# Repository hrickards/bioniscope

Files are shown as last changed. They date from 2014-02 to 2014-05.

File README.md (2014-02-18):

# Bioniscope

Open-source Bluetooth oscilloscope with an Android UI.
More information coming soon.

The project was undertaken for my A-Level Electronics coursework, so things like the writeup had to meet a certain specification and are hence pretty funky.

 * **app** --- the Android app
 * **circuit** --- Diptrace (with images & gebers) files for the circuit & PCB
 * **datasheets** --- PDF datasheets of the ICs used
 * **enclosure** --- OpenSCAD laser-cut enclosure
 * **experiments** --- brief experiments done to e.g., determine existing scope accuracies
 * **research** --- various bits of saved research into things like scope triggering
 * **simulations** --- LTSpice simulations of various parts of the circuit
 * **writeup** --- the project report needed for the A-Level

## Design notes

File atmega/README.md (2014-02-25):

# Fuses
To get a 16MHz clock using an external crystal, use CKSEL=1111, SUT=111.

To enable communication with the ADC: JTAG must be disabled! So set JTAGEN=0.

See [here](http://www.engbedded.com/fusecalc) for a great fuse calculator. The values I ended up with were L:FF, H:D9, E:FF.

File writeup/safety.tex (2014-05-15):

\documentclass[12pt,a4paper]{report}

% Custom styles
\usepackage{electronics}

% Bibliography
\usepackage[citestyle=authortitle,url=true]{biblatex}
\addbibresource{electronics.bib}

\begin{document}

When constructing the system, it is vital that all practical work is carried out
sfaely. To that end, precautions were taken against the following risks:

\begin{description}
  \item[Electrocution] No high voltage/current power supplies will be used (the
  highest voltage that may possibly be used will be \SI{15}{\volt}) so the
  danger is relatively low. Even so, appropriate precautions will be taken: the
  circuit will not be touched or modified when switched on and will not be
  placed near liquids.

  \item[Electrostatic damage] Many of the components used utilise CMOS
  technology so are very sensitive to electrostatic discharge. To minimise the
  risk of this happening, I will ground myself on a suitable surface (computer
  power supply case, grounded radiator, etc) before approaching the circuit.

  \item[Fire and/or burns] A number of components (e.g., the power supply diodes
  and chips) could potentially get extremely hot if misused. While I will
  obviously aim not to misuse them, accidents happen, and to this extent I will
  be careful and slow in touching any component in case it is hot enough to
  burn. Also, I will ensure no paper or other easily flammable materials are
  placed near the circuit.

  \item[Back injury] A number of components will need to be ordered from the
  internet, meaning they will come in large boxes. I will need to use proper
  lifting techniques when bending down and lifting these boxes to avoid back
  injury.

  \item[Cutting injuries] Throughout the course of the project I will be using
  various sharp tools, such as wire cutters. I will need to make sure I am
  trained in using these tools, that I concentrate when using them and that I
  leave them in a safe place so others do not accidentally injure themselves.
  These actions will help to reduce the risk of injuries.
\end{description}

\end{document}

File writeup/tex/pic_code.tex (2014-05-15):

\chapter{PIC Code}
\label{sec:picProgramCode}

\inputminted{c}{code/main.c} \newpage
\inputminted{c}{code/Global.c} \newpage
\inputminted{c}{code/Command.c} \newpage
\inputminted{c}{code/Debugger.c} \newpage
\inputminted{c}{code/BTUSART.c} \newpage
\inputminted{c}{code/USBUSART.c} \newpage
\inputminted{c}{code/Sampler.c} \newpage
\inputminted{c}{code/ADC.c} \newpage
\inputminted{c}{code/Pots.c} \newpage
\inputminted{c}{code/SPI.c} \newpage

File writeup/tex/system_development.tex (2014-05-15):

\chapter{System Development}
\section{Subsystems}
\label{sec:subsystems}

The system will be split up into a number of subsystems, shown
in~\cref{fig:subsystems}. Each of these subsystems is described in more detail
in the sections below, and a brief description is given immediately below.

\begin{itemize}

  \item Two analogue input channels come into the system, and are amplified and
  offset by amplification circuitry (with the gain controlled by a central
  microcontroller).

  \item These channels are both sampled using an Analogue to Digital Converter,
  which feeds into the microcontroller.

  \item A number of digital inputs are also fed straight into the
  microcontroller

  \item Through a Bluetooth transceiver, an Android device interacts with the
  microcontroller, receiving samples of both the analogue and digital inputs and
  controlling things such as the sampling rate and amplifier gain.

\end{itemize}

\begin{landscape}
  \begin{figure}
    \scalebox{0.8}{
      \begin{tikzpicture}
        \node [io] (input1) {Input 1};
        \node [io, below of=input1, node distance=3cm] (input2) {Input 2};

        \node [process, right of=input1] (amp1) {Amplifier};
        \node [process, right of=input2] (amp2) {Amplifier};
        \path [arrow] (input1) -- (amp1);
        \path [arrow] (input2) -- (amp2);
        \coordinate [below of=amp1, node distance=1.5cm] (centreamp);

        \node [process, right of=centreamp] (adc) {ADC};
        \path [arrow] (amp1) -| (adc);
        \path [arrow] (amp2) -| (adc);

        \node [process, right of=adc] (microcontroller) {Microcontroller};
        \path [barrow] (adc) -- (microcontroller);

        \node [process, below=2.5cm of microcontroller.320] (inputdigital) {Digital Inputs};
        \path [arrow] (inputdigital) -- (microcontroller.320);

        \node [process, right of=microcontroller] (wifi) {Bluetooth Transceiver};
        \node [io, right of=wifi, node distance=5.5cm, text width=4.5em] (frontend) {User Interface};
        \path [barrow] (microcontroller) -- (wifi);
        \path [bdarrow] (wifi) -- (frontend);

        \coordinate[above of=amp1, node distance=2cm] (aboveamp1);
        \coordinate[below of=amp2, node distance=1.5cm] (belowamp2);
        \path [arrow] (microcontroller) |- (aboveamp1) -- (amp1);
        \path [arrow] (microcontroller.220) |- (belowamp2) -- (amp2);
      \end{tikzpicture}
    }
    \caption[Oscilloscope Subsystems]{Subsystems within the oscilloscope}
    \label{fig:subsystems}
  \end{figure}
\end{landscape}

\subsection{Analogue Inputs}

For the purposes of this project wires are sufficient, however in a real-life
scenario high-impedance, low-inductance test probes (usually coaxial cable)
should be used.

\subsection{Power Supply}

\subsubsection*{Requirements}

While it is not explicitly shown in~\cref{fig:subsystems}, the amplifiers, ADC,
microcontroller and Bluetooth transceiver will all need to be powered.

A \SI{5}{\V} rail will be needed that can source the following
current\footnote{The figures are overestimations meaning there will
definitely be enough current available.}:
\begin{itemize}
  \item \SI{5}{\mA} for the two amplifiers combined
  \item \SI{5}{\mA} for the two digital potentiometers combined
  \item \SI{15}{\mA} for the ADC
  \item \SI{25}{\mA} for the microcontroller
  \item \SI{30}{\mA} for the LED
  \item \SI{30}{\mA} for the Bluetooth module
\end{itemize}
which gives a total of \SI{110}{\mA}.

Similarly, a \SI{-5}{\V} rail will be needed for the first-stage amplifier that
can sink at least \SI{5}{\mA}, and a ground rail will be needed that can sink
at least \SI{110}{\mA}\footnote{There will always be a positive load, so we do
  not need to worry about the ground rail being able to source the \SI{5}{\mA}
that will flow to the \SI{-5}{\V} rail}.

\subsubsection*{Circuit}

While researching this part of the circuit, your author came upon a chip known
as an \textit{inverting charge pump}, a device that takes $V_s$ and \SI{0}{\V}
as inputs and outputs $-V_s$ and \SI{0}{\V} as outputs\footnote{The way it does
this is complicated, but revolves around charging up a capacitor in one
direction and then discharging it in the opposite direction.} --- essentially
providing a low-current\footnote{The highest commonly-available current rating
seems to be about \SI{1}{\A}} dual power supply. This was implemented into the
oscilloscope's power supply as it means only a positive voltage and ground need
to be input, meaning it could potentially be powered by battery.

Many of the chips (primarily the ADC and microcontroller) require very precise
and stable power rails, and to that effect a voltage regulator will be used.
Commonly known as a 7805 (although that specific device will not be used in this
case), a voltage regulator takes a relatively high voltage (e.g., \SI{9}{\V}) as
input and outputs a very precise lower voltage (e.g., \SI{5}{\V}) that does not
fluctuate even when the output current changes rapidly. In addition to this,
decoupling capacitors will be added to the amplifier, ADC and microcontroller to
further reduce voltage fluctuations (the capacitor values will be taken directly
from the relevant datasheets).

\begin{landscape}
  \begin{figure}[h]
    
    \caption{Power supply circuit diagram}
    \label{fig:powerSupplyDiagram}
  \end{figure}
\end{landscape}

These two ideas, then, give rise to the circuit diagram shown
in~\cref{fig:powerSupplyDiagram}. A single-rail power supply (perhaps from a
\SI{9}{\V} battery) is used to power the system, and a switch (to let the user
switch the oscilloscope off and on) and a forward-biased diode (to limit damage
if the power supply is connected backwards) are connected immediately to the
power rail.

A MAX883 chip is then used as a fixed \SI{5}{\V} voltage regulator. Most
semiconductor companies produce PDIP package \SI{5}{\V} voltage regulators, but
Maxim Integrated's chip was chosen due the availability of free samples. As
specified in the datasheet, a \SI{100}{\nF} capacitor is placed on the input and
a \SI{2.2}{\uF} capacitor on the output.

A MAX660 is then used as an inverting charge pump (this specific chip was chosen
for similar reasons to the MAX883). Again, as specified on the datasheet a
\SI{22}{\uF} capacitor is placed on the output and another between $CAP-$ and
$CAP+$.

\subsection{Amplifiers}

Each amplifier will have two purposes:
\begin{itemize}
  \item To amplify the signal based on the Voltage Control of the oscilloscope.
    This is needed so the user can input a range of different voltage signals.

  \item To shift the signal so the minimum voltage is \SI{0}{\volt}, rather
    than some negative voltage. This is required because the ADC will only
    accept an input greater than \SI{0}{\volt}.
\end{itemize}

The chosen ADCs require an input voltage between \SI{0}{\volt} and
\SI{5}{\volt}\footnote{The maximum voltage is actually $V_{REF+}$, which will be
connected to $V_{CC}$ for simplicity, which in this case is \SI{5}{\volt}}. A
non-inverting summing amplifier would not be suitable beause the offset added to
the signal needs to remain constant while the gain changes, so instead the
amplifier will be split into two stages.

The first stage will amplify the signal and offset it to be between
\SI{0}{\volt} and \SI{-5}{\volt}, below which the op-amp will saturate.

The second stage will invert this signal with a voltage gain of $-1$, meaning
the output voltage will be between \SI{0}{\volt} and \SI{5}{\volt} as required.

\subsubsection{First Stage}

\paragraph{Circuit}
This stage will be implemented using a summing amplifier, with the inputs
consisting of the input signal and a fixed voltage (for the sake of simplicity,
the 5V supply wil be used).

See~\cref{fig:first_stage_amplifier_circuit} for a circuit diagram.

\paragraph{Component Calculations}

Suppose that the input signal varies from $-V_1$ to $+V_1$, and the amplifier
has a gain of $A$ and an offset of $B$. Then the output voltage $V_o$ will be
given by

\begin{equation*}
  -V_o = \frac{R_f}{R_1} V_i + \frac{R_f}{R_2} \cdot \SI{5}{\volt}
\end{equation*}

The first term will range from $-A\cdot V_1$ to $+A\cdot V_1$, and the second
term will be $B$. So $-V_o$ will range from $B-A\cdot V_1$ to $B+A\cdot V_1$.
Choosing a value of $B=\SI{2.5}{\volt}$ means that $-V_o$ will vary equally
above and below \SI{2.5}{\volt}, as we want\footnote{The op amp will saturate
before outputting a voltage above \SI{5}{\volt}, so we don't need to worry about
this. If the gain or input voltage is sufficiently large, $-V_o$ could fall
below \SI{0}{\volt}. This means the next stage must saturate at $\SI{0}{\volt}$
and not output negative voltages, whatever the input.  }(because the voltage
must be between \SI{0}{\volt} and \SI{5}{\volt}, and \SI{2.5}{\volt} is the
midpoint of those two).

$R_f$ and $R_2$ will be fixed to give $\frac{R_f}{R_2}=0.5$ to get the required
offset. $R_1$ will be a digital potentiometer acting as a rheostate (variable
resistor), allowing the microcontroller to control the gain of the amplifier.

The input voltage range is from \SI{\pm 50}{\mV} to \SI{\pm 5}{\V}, so the gain
$A=\frac{R_f}{R_1}$ must vary from 0.5 to at least 50.  Digital potentiometers
are readily available in a number of values, so the standard \SI{10}{\kilo\ohm}
option will be chosen. This means the potentiometer can vary from the minimum
resistance (usually \SI{75}{\ohm}) to \SI{10}{\kilo\ohm}.

Using the values for $A$ and $R_1$, this gives a value of
$R_f=\SI{5}{\kilo\ohm}$, meaning $A$ will range from
$\frac{\SI{5}{\kilo\ohm}}{\SI{10}{\kilo\ohm}}=0.5$ to
$\frac{\SI{5}{\kilo\ohm}}{\SI{75}{\ohm}} \approx 66.7$, as required.  In turn,
this gives a value of $R_2 = \SI{10}{\kilo\ohm}$.

\begin{figure}[ht]
  \begin{circuitikz}[european]
    % Inputs and input resistors
    \node (vin1) {};
    \node (vin2) [below=1 of vin1] {};
    \node (rpoint1) [right=2.5 of vin1] {};
    \node (rpoint2) [right=2.5 of vin2] {};
    \coordinate (middlevin1vin2) at ($(vin1)!0.5!(vin2)$);
    \node (rpoint) at (rpoint1|- middlevin1vin2) {};

    \draw (vin1) to[R, l=$R_2\equal\SI{10}{\kilo\ohm}$] (rpoint1);
    \draw (rpoint2) to[pR, l_=$R_1 \in \lb\SI{75}{\ohm}\comma
    \SI{10}{\kilo\ohm}\rb$, label/align=rotate, -o] (vin2) node [anchor=east]{$V_{in}$};
    \draw (rpoint1) to[short] (rpoint);
    \draw (rpoint2) to[short] (rpoint);
    \node [circ] (crpoint) at (rpoint) {};

    % Op amp and feedback resistor
    \node (rfpoint) [right=1 of rpoint] {};
    \node[op amp](oa) [right=0.5 of rfpoint] {};
    \node (aboverfpoint) [above=1.5 of rfpoint] {};
    \node (2xaboverfpoint) [above=1.5 of aboverfpoint] {};
    \node (aboveoaout) at (oa.out|- aboverfpoint) {};
    \node[ground](gnd) [below=0.5 of rfpoint,anchor=center] {};
    \node (vo) [right=1 of oa.out] {};

    \draw (rpoint) to[short] (rfpoint);
    \draw (rfpoint) to[short] (aboverfpoint);
    \draw (aboverfpoint) to[R=$R_f\equal\SI{5}{\kilo\ohm}$] (aboveoaout);
    \draw (aboveoaout) to[short] (oa.out);
    \node [circ] (crfpoint) at (rfpoint|- oa.-) {};

    \draw (rfpoint) |- (oa.-);
    \draw (gnd) |- (oa.+);
    \draw (oa.out) to[short] (vo) node [anchor=west] {$V_{out}$};

    % 5V rail
    \node (leftofvin1) [left=0.5 of vin1] {};
    \node (5vraill) at (leftofvin1|- 2xaboverfpoint) {};
    \node (5vrailr) [right=3 of 5vraill] {};
    \node (5vrailm) at (vin1|- 5vraill) {};

    \draw (5vraill) to[short] (5vrailr) node [anchor=west] {$\SI{5}{\volt}$};
    \draw (5vrailm) to[short] (vin1);
  \end{circuitikz}
  \caption[1\ts{st} Amplifier Stage]{First stage amplifier circuit diagram}
  \label{fig:first_stage_amplifier_circuit}
\end{figure}

\paragraph{Component Selection}

The Microchip MCP4131-103E/P will be used for the digital potentiometer. It
offers enough precision (typically 0.25\%), offers a simple interface for
changing the resistance (SPI) and is cheap and readily available in a PDIP
package. Additionally, free samples are available from Microchip. To make the
component calculations made earlier work, the \SI{10}{\kilo\ohm} MCP4131-103
variety will be used.

The op-amps should be of rail-to-rail type (i.e. they can saturate at almost 0V
and $V_s$) and be able to cope with $V_s=\SI{5}{\volt}$, $V_i=\SI{5}{\volt}$ and
input frequencies of up to $\SI{1}{\MHz}$. The Analog Devices AD8031 meets all
of these requirements (at $\SI{1}{\MHz}$ it gives an open-loop gain of almost
$\SI{25}{\decibel}$) and is also cheap and readily available in PDIP packaging.
Due to the availability of free samples, 2 AD8032ANZs (consisting of two AD8031
op amps in each chip) will be used.

\subsubsection{Second Stage}
This stage simply has to invert the previous stage, saturating at \SI{0}{\volt}
and \SI{5}{\volt}. For this we can use a simple inverting amplifier.

\begin{equation*}
V_{out}=\frac{R_f}{R_1}V_{in}
\end{equation*}

Choosing a standard value of $R_f=\SI{10}{\kilo\ohm}$, we obtain
$R_1=\SI{10}{\kilo\ohm}$.

As detailed in the previous section, AD8031 op amps will be used.

See~\cref{fig:second_stage_amplifier_circuit} for a circuit diagram.

\begin{figure}[ht]
  \begin{circuitikz}[european]
    \node (vin) {};
    \node (rpoint) [right=2.5 of vin] {};
    \node [op amp] (oa) [right=0.5 of rpoint] {};
    \node (aboverpoint) [above=1.5 of rpoint] {};
    \node (aboveoaout) at (oa.out |- aboverpoint) {};
    \node [ground] (gnd) [below=0.5 of rpoint, anchor=center] {};
    \node (vo) [right=1 of oa.out] {};

    \draw (rpoint) to[R, l_=$R_1\equal\SI{10}{\kilo\ohm}$] (vin) node
      [anchor=east] {$V_{in}$};
    \node [circ] (crpoint) at (rpoint|- oa.-) {};
    \draw (rpoint) to[short] (aboverpoint);
    \draw (aboverpoint) to [R=$R_f\equal\SI{10}{\kilo\ohm}$] (aboveoaout);
    \draw (aboveoaout) to[short] (oa.out);
    \draw (rpoint) |- (oa.-);
    \draw (gnd) |- (oa.+);
    \draw (oa.out) to[short] (vo) node [anchor=west] {$V_{out}$};
  \end{circuitikz}
  \caption[2\ts{nd} Amplifier Stage]{Second stage amplifier circuit diagram}
  \label{fig:second_stage_amplifier_circuit}
\end{figure}

\subsubsection{Simulation}
To check the frequency response of the amplification circuit, it was simulated
using LTSpice (see~\cref{fig:amp_sim:circuit}).

To test the simulation, a low frequency sine wave was applied, and as expected
the output was a sine wave of amplitude \SI{2.5}{\volt} between \SI{0}{\volt}
and \SI{2.5}{\volt}. The resultant waveform can be seen
in~\cref{fig:amp_sim:waveform}. A FFT was then applied to this waveform to
obtain the frequency spectrums seen in~\cref{fig:amp_sim:fft}. As required, the
spectrum of the output was identical to the spectrum of the input, with the
slightly lower amplitudes being due to a lower wave amplitude (\SI{2.5}{\volt}
c.f. \SI{5}{\volt}).

A frequency sweep was then applied to produce a Bode plot. The details of such a
plot are beyond the scope of this project, but let us just note that the gain is
very consistent across all frequencies we'll be using (as predicted: the op amp
has a stated bandwidth of \SI{80}{\MHz}, much higher than \SI{1}{\MHz}), and
while it becomes almost \SI{9}{\degree} out of phase at very high frequencies,
this is not an issue for this project\footnote{The phase is only important to
the oscilloscope when comparing the phase of two signals. To see two signals on
screen at the same time base, their frequencies must be close enough together
that they're both out of phase by approximately the same amount. Hence their
phase difference is unchanged}.

\begin{figure}[ht]
  
  \caption[Amplification Circuit Simulation]{Amplification circuit in LTSpice}
  \label{fig:amp_sim:circuit}
\end{figure}

\begin{landscape}
  \begin{figure}[ht]
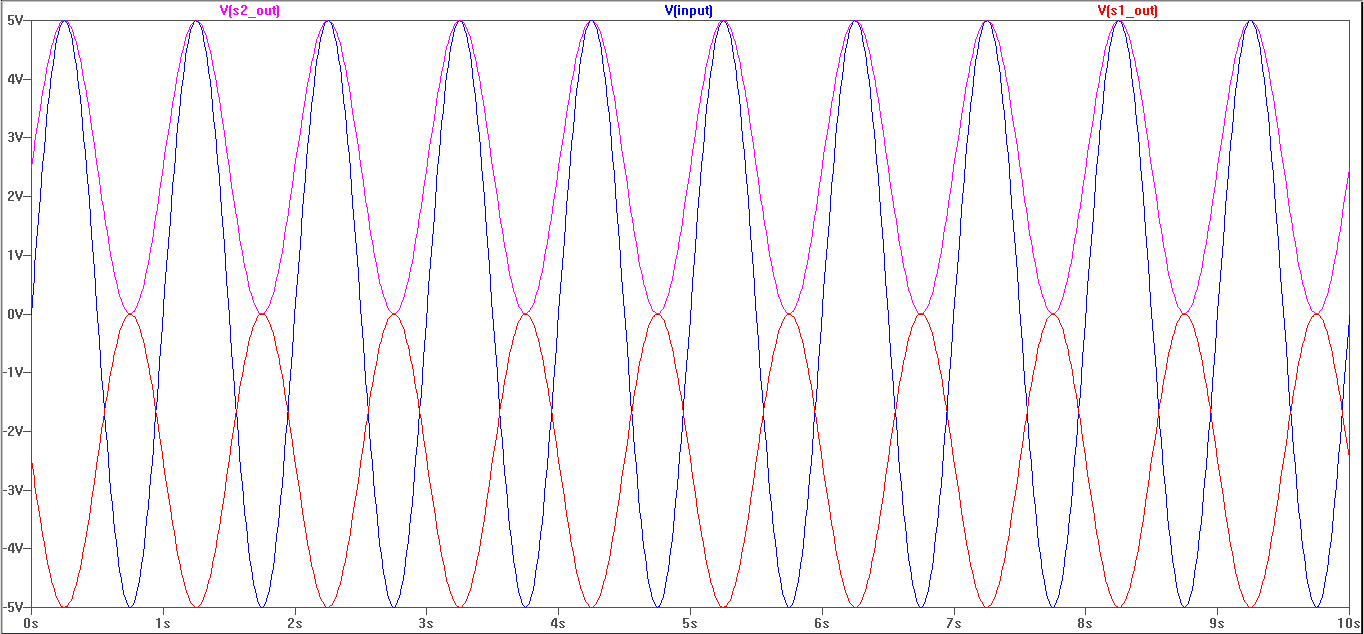
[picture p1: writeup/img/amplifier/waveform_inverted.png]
    
    \caption[Amplification Circuit Waveform]{Waveform produced by amplification circuit at 1Hz (blue = original,
      red = first stage output, magenta = second stage output)}
    \label{fig:amp_sim:waveform}
  \end{figure}
\end{landscape}

\begin{landscape}
  \begin{figure}[ht]
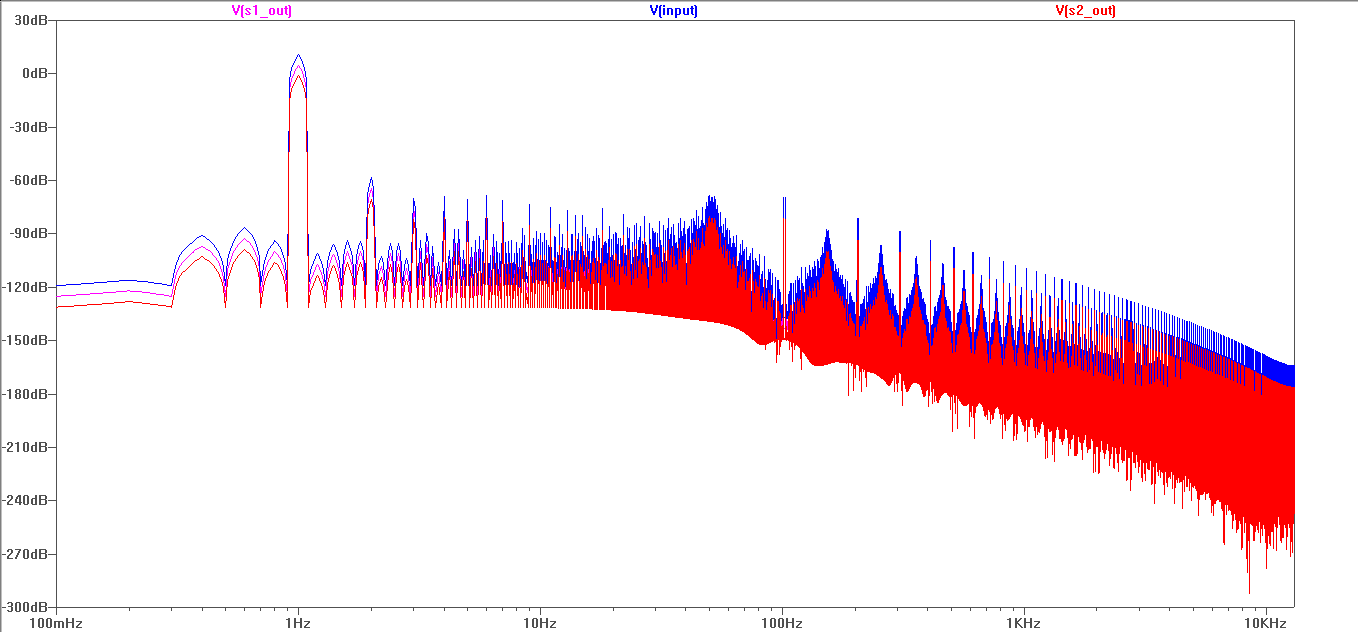
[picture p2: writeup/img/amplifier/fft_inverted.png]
    
    \caption[Amplification Circuit Frequency Spectrum]{FFT of waveform produced by amplification circuit at 1Hz (red =
      original, blue = first stage output, magenta = second stage output)}
    \label{fig:amp_sim:fft}
  \end{figure}
\end{landscape}

\begin{landscape}
  \begin{figure}[ht]
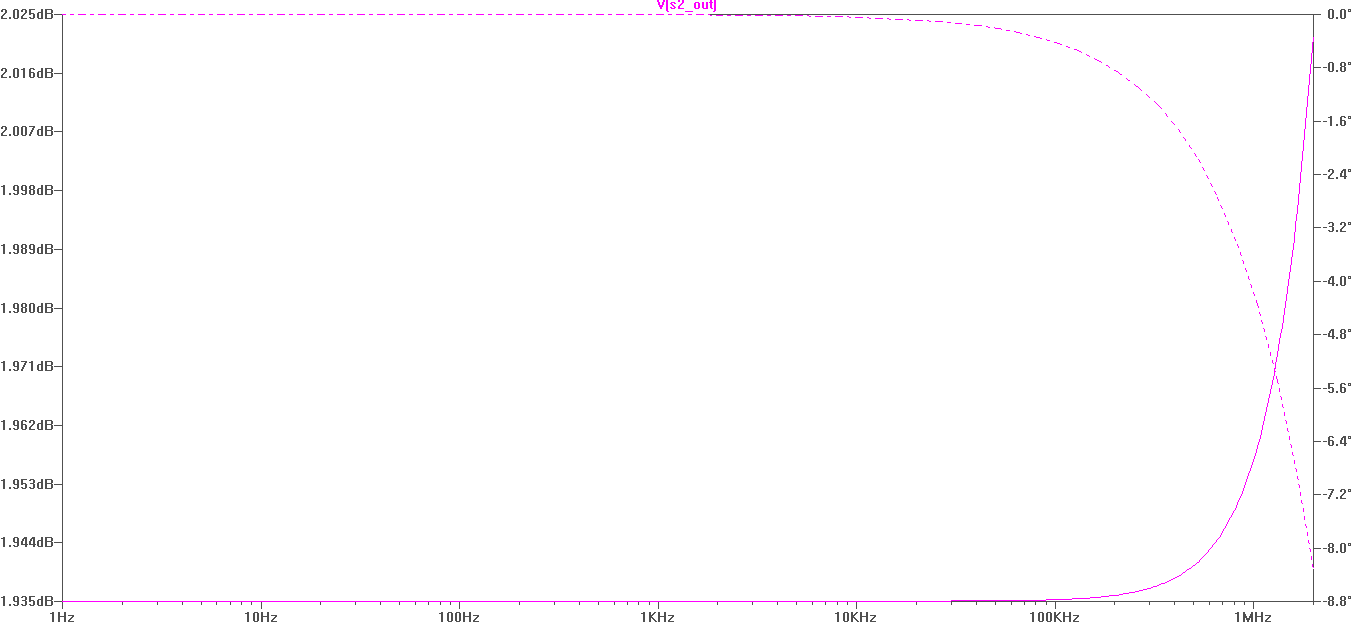
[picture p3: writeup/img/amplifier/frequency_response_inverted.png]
    
    \caption[Amplification Circuit Bode Plot]{Frequency response of amplification circuit}
    \label{fig:amp_sim:freq_response}
  \end{figure}
\end{landscape}

\subsubsection{Overall Circuit}

See~\cref{fig:ampCircuitDiagram} for an overall circuit diagram.

\begin{figure}[h]
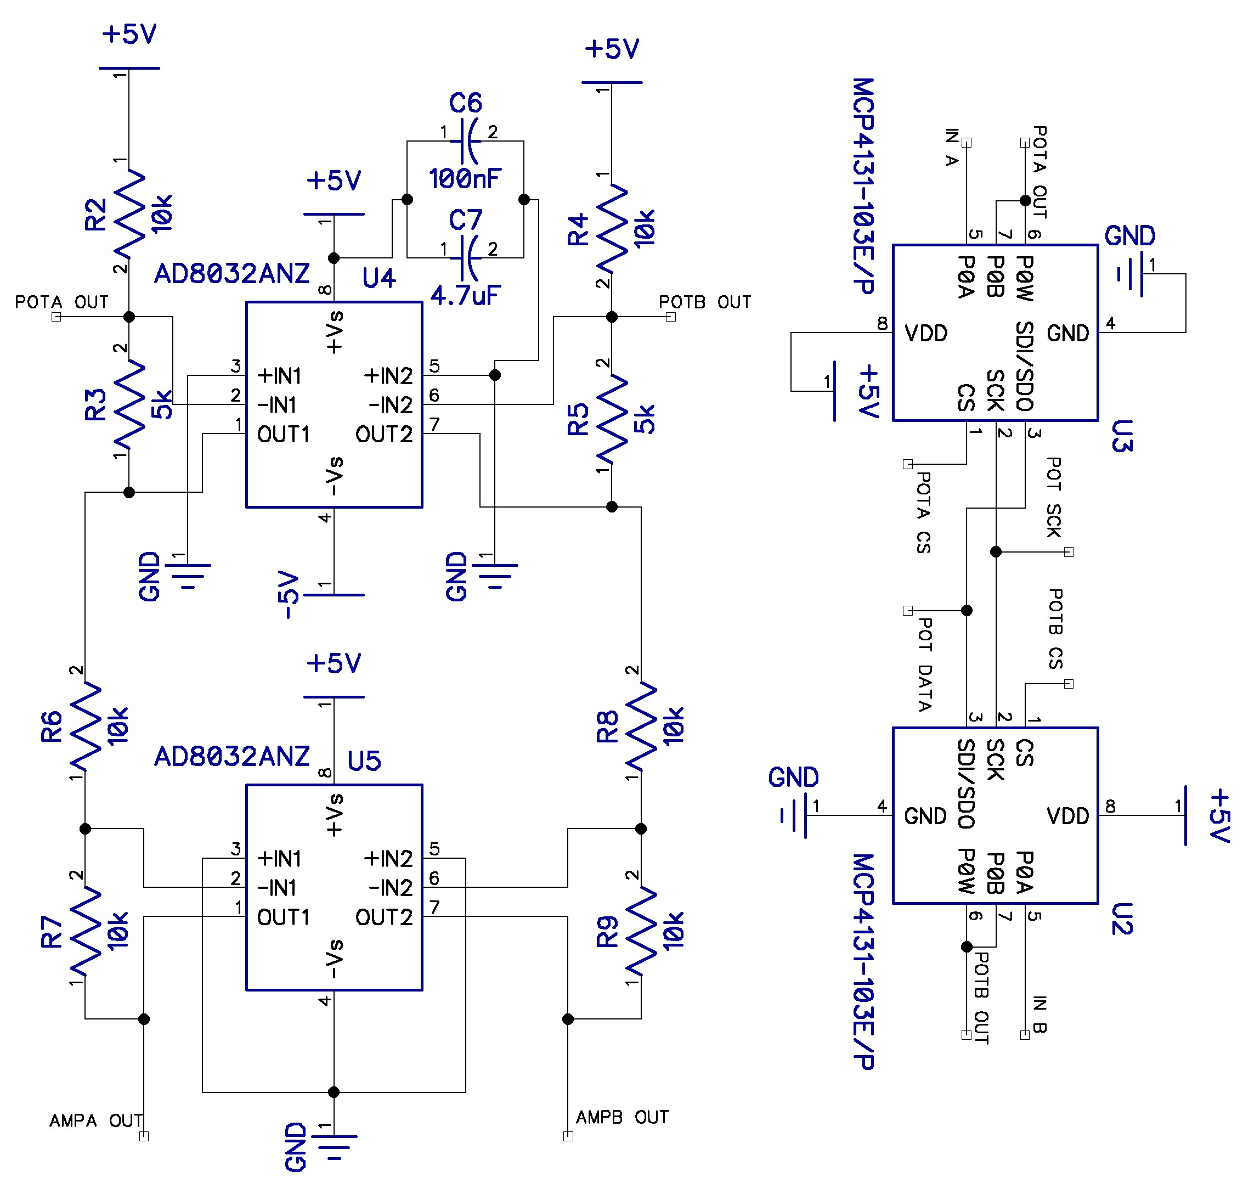
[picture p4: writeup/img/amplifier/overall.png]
  
  \caption[Amplifier circuit diagram]{Circuit diagram of complete amplifier}
  \label{fig:ampCircuitDiagram}
\end{figure}

\subsection{ADCs}
\label{sec:adcs}

As discussed before, these should be able to sample at up to $\SI{1}{\MHz}$. The
only readily available ADCs that can do this in PDIP packaging and have free
samples are the 8-bit half-flash\footnote{Similar to flash ADCs, but requiring
$\approx2^{\frac{n}{2}}$ as opposed to $\approx 2^n$ parts} Maxim Integrated
MAX114 ADCs.

There are a number of modes the ADCs can be operated in, however the pipelined
mode offers a very good compromise between complexity and speed. The full
details are in \textcite{MAX114}, but as the ADCs are operated from a
microcontroller in which there's a delay of \SI{62.5}{\ns} (assuming a
\SI{16}{\MHz} clock) between each instruction, the operating procedure can be
simplified to the following:

\begin{enumerate}
  \item Use $A_0$ and $A_1$ to choose the input signal (there are only two
    inputs in this project, so $A_0$ and $A_1$ are connected together meaning a
    logic $0$ selects input 0 and a logic $1$ selects input 3)
  \item Pull $\overline{CS}$, $\overline{RD}$ and $\overline{WR}$
  \item Wait approximately \SI{250}{\ns}
  \item Pull $\overline{CS}$, $\overline{RD}$ and $\overline{WR}$ back high
  \item Read in a sample from $D_0$ through $D_7$
\end{enumerate}

Taken directly from the datasheet, \cref{fig:MAX114Power} shows the connections
that must be made to power the MAX114 and provide it with a reference voltage.

Additionally, $\overline{PWRDN}$ must be kept high to keep the ADC powered on,
and $MODE$ must be kept high to keep the ADC in Read-Write mode (of which
pipeline mode is a subset). Both of these should be pulled high through a
resistor (\SI{3.3}{\kilo\ohm} being a common value) to limit current. Based on
this,~\cref{fig:adcCircuitDiagram} shows the circuit schematic for the ADC.

\begin{figure}[h]
  
  \label{fig:adcCircuitDiagram}
  \caption[ADC Circuit Diagram]{Diagram showing how ADC will be connected}
\end{figure}

\begin{figure}
  \centering
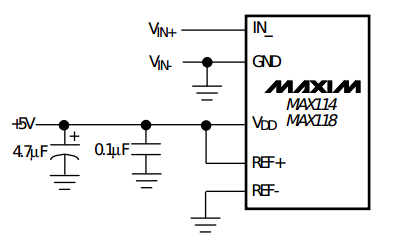
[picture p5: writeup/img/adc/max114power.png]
  
  \label{fig:MAX114Power}
  \caption[ADC Power Connections]{Power connections for the MAX114~\autocite{MAX114}}
\end{figure}

\subsection{Microcontroller}

Due to this author's significant previous experience with AVR microcontrollers,
one will be used as there are no significant disadvantages over a PIC. In
addition, it is easier to obtain free samples from Atmel (the company that
produce AVR microcontrollers) than it is from Microchip (the company that make
PICs). The main requirements the microcontroller needs to satisfy are:

\begin{itemize}
  \item Ability to use a \SI{16}{\MHz} clock
  \item Inbuilt UART communication (to communicate with the Bluetooth module)
  \item At least 32 IO pins:
    \begin{itemize}
      \item 8 for data connections to the ADC
      \item 5 for control connections to the ADC
      \item 8 for digital data inputs
      \item 4 ($DATA$, $SCK$ and two $CS$) for digital potentiometer
        communication
      \item 2 ($RX$ and $TX$) for Bluetooth module communication
      \item 2 ($RX$ and $TX$) for USB module communication (for debugging
        purposes\footnote{While in theory the Bluetooth module should just be
          plug and play, a spare CP2102 USB to USART module will be used to
          allow the microcontroller to talk to a laptop over USB to help fix any
          problems that occur in the prototyping process}).
      \item 3 for ISP header (the connections used to program the AVR)
    \end{itemize}
  \item At least \SI{1}{\kilo byte} of SRAM (to store the 8192 bits of samples)
  \item Availability in a PDIP package
\end{itemize}

The ATMega1284P was chosen because it's the only 8-bit AVR that meets the above
criteria (any AVRs with more than 32 IO pins are not available in PDIP
packages)!

\subsubsection{Circuit}

\begin{figure}[h]
  
  \caption[Microcontroller Circuit Diagram]{Circuit diagram showing connections to the microcontroller}
  \label{fig:microcontrollerCircuitDiagram}
\end{figure}

For the chip to operate, a \SI{16}{\MHz} crystal oscillator must be connected
between $XTAL1$ and $XTAL$, with a \SI{22}{\pF} capacitor from each pin to
ground.

The following power connections must also be made:
\begin{itemize}
  \item Both $GND$s to ground
  \item $V_{CC}$ and $AV_{CC}$ to \SI{5}{\volt}, with a \SI{100}{\nF} and \SI{1}{\uF}
    capacitor in parallel down to ground (acting as decoupling capacitors)
\end{itemize}

$PD0$ and $PD1$ (in their role as $RXD0$ and $TXD0$ for the chip's inbuilt UART
communication) must be connected to $RX$ and $TX$ respectively on the USB to
UART module\footnote{The module labels $RX$ such that it should be connected to
$RX$ on the microcontroller}.

Similarly, $PD2$ and $PD3$ (in their role as $RXD1$ and $TXD1$ for the inbuilt
UART) must be connected to $TX$ and $RX$ respectively on the Bluetooth
module\footnote{Opposite to the USB module, the Bluetooth module labels $RX$
such that it should be connected to $TX$ on the microcontroller}.

$PB5$, $PB6$ and $PB7$ (in their roles as $MOSI$, $MISO$ and $SCK$ in the chip's
programming connections) should be connected to $MOSI$, $MISO$ and $SCK$
respectively on the ISP (programming) header. The $V_{CC}$ and $GND$ on the
programming header should also be connected to $V_{CC}$ and $GND$ on the chip.

$RESET$ (an active-low input that restarts the microcontroller) should be
connected to $V_{CC}$ through a \SI{4.7}{\kilo\ohm} resistor, with a
\SI{10}{\nF} decoupling capacitor down to ground. It should also be connected to
$RESET$ on the ISP header (when programming the microcontroller, the computer
will need to reset it) and through a switch down to ground (to allow the user to
restart the microcontroller if necessary).

Bus A (i.e., $PA0$ through $PA7$) will be connected directly to the digital
inputs, and bus C (i.e., $PC0$ through $PC7$) will be connected to the data
outputs ($D0$ through $D7$ of the ADC). The ADC control lines will be connected
to the unused pins on bus B: $WR$ to $PB0$, $CS$ to $PB1$, $INT$ to $PB2$,
$ADDR$ to $PB3$ and $RD$ to $PB4$.

Finally, the digital potentiometers will be connected to the unused pins on bus
D: $DATA$ to $PD4$, $SCK$ to $PD5$ and the two $CS$s to $PD6$ and $PD7$.

All of these connections are shown visually
in~\cref{fig:microcontrollerCircuitDiagram}.

\subsubsection{Programming}

To program the chip, an AVR programmer must be used (and connected to the ISP
header as detailed above). As this author already had a USBASP programmer
(approximately \pounds 5 from eBay), this was used. Alternatively, an Arduino (a
very popular microcontroller prototyping board) can be connected to program AVR
chips.

\subsubsection{Serial Interface}

The Android device and the microcontroller will communicate via Bluetooth, which
will emulate a serial link. In essence, a form of communication will be
established where sequences of bytes can be sent by both devices simeltanousely.

The following protocol\footnote{The commands are given sequential bytes, however
some bytes are skipped because a number of command bytes were used solely in the
prototyping phase} was designed for serial communication between the Android
device and the microcontroller. After taking a full 1024 samples, the
microcontroller checks the serial buffer for one of the following commands and
acts on it, responding via serial if necessary.

Traditionally, serial is a textual interface, however for efficiency's sake in
this case it was used as a binary interface. Each transmitted character is
stored as an 8-bit character, so the protocol is based on the integer values of
those characters. For example, 65 below corresponds to a capital `A'.

\begin{description}

  \item[\texttt{0x00}] Return all samples for the first analogue channel (1024
  bytes, followed by a newline.\footnote{The character used to indicate a new
  line should start in text on a computer. Here, it's just equivalent to
  \texttt{0x0A}})

  \item[\texttt{0x01}] Return all samples for the second analogue channel (1024
  bytes, followed by a newline)

  \item[\texttt{0x02}] Return all digital samples (1024 bytes, with each byte
    representing all 8 samples at one timepoint, followed by a newline)

  \item[\texttt{0x06}] Wait for the next two transmitted bytes, $X$ and $Y$ and
  use $XY$\footnote{For example, if $X = \texttt{0x50}$ and $Y=\texttt{0x1A}$
  then use \texttt{0x501A} as the delay} as the number of microseconds to pause
  in between digital samples (returns a newline)

  \item[\texttt{0x08}] Wait for the next transmitted byte, $X$, and use the 7
  least significant bits of $X$ as the digital pot value in an amplifier (if the
  most significant bit of $X$ is high, the second amplifier circuit, otherwise
  the first amplifier circuit) (returns a newline)

  \item[\texttt{0x09}] Toggle the status of analogue channels 1 and 2, based on
    the first and second LSBs in the next transmitted byte $X$ (returns a
    newline)

  \item[\texttt{0x0A}] Noop (this is the newline character) (returns a newline)

  \item[\texttt{0x0C}] Return the current digital time delay (returns two bytes
    then a newline)

  \item[\texttt{0x11}] Set the time delay between analogue samples based on the
    next two transmitted bytes $X$ and $Y$ (returns a newline)

  \item[\texttt{0x12}] Return the current analogue time delay (returns two bytes
    then a newline)

\end{description}

So, for example, to receive samples for the second analogue channel the Android
device would have to send \texttt{0x01}, then store the next 1024 received bytes.

\subsubsection{ADC Communication}
The way in which the microcontroller will communicate with the ADC is described
in~\cref{sec:adcs}. Note that while $INT$ is not required for communication, it
is connected as an input to the microcontroller in case the communication
protocol is changed (i.e., a different mode is used over pipelined) during the
prototyping process.

\subsubsection{Digital Potentiometer Commmunication}

The resistance of the digital potentiometers is set using an SPI interface.
While the details can get more complicated, SPI (Serial Peripheral Interface) is
essentially a very simple interface, consisting of four pins: $SCLK$, $MOSI$,
$MISO$ and $\overline{SS}$.

There are two devices: a master and a slave. $SCLK$ is simply a clock output
from master. On either the rising or falling edge of $SCLK$, a bit of data is
transmitted from master to slave on $MOSI$ and slave to master on $MISO$.
$\overline{SS}$ is simply an active low slave select (i.e. the slave only
communicates when $\overline{SS}$ is low).

There are four different SPI modes, of which the digital potentiometers support
two ($CPOL=0=CPHA$ and $CPOL=1=CPHA$). In both modes, data is captured on the
rising edge and propogated on the falling edge. The difference is simply the
first value of the clock: in the first mode, it's low, and in the second it's
high.

The maximum clock supported by the digital potentiomers is \SI{10}{\MHz}, which
is faster than we can reliably communicate at with a \SI{16}{\MHz}
microcontroller anyway.

To send a 16-bit byte to the digital potentiometer the following must be done:
\begin{enumerate}
  \item Pull $\overline{SS}$ low
  \item Wait one $SCLK$ period
  \item Starting from a high (an artbitrary choice), pulse $SCLK$
  \item On each falling edge, send a bit of data until 16 bits have been sent
  \item Pull $SCLK$ back high
  \item Wait one clock period
  \item Pull $\overline{SS}$ back high
\end{enumerate}

The potentiometer has 128 resistance levels that can be chosen from (with 0
being \SI{75}{\ohm} and 127 being \SI{10}{\kilo\ohm}). Suppose we want to set
the resistance to a level $x \in \mathopen[0,127\mathclose]$. Then let $P$ be
the 7-bit binary number representing $x$. To set the resistance to $x$, we write
9 zeroes followed by $P$.

As detailed in the serial protocol above, the Android device sends a byte $B$,
where the MSB determines which potentiometer to change the the 7 LSB determine
the value to send. To determine the address from this we can run

\mint{c}/Byte address = (control & 0x80) ? 0x01: 0x00;/

to set $address$ to the MSB of control. Similarly, we can set the value by
getting the 7 LSB using

\mint{c}/Byte level = control & 0x7F;/

\subsubsection{Program}
To perform all of the above tasks, then, the microcontroller will need to run
the following program:

\begin{itemize}
  \item Setup serial communication (Bluetooth)
  \item Setup potentiometer SPI communicator
  \item Setup ADC communication and initialise data variables
  \item Loop forever:
    \begin{itemize}
      \item Loop 1024 times:
        \begin{itemize}
          \item Take sample from first analogue channel, if enabled
          \item Take sample from second analogue channel, if enabled
          \item Take 1-bit sample from each digital channel
        \end{itemize}
      \item Look at the most recent serial command, receive up to 2 more bytes
        depending on the command, and perform any actions and send any data it
        specifies
      \item Clear most recent serial command
    \end{itemize}
\end{itemize}

ISRs will not be used for serial communication as an oscilloscope is heavily
reliant on accurate timing --- something that ISRs will interrupt.

There are two main programming languages that can be used for AVR
microcontrollers: Assembly and C. While Assembly was taught in the course, your
author has more extensive previous personal experience using C to program
microcontrollers. Additionally, the higher level of C means less code will be
needed to obtain the same result, and that code wil be more logically
structured. Furthermore, modern C compilers can optimise C code to a smaller
amount of Assembly than any human programmer, meaning the only reason to use
Assembly is for educational purposes.

The completed PIC program can be seen in~\cref{sec:picProgramCode}.

\subsection{Bluetooth Transceiver}
\label{sec:wireless_transceiver}

As discussed in~\cref{sec:CommOptions}, Bluetooth was chosen to communicate with
the Android device acting as the user interface. In particular, the JY-MCU HC-06
was chosen.

This communicates with the microcontroller via the inbuilt UART interface, as
illustrated in the code in~\cref{lst:uartExample}.

\begin{listing}[H]
  \inputminted{c}{code/USART.c}
  \caption{Example code used to communicate over Bluetooth via the USART
  interface}
  \label{lst:uartExample}
\end{listing}

\subsection{User Interface}
\label{sec:user_interface}

A high-quality enough screen that interfaced directly with the microcontroller
would be quite expensive, so instead an Android device was chosen as the user
interface.

Android was chosen over the alternatives (iOS, etc) primarily because it's the
most popular mobile operating system, allowing the greatest number of people to
use the oscilliscope. Additionally, it allows easy and open development, whereas
competitors such as iOS require costly developer licenses, proprietary software
and specific hardware.

As it's by far the most common and most supported language used for Android,
Java was used to create an Android application that interfaced with the
oscilloscope. Discussing the development of this application is far beyond the
scope (pun not intended) of this project, but the code is fully documented and
available on GitHub at \url{http://github.com/hrickards/bioniscope}. A number of
screenshots of the working app are shown
in~\cref{fig:analogueScreenshot,fig:digitalScreenshot,fig:spectrumScreenshot}.

\begin{landscape}
  \begin{figure}[h]
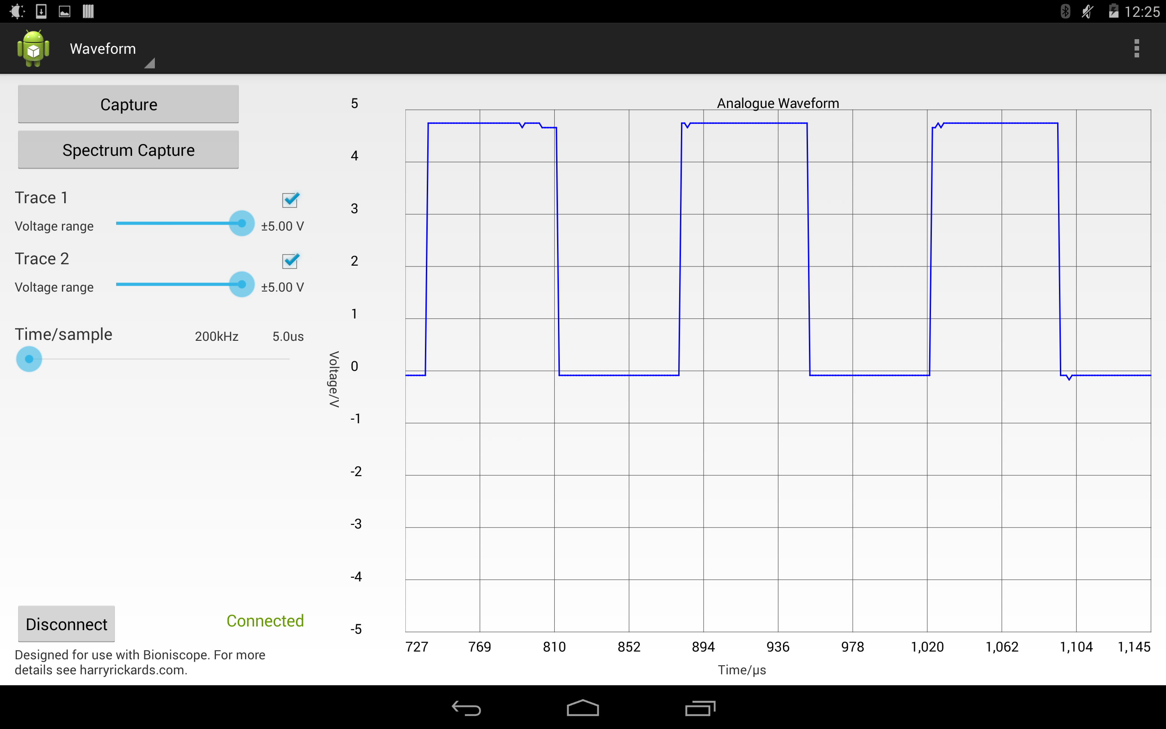
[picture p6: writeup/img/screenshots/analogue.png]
    
    \caption{Analogue waveform shown in Android Bioniscope app}
    \label{fig:analogueScreenshot}
  \end{figure}
\end{landscape}

\begin{landscape}
  \begin{figure}[h]
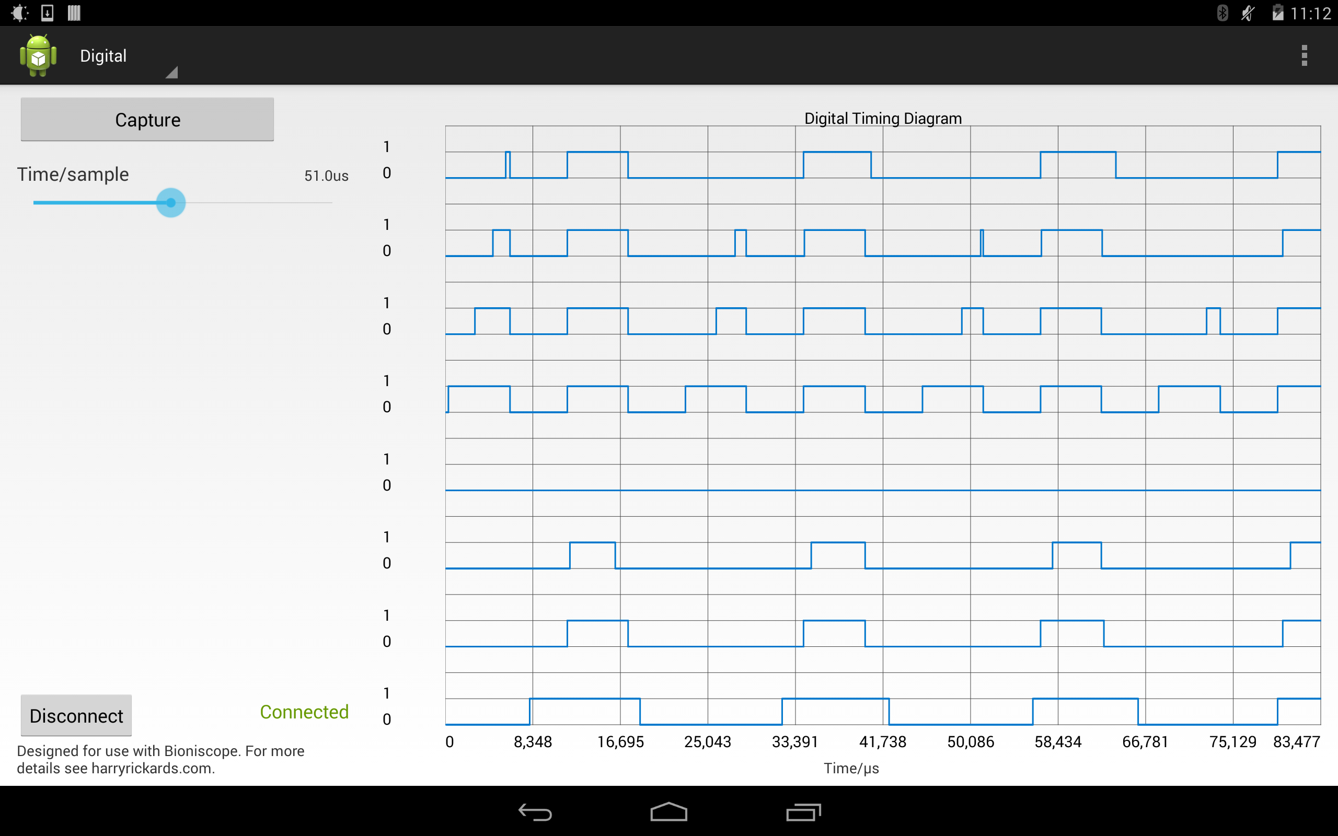
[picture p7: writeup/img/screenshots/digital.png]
    
    \caption{Digital timing diagram shown in Android Bioniscope app}
    \label{fig:digitalScreenshot}
  \end{figure}
\end{landscape}

\begin{landscape}
  \begin{figure}[h]
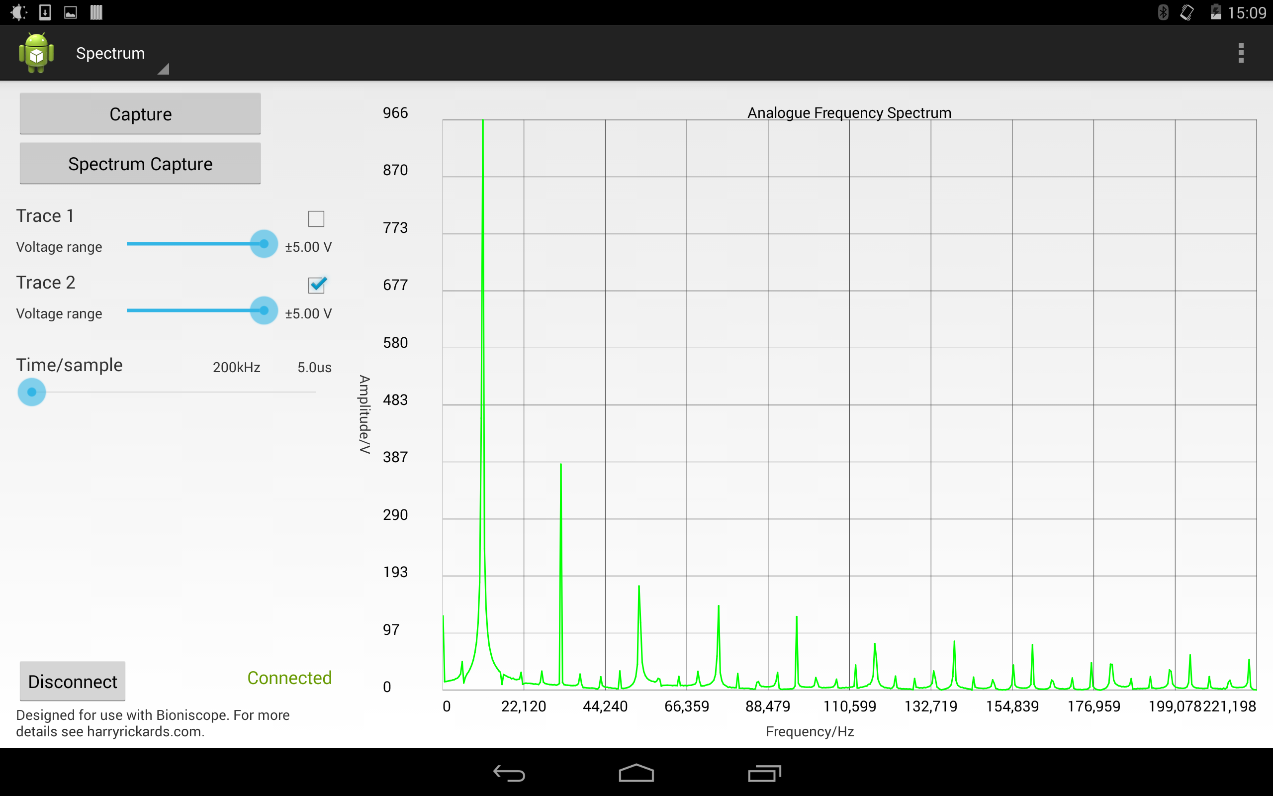
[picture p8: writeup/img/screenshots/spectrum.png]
    
    \caption{Analogue frequency spectrum shown in Android Bioniscope app}
    \label{fig:spectrumScreenshot}
  \end{figure}
\end{landscape}

\section{Circuit}
Combining all of the subsystems in~\cref{sec:subsystems}, the overall circuit
diagrams shown below ar reached.

\includepdf[landscape=true]{img/pcb/digital.pdf}
\includepdf[landscape=true]{img/pcb/analogue.pdf}

\section{Construction}
Initially, a number of the subsystems were built individually on breadboards.
This allowed the basic circuit details to be checked without requiring an
infeasibly large circuit to be built on a breadboard. 

\subsection{PCB Layout}
Once this prototype verification step was performed, the circuit was laid out on a
PCB. This process consists of three main steps: inputting the schematic
into the computer, laying out the schematic components onto the board and
routing traces (the PCB equivalent of wires) between the components.

Initially this was attempted using a piece of software called Eagle. A
significant number of electronics projects use Eagle, from small hobbyist
projects right up to industrial products. However, as this author started to lay
components onto the PCB using Eagle, an error was thrown: the free version
of Eagle only allows a maximum PCB size of \SI{100}{\mm}x\SI{80}{\mm}. For
reasons discussed later, the PCB size needed to be \SI{100}{\mm}x\SI{100}{\mm}.
The cheapest paid-version of Eagle is \$169, meaning it was much too expensive
to purchase for the sake of this project. Instead, an alternative was sought.

This author researched and briefly evaluated two alternatives: KiCAD and
DipTrace. KiCAD is a piece of open source software, meaning it's free to use
\footnote{There are two disctinct definitions of free that should be considered
here: gratis free (without cost to the user; this is somewhat confusingly also
called free as in beer) and libre free (without compromise to the user's
liberties; this is also known as free as in speech and essentially means that
the user has the right to run the software however they want, as well as the
right to modify it, meaning the source code is freely available).  Software
that's Free (with a capital F) is also known as open-source software (there are
major differences between the two terms, however for the purposes of this
explanation the reader can consider them identical) meaning it's both free as in
gratis and free as in libre. Common examples include LibreOffice (hence the
name) and GNU/Linux (the operating system running everything from the majority
of super computers to televisions to traffic lights). For more on this subject,
see Richard Stallman's book `\textit{Free as in Freedom}', which is also Free
and hence freely available on the internet.}, and DipTrace, a commercial piece
of software with a free version available limited to 2 signal layers\footnote{It
would be impractical to have all of the traces in a PCB in the same horizontal
plane, as they would not be able to cross at any point. Instead, a number of
planes, or \textit{layers}, are used.  PCBs are made by pressing together a
number of 2-sided PCB `chapters`, meaning that common numbers of layers are 2, 4
or 6 (with higher numbers possible but more expensive). As it's the cheapest
available and offers enough trace routing, a 2 layer board will be used for this
project} and 300 pins\footnote{This project uses somewhere in the region of 250
pins, so this limit is not a problem}.

Both are very capable pieces of software, and KiCAD would certainly be
favourable for philosophical reasons. Howerver, the majority of the ICs used in
the circuit are relatively uncommon. This means that CAD footprints (files
containing the physical dimensions of the chip) are not readily available, so
they must be manually created for each IC instead. This is a much quicker
process in DipTrace than in KiCAD (and indeed than in Eagle), and for this
reason alone DipTrace was chosen.

There were no major issues in creating the circuit schematic in DipTrace,
although a number of revisions were required for small improvements. Laying out
the PCB and routing the traces was much harder. DipTrace contains tools to
automatically place and route, however the electrical engineering community
strongly recommends against using such auto routers. Placing and routing is a task
that's extremely hard for a computer to find an optimal solution
to\footnote{There is a classification of such problems, known as NP. Very
  briefly: a \textit{running time} can be assigned to a given algorithm. For
  example, any algorithm to sort a list of numbers is at most
  $\mathcal{O}\left(n\log{n}\right)$, meaning that as the list of numbers grows
  longer, the running time of the algorithm grows slower than $n\log{n}$, where
  $n$ is the length of the list. We say an algorithm is polynomial-time if the
  running time is polynomial (so e.g., it's $\mathcal{O}\left(n^3\right)$ but
  not $\mathcal{O}\left(2^n\right)$). We then say an NP problem is one where the
  solution to the problem can be checked with a polynomial-time algorithm, but
  there is no polynomial-time algorithm to find that solution. An NP-hard
problem is then a problem that is at least as hard as the hardest NP problems.
Routing just one trace, with no obstacles to avoid, is an NP-hard problem}.
While software can make use of heuristics\footnote{A technique designed to find
a good-enough solution to a problem, when finding the optimal one would take too
long}, it's a commonly held belief that even the best autorouting software pales
when compared to a human with a small amount of experience (it may help to think
of PCB routing as art: while a computer can be programmed to come up with pieces
of art, even a small child can create much better ones).

Because of this, your author set about learning how to place and route PCBs. The
American electronics retailer Sparkfun provide a number of online tutorials and
videos regarding PCB routing which were extremely helpful. Eventually, the PCB
was routed, and while an expert would have done much better it sufficed for the
purposes of this project (particularly as there were no high voltages or
high-speed signals ($\ge\SI{50}{\MHz}$) involved). To finish the board, mounting
holes and silkscreen\footnote{The process is just screen printing, which
originally used silk as the screen, hence the name \textit{silkscreen}} (the
explanatory text and markings on a PCB) were added.

The routed PCB diagram can be seen in a scale version below, and a larger
version in~\cref{fig:largePCBDiagram}. A 3D render the board can be seen
in~\cref{fig:pcb3DRender}. To check component footprints (sizes), an early
version of the PCB was printed onto paper and attached to foam, as seen
in~\cref{fig:pcbFoam}

\includepdf[landscape=true]{img/pcb/pcb.pdf}

\begin{figure}[H]
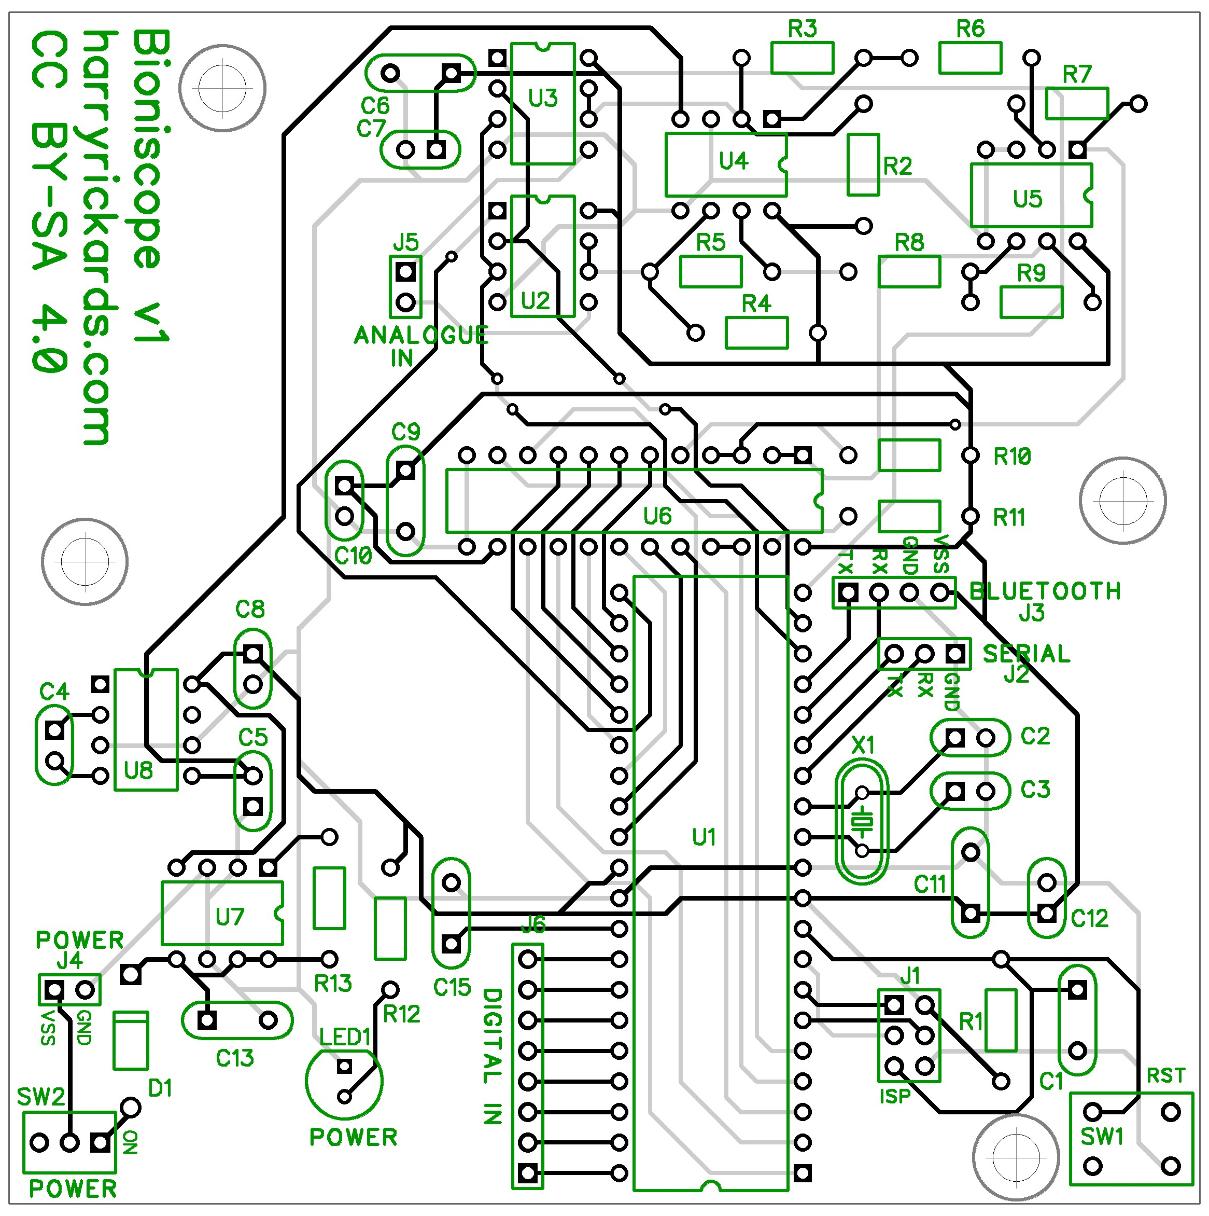
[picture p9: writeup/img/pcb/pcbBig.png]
  
  \caption[PCB (traces)]{Routed PCB}
  \label{fig:largePCBDiagram}
\end{figure}

\begin{figure}[H]
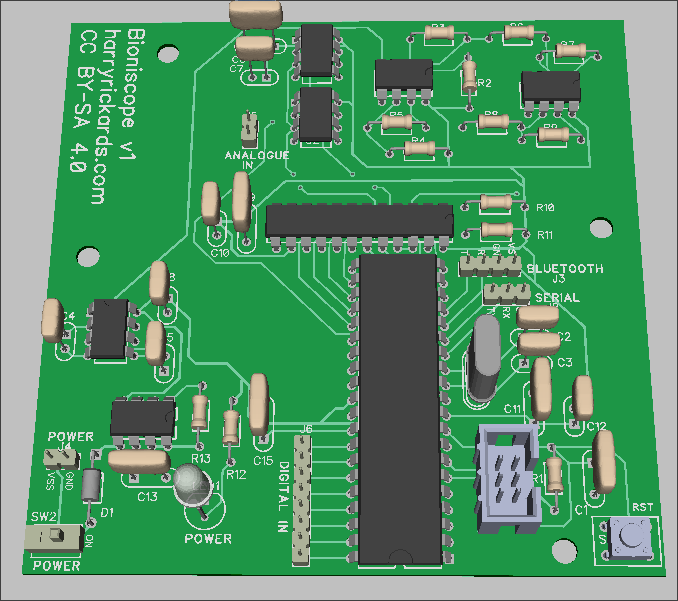
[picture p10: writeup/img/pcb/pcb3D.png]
  
  \caption[PCB (3D render)]{3D render of the PCB populated with components (produced by DipTrace)}
  \label{fig:pcb3DRender}
\end{figure}

\begin{figure}[H]
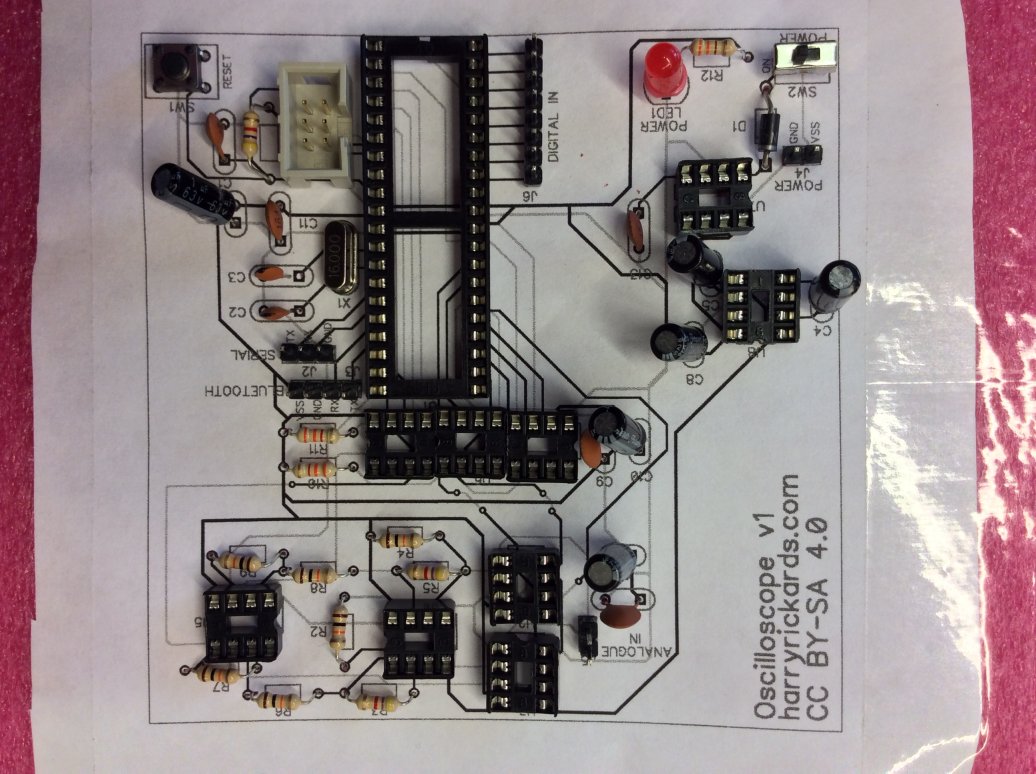
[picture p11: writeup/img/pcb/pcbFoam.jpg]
  
  \caption[PCB (Mockup)]{Photograph of a mockup of the PCB produced using paper and foam,
  allowing the sizes and placements of components to be checked}
  \label{fig:pcbFoam}
\end{figure}

\subsection{PCB Production}
The final step in the process was to get the board manufactured. In an American
or European fab house (the name for the company that prints the boards) this
would be extremely expensive. For example, popular EuroCircuits quoted a price
of over over \pounds 90 to produce just \textbf{one} board.

Instead, a Chinese proxy to a Chinese fab house was chosen (nearly all low cost
Chinese retailers use the Golden Phoenix fab house, but ordering directly from
them requires a minimum order of 100 square inches, far beyond the size of this
project\footnote{The proxies do something called panelisation: group a number of
small boards onto a larger board, have the large board made at a low cost and
then sell on the small boards for a small amount of profit}). DFRobot was chosen
because it offered more affordable delivery options than the other Chinese
options\footnote{EMS post is universally available for only a couple of dollars,
  but can take upwards of a month to arrive as it's simply air mail. Many
  Chinese retailers will also send goods worth hundreds of pounds through EMS
  post, simply writing `\textit{birthday card}` on the side meaning that while
  the retailer doesn't have to pay any export fees there is a high chance of the
  package spending weeks stuck in customs in the UK. Instead, a courier service
was chosen. Most Chinese PCB retailers only offer UPS and FedEx, which would
have cost around \$30 for this order. DFRobot offered DHL as well, which was
just over half the cost at \$16}. The boards cost \$23.99 for 10 boards, with a
\$16 delivery charge on top. At a cost of \$2.40 per board, ordering from a
Chinese retailer made the boards over 60 times cheaper than ordering from a
European fab house!

As required, the boards were \SI{100}{mm}x\SI{100}{mm} and 2 layers. There were
less choices available (the boards hade to be green, and coated in
HASL\footnote{If the boards were to be sold commercially, then HASL couldn't be
  used as it contains lead so breaks the EU Restriction of Hazardous Substances
  Directive, but for this hobby project using HASL is fine. This does suggest
  another reason why European fab houses are more expensive: hazardous
  substances such as lead can't be used in the board, whereas in China that's
not an issue}) than from a European fab house, but that didn't matter for this
project. Due to the recent Chinese New Year, the boards took slightly longer
than usual to be produced, although still took only 2 working days, something
that EuroCircuits charge over \pounds 150 extra for.

\subsection{Obtaining Parts}

All the ICs had to be specially obtained for the circuit, as they weren't
available in school. Rather than have to purchase them, your author made good
use of the samples programmes run by most semiconductor companies.

Take, for example, the MAX114 ADC. Such a specialist chip would have to be
ordered from a large electronics distributor such as Mouser, who sell it at
\pounds 4.71 per chip. Instead, a number (in this case, 2 were obtained along
with 2 other Maxim ADCs of a similar cost for personal projects) can be freely
obtained from Maxim Integrated, the semiconductor company who make the chip, by
filling out a samples request. Maxim then sent the chips within 3 days (one of
those days being Boxing Day), and they were delivered from the Philliphines in a
further 2 days. All in all, the chips were delivered in the same time it would
have taken had they been ordered from Mouser, but \pounds 25 had been
saved\footnote{Assuming the standard \pounds 10 for delivery from Mouser.}.

One might question why companies such as Maxim provide this free service, and
the answer is twofold. If an engineer used a free sample from Maxim when
prototyping the `\textit{next big thing}', a lot more chips would be required
when producing the real product and Maxim would make a lot more money than it
lost by giving out free samples to lots of engineers. Similar reasoning applies
to students: if the engineers at multi-billion dollar companies all received
free samples from Maxim when they were in college and hence developed brand
loyalty, Maxim will make lots of money.

It should be pointed out that Maxim are not the only company running this
scheme: as of writing, Maxim, Analog Devices, Texas Instruments (or National
Semiconductor), Atmel, Fairchild Semiconductor, Microchip and Linear Technology
are just some of the more well-known companies that offer this service (in fact,
the first 4 provided free samples for this project). Furthermore, if one becomes
a little more adventorous and searches a little further afield, free samples can
be found for everything from enclosures to superbright LEDs. If the reader is
interested in more information, you're advised to
consult~\textcite{LadyAdaSamples}.

\section{Enclosure}

To protect the circuit, an enclosure was needed. There were only a limited
number of places were mounting holes could go on the PCB, so a custom-made
enclosure had to be made rather than using a prebuilt one with standard mounting
hole locations.

The options available to this author were to produce the enclosure using either
a 3D printer or a laser cutter. For easy examiner inspection, the enclosure
needed to be transparent and only coloured plastic filament was available for
the 3D printer, meaning the laser cutter needed to be used.

A case was designed using the industry standard 2D cad package \textit{2D
Design}. It was laser cut out of transparent acrylic and solvent welded together
using \textit{dichloromethane}. The final enclosure can be seen
in~\cref{fig:enclosurePhoto}.

\begin{figure}
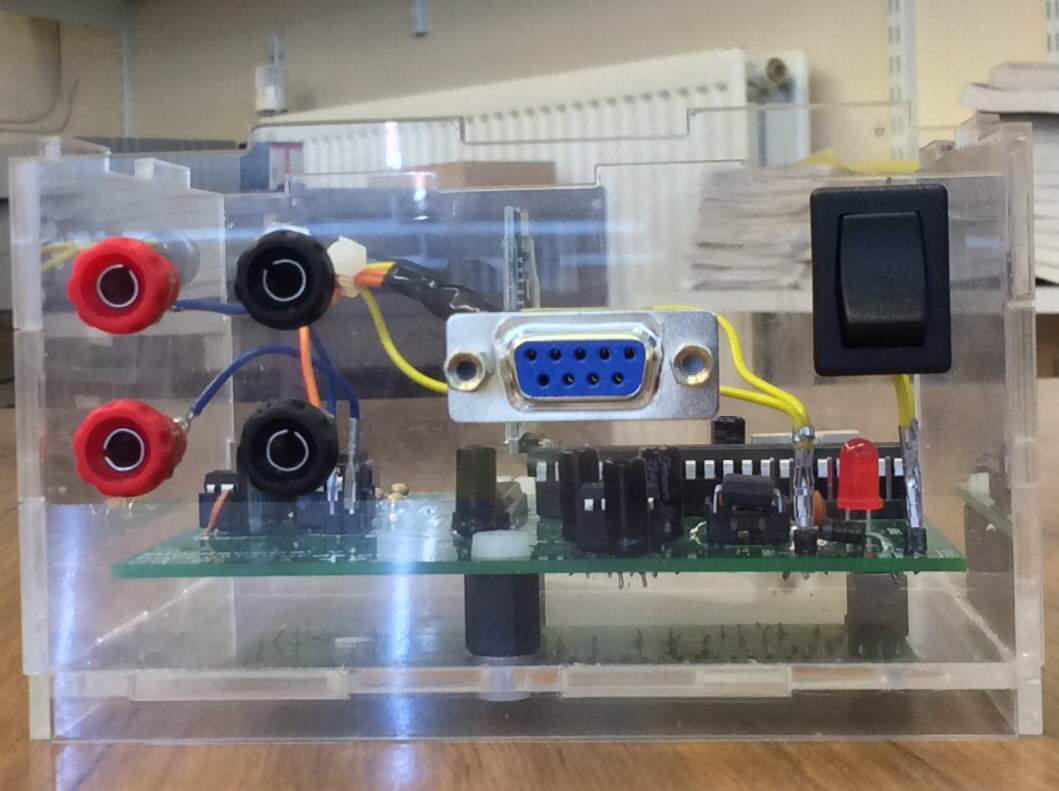
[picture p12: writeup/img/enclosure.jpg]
  
  \caption{The final enclosure, with the circuit inside}
  \label{fig:enclosurePhoto}
\end{figure}

\section{Final System}

See~\cref{fig:finalSystemPhoto,fig:finalSystemWorking} for the final system.

\begin{figure}[h]
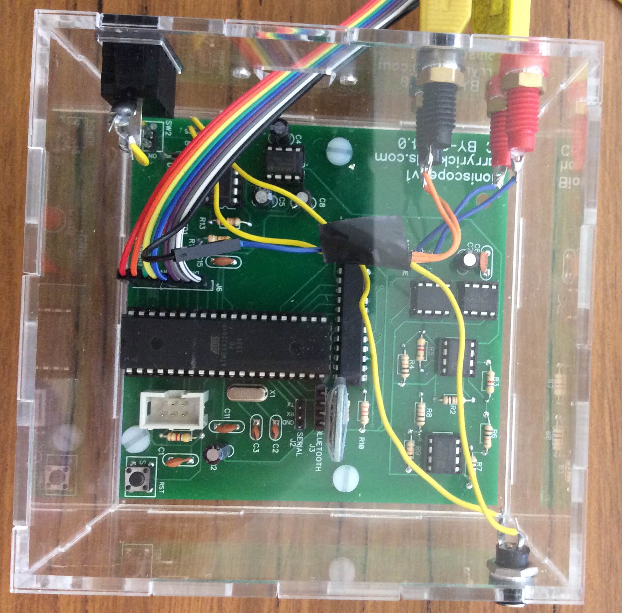
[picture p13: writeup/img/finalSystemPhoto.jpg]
  
  \caption{The final circuit}
  \label{fig:finalSystemPhoto}
\end{figure}

\begin{figure}[h]
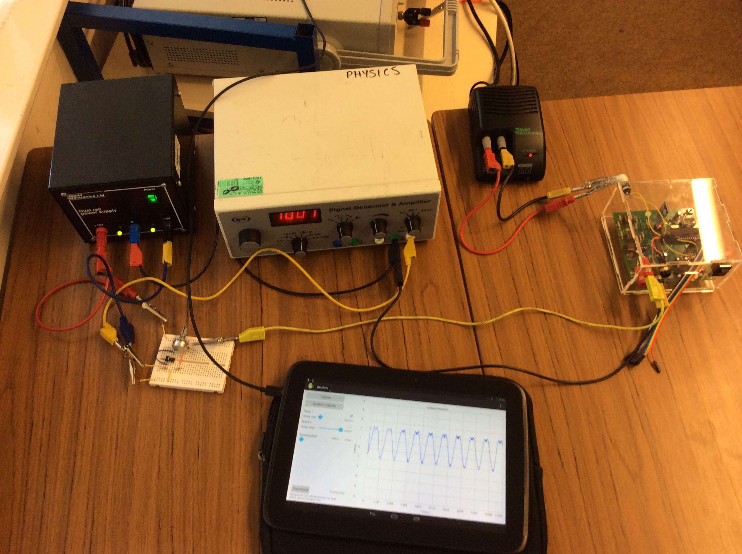
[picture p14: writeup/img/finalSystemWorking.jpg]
  
  \caption{The final circuit in action}
  \label{fig:finalSystemWorking}
\end{figure}

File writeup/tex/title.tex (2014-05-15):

% See wikibooks
\begin{titlepage}
  \begin{center}
    \null
    \vspace{0.5cm}

    \textsc{\Large Electronics A2 Project}\\[0.5cm]

    \HRule \\[0.4cm]
    { \huge \bfseries Android-based Bluetooth Oscilloscope \\[0.4cm] }

    \textsc{Bioniscope}

    \HRule \\[1.5cm]

    \begin{flushright} \large
    \emph{Author:} \\
      Harry \textsc{Rickards}
    \end{flushright}

    \vfill

    \Huge{\ccLogo\, \ccAttribution\, \ccShareAlike} \\[1.5cm]

    \large \the\year
  \end{center}
\end{titlepage}

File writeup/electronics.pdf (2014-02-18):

## Electronics A2 Project

# Bioniscope

### Author: Harry Rickards

# c b a

2014

# Contents

1 Problem Analysis and Solution Design | 3
2 System Development | 19
A Fourier Series of a Square Wave | 34

# List of Figures

1.1 Existing oscilloscopes¹
| | 3
1.2 Logic Analyser Example Output | | 4
1.3 Equivalent Time Sampling Diagram | | 6
1.4 Equipment setup to test the CRO | | 8
1.5 Not-so-square wave shown on the oscilloscope | | 10
1.6 Approximations to a square wave up to certain harmonics | | 11
1.7 The Arduino code used to echo back any characters received via Bluetooth 13 1.8 The python code used to measure the accuracy of the Bluetooth link at
various distances | | 14
2.1 Oscilloscope Subsystems | | 20
2.2 1st Amplifier Stage | | 22
2.3 2nd Amplifier Stage | | 23
2.4 Amplification Circuit Simulation | | 23
2.5 Amplification Circuit Waveform | | 24
2.6 Amplification Circuit Frequency Spectrum | | 25
2.7 Amplification Circuit Bode Plot | | 26
2.8 ADC Power Connections | | 27
2.9 Arduino as a Programmer | | 28
A.1 Square wave with amplitude 1 and frequency 1 Hz | | 34

1
jepoirrier, Oscilloscope with noise; mightyohm, New Oscilloscope.

# Problem Analysis and Solution Design

## 1.1 Problem Definition

### CROs and DSOs

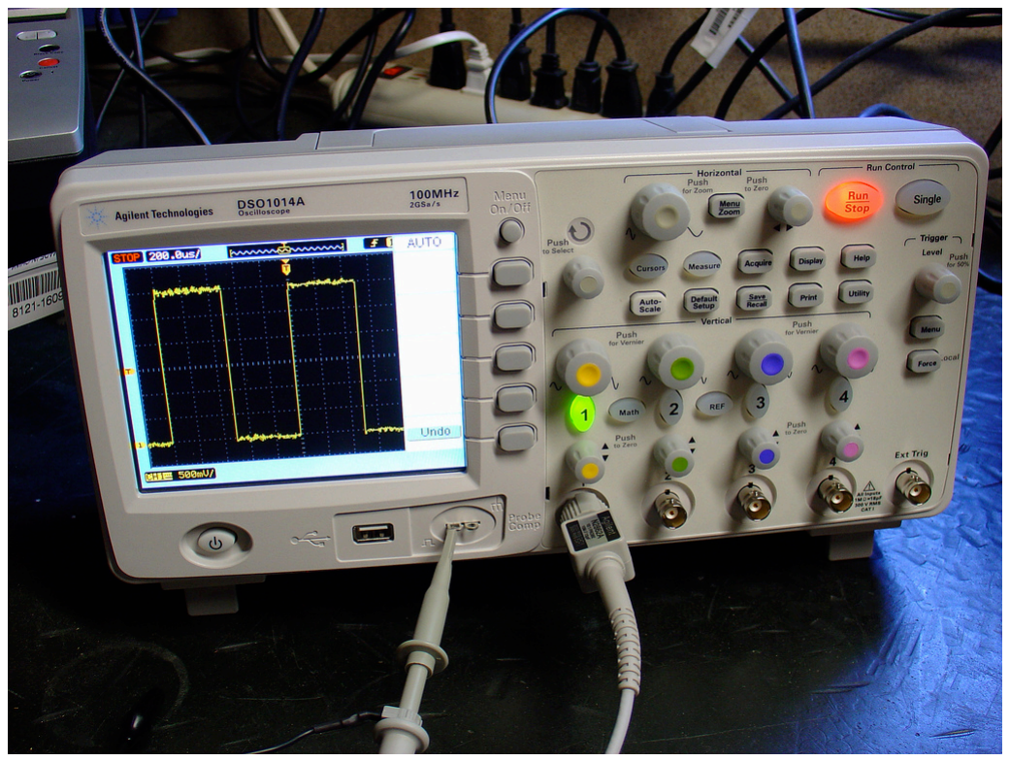
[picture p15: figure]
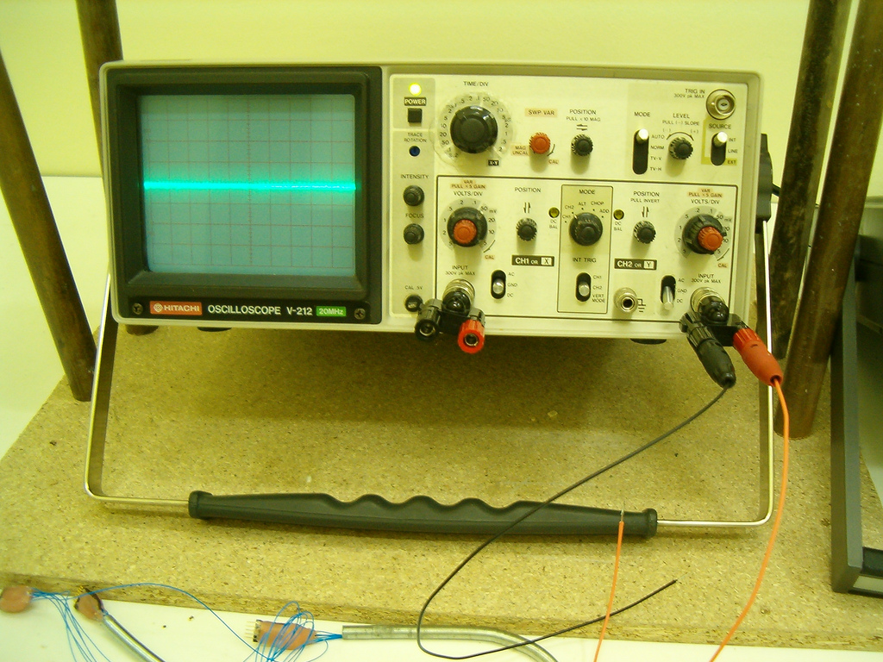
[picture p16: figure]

(a) Cathode Ray Oscilloscope | (b) Digital Storage Oscilloscope
Figure 1.1: Existing oscilloscopes¹

Oscilloscopes available in secondary schools or sixth forms are generally basic analogue oscilloscopes known as CROs, or Cathode Ray Oscilloscopes (named so because the display is a Cathode Ray Tube).²
The alternative is a DSO, or Digital Storage Oscilloscope. These work in a very different way to CROs. Like in a CRO, the input signal is first passed through some analogue circuitry to amplify it and so on. However, it’s then sampled into a digital signal using a DAC (Digital to Analogue Converter) and processed using a microcontroller (perhaps using the help of an FPGA³or a DSP⁴
), before being output onto some sort of digital screen.⁵

2Phillips, Using an Oscilloscope.
3Field Programmable Gate Array a device that can be programmed to ~become a very large logic circuit. This makes it much faster than a microcontroller at doing a specific job.
4Digital Signal Processor a custom microcontroller especially designed to perform various signal processing functions (e.g., performing a Discrete Fourier Transform to obtain the frequency spectrum of a signal, or using Principal Component Analysis to seperate two audio signals)
5TiePie Engineering, Digital Data Acquisition.

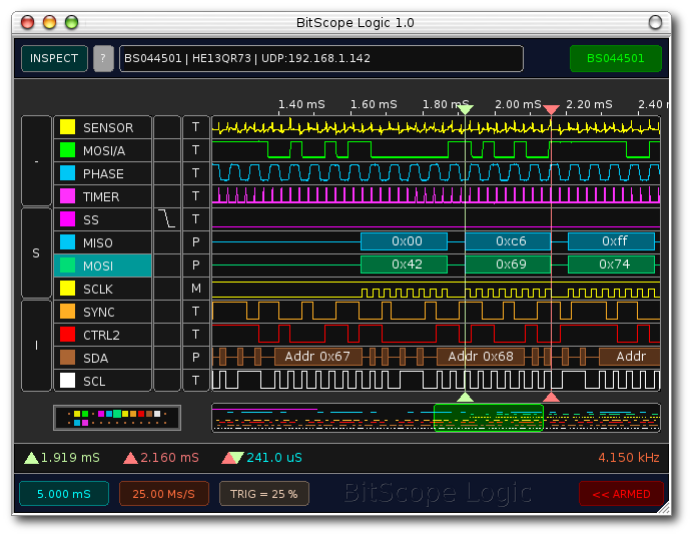
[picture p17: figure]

Figure 1.2: Example output from a Logic Analyser¹⁰

### Advantages of DSOs

DSOs offer a number of advantages over CROs. As well as relatively basic differences such as the traces being much more sharply defined, DSOs allow digital signal processing to be done on the input signal. This means that, for example, DFTs (Discrete Fourier Transforms)⁶
can be run to produce a frequency spectrum of the input signal, allowing the user to see both time-domain and frequency-domain representations of the signal.⁷ Additionally, a DSO can be used to create a basic Logic Analyser. This is essentially the digital equivalent of an oscilloscope — a relatively large number of digital wires and buses are connected to the Logic Analyser and a timing diagram is output⁸

9

6While DFTs are the most famous transformations, mainly due to the prevalence of the FFT (Fast Fourier Transform) algorithm, in practice DCTs (Discrete Cosine Transforms) are more commonly used as they can be calculated more quickly whilst achieving a similar result
7This also means that DSOs can be used as basic spectrum analysers: essentially devices that plot frequency spectrums, these have uses as far ranging as determining GSM interference when planning mobile phone networks
8
In more advanced, standalone Logic Analysers, more complicated outputs such as decoded Ethernet packets can be output
9Woodward, What’s the Difference Betwen a Mixed-Signal Oscilloscope And A Logic Analyzer?

### Project Definition

This project¹¹ aims to create a Digital Sampling Oscilloscope, with the following more advanced features included:
- Frequency spectrums of the input signals available
- Basic capability as a Logic Analyser
From now on, oscilloscope will be used to refer to a Digital Sampling Oscilloscope and CRO will be used to explicitly refer to a Cathode Ray Oscilloscope.

## 1.2 Research into Existing Oscilloscopes

Using two articles from Tong¹² and Gabotronics,¹³ digital oscilloscopes can be categorised by the following criteria:
- Bandwidth The bandwidth¹⁴ in Hz of the initial analogue stages of the oscilloscope. Common values range from 100 kHz to 100 MHz.
- Type of Sampling There are two common types of sampling, real-time and equivalent-time sampling. With real-time sampling the scope samples sequentially over the wave, whereas with equivalent-time sampling the scope captures a sample from a different part of the wave every time period. This is perhaps illustrated more clearly in fig. 1.3.
While equivalent-time sampling offers a much faster sampling rate, it is much more complicated to implement.
- Sample Rate The rate (in Hz or the equivalent samples per second) at which the oscilloscope can take individual digital samples from the signal. Common values range from 10 kHz to 1 GHz.
- Resolution The number of bits each sample has. Common values are 8, 12 and 16 bits. This determines the precision of the oscilloscope, and hence the minimum noise.
- Memory Depth The number of samples the oscilloscope can store at one time. Measured in either words, or bits (for example, if the resolution is 8 bits then a depth of 128 words is equivalent to 1024 bits). Intuitively, this can be thought of as the horizontal resolution. Common values range from 100 samples to 10 M samples.
- Triggers Available The different options to trigger the oscilloscope to start capturing samples, with the most common one being edge triggering¹⁵ (when the signal passes a threshold on a rising edge¹⁶). There are also more advanced triggers such

11As seen in various places in this document, the project was nicknamed Bioniscope — a portmanteau of bionic (from Android) and oscilloscope
12Tong, What to Look for When Choosing an Oscilloscope.
13Gabotronics, Digital oscilloscopes for hobbyists.
14Most commonly, bandwidth is taken to be the range of fraquencies where the signal has an amplitude gain of −3 dB ≈ 71%
15Picotech, Advanced Triggering with PicoScope.
16A falling edge could also be used, but the type of edge is part of the trigger specifications and stays constant

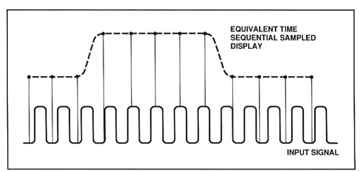
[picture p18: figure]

Figure 1.3: Diagram illustrating equivalent time sampling¹⁹

as pulse width triggering, which triggers the scope when a digital pulse of a certain width is detected. Some expensive oscilloscopes can provide extremely complicated triggers: e.g., decoding Ethernet, TCP/IP¹⁷ and HTTP¹⁸ packets from a digial input, and eventually triggering the analogue inputs when a certain webpage is requested.
- Input range The minimum and maximum range of input voltages that can be detected by the oscilloscope. A typical value would be from ±50 mV to ±50 V. In many cases, this will be a relatively small range, but an active scope probe (a test probe with an amplifier inside it) will be used to broaden this range.

## 1.3 Practical Investigations

### 1.3.1 Oscilloscope Reliability Investigation

An existing oscilloscope (in this case, a CRO) will be a vital part of testing the osilloscope, so it would be wise to test it’s accuracy first.
An FPGA²⁰was programmed to produce a square wave at a number of different frequencies, and the wave was looked at on an oscilloscope. Due to their completely different nature compared to microcontrollers, FPGAs are usually programmed in a language called Verilog. While the details are beyond the scope of this project²¹, let us just say that Verilog is a way of describing the propogation of signals based on dependencies on both time and other signals.²² See listing 1 for a very simple Verilog example.

always @(posedge) clk begin
q <= d;
end
Listing 1: A simple flip-flop implemented in Verilog

17The protocol used for internet networking
18The protocol used to transfer web pages over the internet
20Field Programmable Gate Array a device that can be programmed to ~become a very large logic circuit. This makes it much faster than a microcontroller at doing a specific job.
21Tala (ASIC World), found online at http://www.asic-world.com/verilog/index.html, is an excellent resource for learning Verilog
22Wikipedia, Verilog — Wikipedia, The Free Encyclopedia.

The FPGA was programmed to perform 50% duty-cycle clock divisions of the FPGA’s internal²³ 50 MHz clock, meaning the output frequency could be easily calculated using

f =

50 MHz
2

n

(1.1)

where n is the clock divisor. The accuracy of the crystal oscillator is so high (an average error value would be around 0.0005%²⁴) compared to the accuracy of reading values from a small oscilloscope screen that we can ignore it in this instance.
The Verilog code used can be seen in listing 2.

// Output a square wave signal of various frequencies to test a CRO module oscilloscope_test(clk, signal);
// Accurate 50MHz clock input signal
input clk;

// Output square wave
output wire signal;

// Module that divides a frequency to produce a 50% duty-cycle output // using flip-flops
clock_divider d1 (
.clk_in(clk),
.clk_out(signal)
);
// clk is divided by 2^divisor
// So increase by 1 to halve the output frequency
defparam d1.divisor = 21;
endmodule
// Divide a clock by 2^divisor with a 50% duty-cycle output (1:1 mark:space) module clock_divider(clk_in, clk_out);
// This is intended to be changed by the code calling this module parameter divisor = 2;

// Input to be divided
input clk_in;

// Create a counter out of flip flops, and toggle clk_bit whenever the // counter's most significant bit toggles. This produces a 50% duty-cycle // output that we use to toggle clk_out.
reg [divisor-1:0] counter = 0;
always @(posedge clk_in) counter <= counter + 1;
output reg clk_out = counter[divisor-1];
endmodule
Listing 2: Code used to produce the square wave to test the oscilloscope

23A high-quality crystal oscillator
24Semtech, Improving the Accuracy of a Crystal Oscillator.

Data

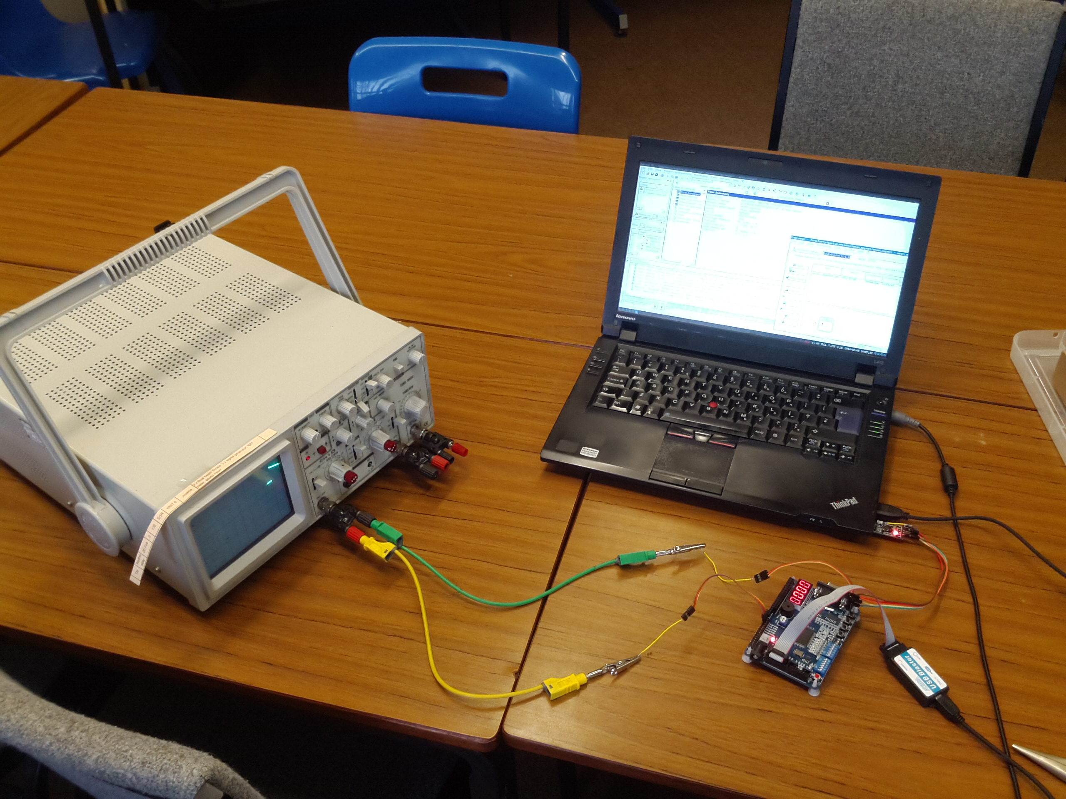
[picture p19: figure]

Figure 1.4: Equipment setup to test the CRO

Seen in fig. 1.4, the equipment was setup as described above. Frequency readings were taken over a number of values of n ranging from 4 to 19. For each reading, the horizontal and vertical division settinsg were recorded, as well as the number of divisions counted in one period of the wave. From these, the measured frequency and amplitude were calculated.
These measured values were compared to the actual frequency (as calculated by ??) and amplitude (the digital output from the FPGA ranged from 0 V to it’s logic-high level of 3.3 V, leading to an amplitude of 1.65 V) to find error values for the frequency and amplitude.
The numerical results of the experiment can be seen in table 1.1.
With n = 19, the frequency was low enough that it was very difficult to take a reading of the number of y divisions per period due to the nature of cathode ray tubes. This can be seen in the results: the frequency error jumps from less than 1% to over 90%. Because of this, n = 19 will be considered an anomolous result and disregarded for the rest of this analysis.
Note the high level of accuracy, particularly with regards to frequency. Due to previous bad experiences with this oscilloscope, your author was rather surprised at the results. Almost all of the error can actually be put down to errors in the human measurement process. Take n = 7 as an example: the number of X divisions was measured as 5.1 to 1 decimal place, giving a percentage error of 0.98%. It is purely coincidental then, that the actual error is less than half that at 0.39%!

Measured | Actual | Error (%)
n Time/div (µs) Voltage/div (V) X div Y div Frequency (kHz) Amplitude (V) Frequency (kHz) Amplitude (V) Frequency Amplitude
4 | 0.1 | 2 | 3.4 | 2.0 | 2940 | 2.0 | 3120 | 1.65 | 5.88 | 21.21
5 | 0.2 | 2 | 3.1 | 1.8 | 1610 | 1.8 | 1560 | 1.65 | 3.23 | 9.09
6 | 0.5 | 2 | 2.5 | 1.8 | 800 | 1.8 | 781 | 1.65 | 2.40 | 9.09
7 | 0.5 | 2 | 5.1 | 1.7 | 392 | 1.7 | 391 | 1.65 | 0.39 | 3.03
8 | 1 | 2 | 5.1 | 1.7 | 196 | 1.7 | 195 | 1.65 | 0.39 | 3.03
9 | 2 | 2 | 5.1 | 1.7 | 98.0 | 1.7 | 97.7 | 1.65 | 0.39 | 3.03
10 | 5 | 2 | 4.1 | 1.7 | 48.8 | 1.7 | 48.8 | 1.65 | 0.10 | 3.03
12 | 20 | 2 | 4.1 | 1.7 | 12.2 | 1.7 | 12.2 | 1.65 | 0.10 | 3.03
14 | 100 | 2 | 3.2 | 1.7 | 3.12 | 1.7 | 3.05 | 1.65 | 2.40 | 3.03
16 | 500 | 2 | 2.6 | 1.8 | 0.769 | 1.8 | 0.763 | 1.65 | 0.82 | 9.09
19 | 2000 | 2 | 2.7 | 1.7 | 0.185 | 1.7 | 0.0954 | 1.65 | 94.18 | 3.03

Table 1.1: Results from oscilloscope accuracy experiment

9

### Qualitative Results

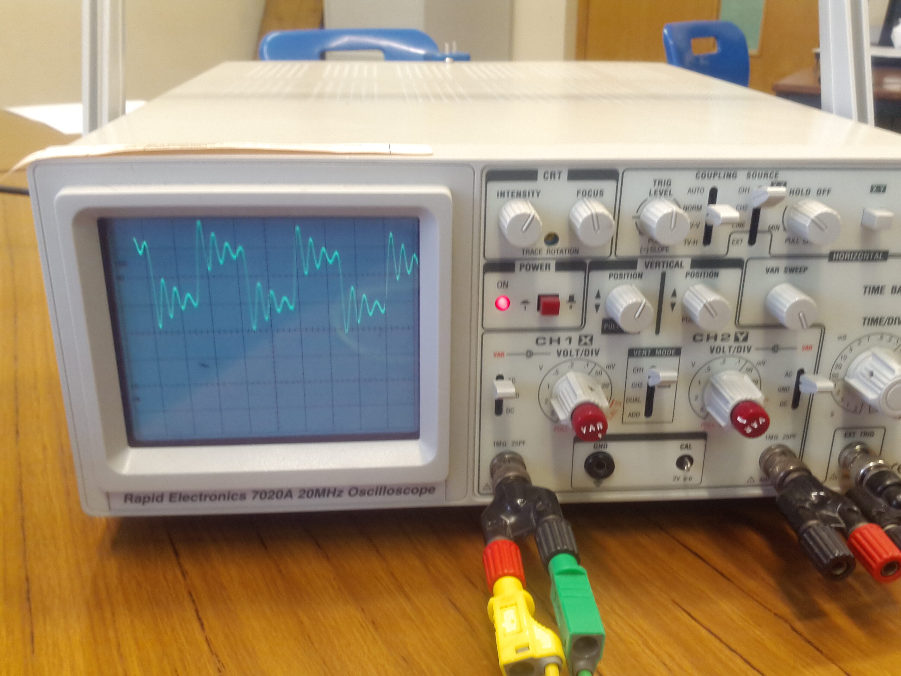
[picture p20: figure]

Figure 1.5: Not-so-square wave shown on the oscilloscope

In qualitative terms, however, the oscilloscope was not nearly as accurate. Looking at fig. 1.5, one can see that at high frequencies the analogue bandwidth of the oscilloscope comes into play, causing the digital input to look very much like a summation of sine waves. In fact, this was still visible to a lesser extent until n = 12 (corresponding to a frequency of 12.2 kHz). This means that while the oscilloscope can be used to accurately determine the frequency of high-frequency signals, it can’t be used to determine the shape of a signal with any accuracy.
Using the maths detailed in appendix A we can plot graphs of square wave approximations up to a certain number of harmonics, as seen in fig. 1.6. Comparing these to fig. 1.5, we find that the closest match²⁵ is the seventh harmonic graph. This means we can approximate the analogue bandwidth of the oscilloscope as 7 times the frequency of the signal, or 7 × 3.12 MHz = 21.8 MHz²⁶

25The match is not exact because harmonics above the seventh harmonic are present, they just have a reduced amplitude. However by looking at the number of peaks in one period of a wave we find the seventh harmonic is the highest one with a major component present.
26Checking the datasheet of the oscilloscope, we find the quoted bandwidth is 20 MHz meaning we are accurate to within a third of a harmonic, as close as we could hope using this basic method.

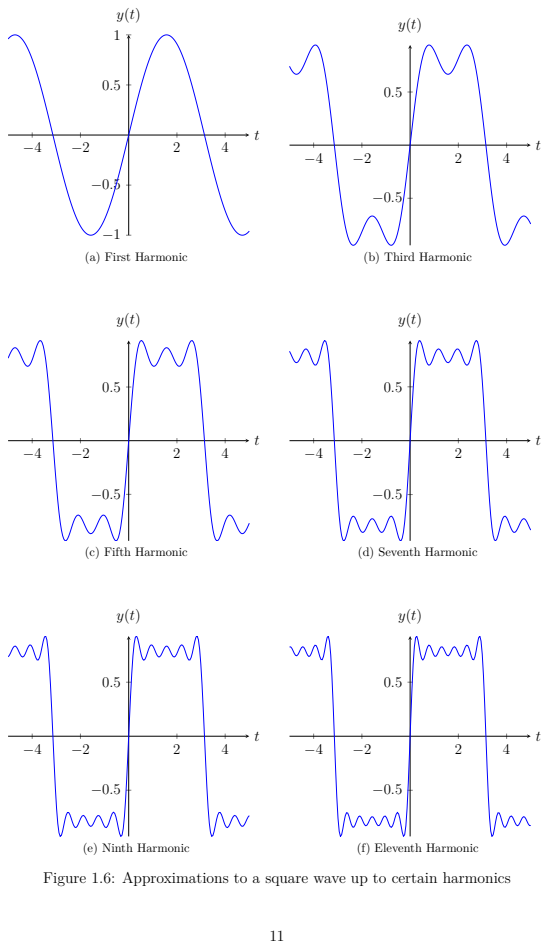
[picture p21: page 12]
(a) First Harmonic; (b) Third Harmonic; (c) Fifth Harmonic; (d) Seventh Harmonic; (f) Eleventh Harmonic

(e) Ninth Harmonic
Figure 1.6: Approximations to a square wave up to certain harmonics

Distance (m) Reliability (%)
0.0 | 100.00
1.0 | 100.00
2.0 | 100.00
3.0 | 100.00
4.0 | 100.00
5.0 | 100.00
5.5 | 6.51
6.0 | 0.00

Table 1.2: Results from bluetooth distance experiment

### 1.3.2 Bluetooth Distance Test

As discussed in section 1.5, Bluetooth will be used to communicate between the microcontroller and Android device. Because of this, a practical investigation was undertaken to test the reliability of the Bluetooth link at different distances.
The Bluetooth module to eventually be used in the final product, an HC06, was connected to an Arduino (an ATMega microcontroller development board allowing quick prototyping) and programmed to echo any data sent to it (so if the character A was received by the HC06, it would immediately transmit back the character A). This code can be seen in fig. 1.7.
A python²⁷ program was then written on a laptop computer (with an inbuilt Bluetooth module) to communicate with the HC06. 384²⁸ bytes were sent out, and the received data compared to the sent data to produce an accuracy figure. This code can be seen in fig. 1.8²⁹
This program was run at with the laptop a number of different distances from the HC06. The results are shown in table 1.2.
At distances up to and including 5 m, the link was 100% reliable. At 5.5 m that figure dropped dramatically (suggesting that the connection was lost partway through the test), and at further distances the link dropped out completely. This means that the oscilloscope should be able to be used at distances of up to 5 m away from the device.
Photo of Experiment

Missing
figure

27A very high-level computer programming language that’s suited for tasks such as this, with libraries for things such as serial communication. For more information see various online resources.
283 times 128, and a convenient compromise between speed and accuracy
29For details on how the Bluetooth receiver in the laptop was setup as a serial device, see the online page for this project at http://github.com/hrickards/bioniscope.

// IMPORTANT
// Delays need to be added into setup() and loop() if the Arduino is to be
// programmed over USB. If the code is left as it is, the Arduino will not
// be able to communicate with the IDE over USB, so a dedicated AVR programmer // (or another Arduino) will be needed to upload new sketches.

// Run when the Arduino starts up initially
void setup() {
// Begin serial communication with the HC06 at a baud rate of 9600 Serial.begin(9600);

// Use pin 13 (connected to an LED) to show visually when data is being // written
pinMode(13, OUTPUT);
}

// Loops continuously
void loop() {
// Turn LED off
digitalWrite(13, LOW);

// Wait til serial available while (!Serial.available());

// Turn LED on
digitalWrite(13, HIGH);

// Echo back the received serial byte
Serial.write(Serial.read());
}
Figure 1.7: The Arduino code used to echo back any characters received via Bluetooth import serial # pySerial used for serial communication with BT receiver

# Number of bytes of data to send each time

ITERATIONS = 384

# Open a serial socket to the BT device

# If this line fails, check /dev/rfcomm0 is the right port

ser = serial.Serial('/dev/rfcomm0', 9600, timeout=1)

# Remove any initial noise by writing a newline and waiting for it to return ser.write("\n")

ser.readline()

# Write results to data.txt

f = open("data.txt", "wb")

j = 0 # Number of times the test has been run

# Keep running the indented part until the program is stopped

while True:
# To be filled with booleans that are true iff the data is echoed correctly data = []

# The character to send and have echoed back. Will be changed by the code # below.

char = 0x00

# Do the indented part ITERATIONS number of times

for i in range(ITERATIONS):
# Increment char, wrapping back to 0x00 after 0xFF char = (char + 1) % 0xFF

# Write the character

ser.write(chr(char))
# Append to data whether or not the character was echoed correctly data.append(ser.read() == chr(char))

# The line of output to show to the user and write to data.txt

# test number: reliability average

output = "%d: %f" % (j, sum(data)*100.0/len(data)) print(output)
f.write(output + "\n")

j += 1
raw_input("...") # Wait for the user to press enter

ser.close()
f.close()
Figure 1.8: The python code used to measure the accuracy of the Bluetooth link at various distances

## 1.4 Numerical Parameters

### Frequency and Sampling Rate

The sampling rate should be as high as feasibly possible to allow the oscilloscope a wide variety of uses. By Shannon (“A Mathematical Theory of Communication”), the maximum frequency³⁰ that we can sample is half the sampling rate. In reality, because of the basic real-time sampling method being used it must be at the very least 25 times less than the sampling rate (allowing just over 12 samples for each half-period of the wave).
ADCs in a DIP³¹ package (suitable for breadboards) are not readily available beyond 2 MHz. Furthermore, the only 2 MHz DIP ADC, the AD7822, is renowned for being particularly difficult to interface with a microcontroller. Instead, an ADC with a maximum sampling rate of 1 MHz will be used (many DIP ICs can provide this sampling rate). However, at such a high speed getting the full sampling rate out of an ADC is not usually possible with a microcontroller (because, for example, a control bit might have to go high then low again for 20 ns, but a microcontroller with a 16 MHz clock can only do this in an absolute minimum of 62.5 ns). So the oscilloscope sampling rate will be specified as at least 500 kHz.
This means the maximum frequency that should be sampled is 500 kHz
25 = 20 kHz.

### Bandwidth

The maximum frequency into the analogue amplification stage will be 20 kHz, but we also need to take into consideration harmonics (remember, by Fourier any non-sinusoidal signal can be represented as a sum of sinusoidal signals of increasing frequency). The effect of this can be seen all too clearly in fig. 1.5 To be safe, we will specify a minimum bandwidth of 1 MHz.

### Resolution

Inaccuracies in the oscilloscope output are more likely to be caused by the analogue circuitry (in particular, the digital potentiometers are only accurate to 0.25%) than a low resolution, so an 8 bit resolution will suffice (this offers an accuracy of ≈ 0.4%, more accurate than the digital potentiometer accuracy). This also means ADCs will be more readily available, as 8 bit DIP ADCs are more common than higher resolution ones.

30Actually, that’s the maximum sinusoidal frequency that we can sample. By Fourier, all other waveforms can be represented as a sum of sinusoids, and in reality sampling at 25 times the frequency of the waveform means that we’ll be able to get a high enough amount of detail for most non-sinusoidal waveforms
31Electronics components come in a variety of different packages of many different shapes and sizes. Generally, those that fit in a breadboard are part of the DIP (dual in-line package) family: e.g., CDIP (Ceramic DIP) and PDIP (Plastic DIP). Other packages, such as TSOP, are usually much smaller and suitable only for soldering onto PCBs. While a PCB will be used for the final oscilloscope, soldering surface-mount chips (a generic term for all packages smaller than DIP, such as TSOP) requires unavailable specialist equipment.

### Memory Depth

The memory depth needs to be large enough to have a horizontally precise signal, but small enough that the samples can easily be stored in the microcontroller. For these reasons, 1024 words (equivalent to 8192 bits or 1 kB with an 8 bit resolution) will be chosen. Most microcontrollers have multiple kB of RAM, so multiple signals can easily be stored in the RAM.

### Input Range

For the minimum input range, we’ll choose the standard ±50 mV, however high-bandwidth rail-to-rail op amps are only cheaply available up to ±5 V so for the maximum input range we’ll choose ±5 V³²

### Triggers Available

For the purposes of this project, simple edge triggering will more than suffice. Both the channel on which and the threshold at which the trigger occurs will be adjustable by the user.

## 1.5 Communication with Android Device

As detailed in section 2.1.6, an Android device will be used as the frontend to the oscilloscope. This means that the microcontroller must somehow communicate with the device.
There are 4 feasible ways that this could be achieved: via WiFi, Bluetooth and USB.

### USB

This would perhaps be the easiest way to implement the communication. Small discrete devices, such as the CP2102,³³ convert between the relatively complicated USB protocol and the simple UART protocol. In fact, nearly all microcontrollers now come with a built-in USART interface, so the microcontroller side of things would be literally ‘plug and play’³⁴
On the Android side, the microcontroller would appear as a serial communication device. The ‘usb-serial-for-android’ library³⁵ would make it trivial to communicate with

32While the input to the op amp could be a higher voltage than the supply voltage, a digital potentiometer will be needed to automatically adjust the gain of the op amp. These only work up to to the supply voltage.
33Silicon Labs, Single-chip USB to UART Bridge.
34Various configuration words would have to be moved to registers to initialise USART communication at the start of the program, but beyond that there would simply be registers for writing data, reading data and checking if data is available to be read
35mik3y, usb-serial-for-android.

the microcontroller from an Android application via a serial port³⁶
Because the connection is wired, there would be minimal interference so the speed could potentially go as high as the maximum USB 2.0 bit rate³⁷ of 480 Mbit s−1
However, there would be a major disadvantage to this approach: that the oscilloscope would have to be physically connected to the tablet. This means the tablet would not be able to be freely moved around while using the oscilloscope. While a traditional oscilloscope operates this way, allowing wireless connection would make the oscilloscope much more vertasile: for example, the relatively cheap oscilloscope hardware could be left permanently connected in a hard-to-access electronics project, and accessed wirelessly when needed through the Android tablet.

### WiFi

It would be far beyond the scope of this project to communicate just using a 2.4 GHz antenna, so instead a discrete WiFi module would be needed. These have traditionally been relatively expensive³⁸, however Texas Instruments has recently released the CC3000, a module much cheaper than the competition.³⁹
If the initial project was being created on a custom PCB, then the CC3000 could simply be included as a component on the PCB. However, the prototype is being created on a breadboard, so a breakout board (a board that contains the CC3000 and an antenna and exposes a digital interface to the CC3000 via pins that can fit in a breadboard) is needed.
The cheapest, most widely available breakout board is Adafruit’s ‘Adafruit CC3000 WiFi Breakout with Onboard Ceramic Antenna‘. Adafruit are a US-based company, but the board can be easily obtained in the UK via eBay. However, it costs £25.
In terms of complexity, using the CC3000 would be more complicated than using USB, but not insurmountably so. Libraries exist for both AVR and PIC microcontrollers to interface with the CC3000, and on the Android side it would simply require interfacing with a TCP socket⁴⁰ (not significantly more complex than communicating via a USB serial connection).
One advantage WiFi has over USB is that it offers a wireless connection, negating the main disadvantage of USB. In addition, it would be able to offer very fast data transfer

36Serial ports are a throwback to the times when computers had physical RS232 serial connections, over which data could be sent and received using a very simple protocol. Nowadays, serial ports are virtual ports that send and receive data over much more complicated protocols such as USB and Bluetooth. 37Baud rate figures are not officially available, but it’s clear from the bit rate that it would be extremely high
38So much so that for a time in the mid-2000s it become very common for devices such as amateur robots to communicate with computers over the 2.4 GHz spectrum, but using a different protocol to WiFi. This author has not been able to find out why such devices were significantly cheaper than WiFi devices, but one suspects it is due to both the complexity of the WiFi protocol and licensing costs required to implement it.
39Benchoff, Finally, TI is producing simple, cheap WiFi modules.
40Again, TCP sockets are significantly outside the scope of this project, but they can essentially be thought of as virtual counterparts to physical sockets. A wire can be used to connect physical sockets together to allow communication between them, and a protocol such as TCP (the base protocol for the internet) does the same thing for virtual sockets.

rates like USB (also like USB, official baud rate figures are not available, but the latest standard⁴¹ offers a bit rate of up to 600 Mbit s−1
).
However, the main disadvantage is the price. Even with the CC3000, the cheapest available option, at £25 the WiFi module would make up a considerable amount of the total cost of the oscilloscope.

### Bluetooth

Like with WiFi, discrete Bluetooth modules are readily available. These operate in a similar way to the USB CP2102 — the microcontroller communicates with the module via USART, and the Android device via a serial port.
One example of such a module would be a JY-MCU HC-06. Via eBay, these are available relatively cheaply (about £5).
This means one key advantage of Bluetooth is simplicity. The inbuilt USART functionality of the microcontroller can be used on the microcontroller side, and a Bluetooth serial library used on the Android side. The heavy lifting of the Bluetooth communication is done by the HC-06 and software built into the Android device.
Bluetooth obviously offers a wirelesss connection, and should work up to about 10 m. The maximum baud rate supported is 1.3824 Mbit s−1
, which is slower than both USB and WiFi but fast enough for our purposes (remember the oscilloscope takes 8-bit samples at 500 kHz so the sampling rate is only 4 Mbit s−1
).

### Chosen Solution

The required wired connection between the oscilloscope and Android device ruled out USB, leaving WiFi and Bluetooth.
Data transfer speeds are not a big issue in this use case, and Bluetooth’s 1.3824 Mbit s−1 is certainly fast enough. This means the key differences between Bluetooth and WiFi are complexity and cost. Bluetooth wins both of these, so Bluetooth was chosen as the communication method between microcontroller and Android device.

41802.11n, which is supported by most wifi devices nowadays

# System Development

## 2.1 Subsystems

The system will be split up into a number of subsystems, shown in fig. 2.1. Each of these subsystems is described in more detail in the sections below, and a brief description is given immediately below.
- Two analogue input channels come into the system, and are amplified and offset by amplification circuitry (with the gain controlled by a central microcontroller).
- These channels are both sampled using an Analogue to Digital Converter, which feeds into the microcontroller.
- A number of digital inputs are also fed straight into the microcontroller
- Through a Bluetooth transceiver, an Android device interacts with the microcontroller, receiving samples of both the analogue and digital inputs and controlling things such as the sampling rate and amplifier gain.

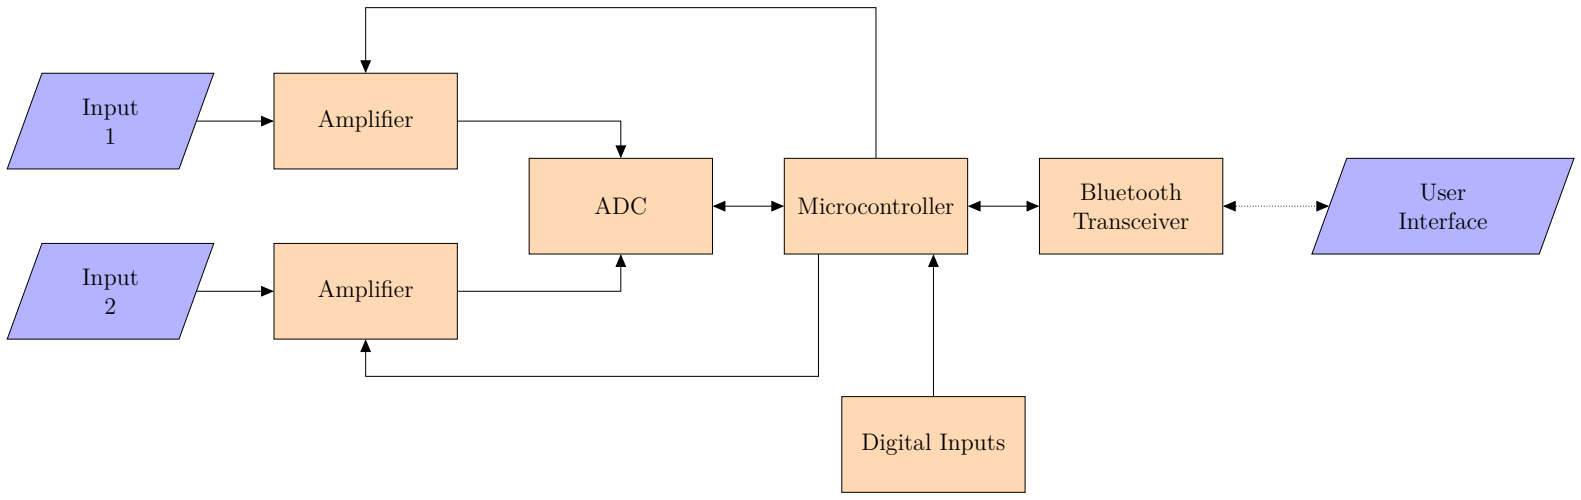
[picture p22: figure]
. Input 1; Input 2; Amplifier; ADC; Microcontroller; Digital Inputs; Bluetooth Transceiver; User Interface

Figure 2.1: Subsystems within the oscilloscope

20

### 2.1.1 Analogue Inputs

For the purposes of this project wires are sufficient, however in a real-life scenario highimpedance, low-inductance test probes (usually coaxial cable) should be used.

### 2.1.2 Amplifiers

Each amplifier will have two purposes:
- To amplify the signal based on the Voltage Control of the oscilloscope. This is needed so the user can input a range of different voltage signals.
- To shift the signal so the minimum voltage is 0 V, rather than some negative voltage. This is required because the ADC will only accept an input greater than 0 V. The chosen ADCs require an input voltage between 0 V and 5 V¹
. A non-inverting summing amplifier would not be suitable beause the offset added to the signal needs to remain constant while the gain changes, so instead the amplifier will be split into two stages.
The first stage will amplify the signal and offset it to be between 0 V and −5 V, below which the op-amp will saturate.
The second stage will invert this signal with a voltage gain of −1, meaning the output voltage will be between 0 V and 5 V as required.

First Stage

Circuit This stage will be implemented using a summing amplifier, with the inputs consisting of the input signal and a fixed voltage (for the sake of simplicity, the 5V supply wil be used).
See fig. 2.2 for a circuit diagram.

Component Calculations Suppose that the input signal varies from −V1 to +V1, and the amplifier has a gain of A and an offset of B. Then the output voltage Vo will be given by

−Vo =

Rf
R1

Vi +

Rf
R2
- 5 V

The first term will range from −A · V1 to +A · V1, and the second term will be B. So −Vo will range from B − A · V1 to B + A · V1. Choosing a value of B = 2.5 V means that −Vo will vary equally above and below 2.5 V, as we want²
(because the voltage must be between 0 V and 5 V, and 2.5 V is the midpoint of those two).

1The maximum voltage is actually VREF +, which will be connected to VCC for simplicity, which in this case is 5 V
2The op amp will saturate before outputting a voltage above 5 V, so we don’t need to worry about this. If the gain or input voltage is sufficiently large, −Vo could fall below 0 V. This means the next stage must saturate at 0 V and not output negative voltages, whatever the input.

Rf and R2 will be fixed to give Rf
R2

= 0.5 to get the required offset. R1 will be a digital potentiometer acting as a rheostate (variable resistor), allowing the microcontroller to control the gain of the amplifier.
The input voltage range is from ±50 mV to ±5 V, so the gain A =

Rf
R1

must vary from
0.5 to at least 50. Digital potentiometers are readily available in a number of values, so the standard 10 kΩ option will be chosen. This means the potentiometer can vary from the minimum resistance (usually 75 Ω) to 10 kΩ.
Using the values for A and R1, this gives a value of Rf = 5 kΩ, meaning A will range from
5 kΩ

10 kΩ = 0.5 to 5 kΩ
75 Ω ≈ 66.7, as required. In turn, this gives a value of R2 = 10 kΩ.

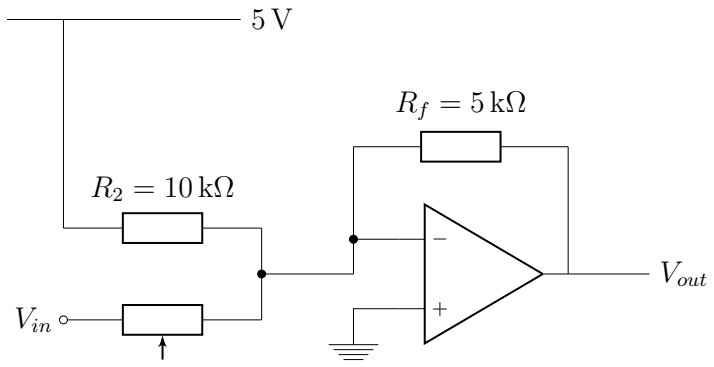
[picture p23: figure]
Vin; Vout

R1 ∈ [75 Ω, 10 kΩ]

Figure 2.2: First stage amplifier circuit diagram

Component Selection The Microchip MCP4131-103E/P will be used for the digital potentiometer. It offers enough precision (typically 0.25%), offers a simple interface for changing the resistance (SPI) and is cheap and readily available in a PDIP package. Additionally, free samples are available from Microchip. To make the component calculations made earlier work, the 10 kΩ MCP4131-103 variety will be used.
The op-amps should be of rail-to-rail type (i.e. they can saturate at almost 0V and Vs) and be able to cope with Vs = 5 V, Vi = 5 V and input frequencies of up to 1 MHz. The Analog Devices AD8031 meets all of these requirements (at 1 MHz it gives an open-loop gain of almost 25 dB) and is also cheap and readily available in PDIP packaging. Due to the availability of free samples, 2 AD8032ANZs (consisting of two AD8031 op amps in each chip) will be used.

Second Stage

This stage simply has to invert the previous stage, saturating at 0 V and 5 V. For this we can use a simple inverting amplifier.

Vout =

Rf
R1

Vin

Choosing a standard value of Rf = 10 kΩ, we obtain R1 = 10 kΩ. As detailed in the previous section, AD8031 op amps will be used.

See fig. 2.3 for a circuit diagram.

−

+

R1 = 10 kΩ

Vin

Rf = 10 kΩ

Vout

Figure 2.3: Second stage amplifier circuit diagram

Simulation

To check the frequency response of the amplification circuit, it was simulated using LT-Spice (see fig. 2.4).
To test the simulation, a low frequency sine wave was applied, and as expected the output was a sine wave of amplitude 2.5 V between 0 V and 2.5 V. The resultant waveform can be seen in fig. 2.5. A FFT was then applied to this waveform to obtain the frequency spectrums seen in fig. 2.6. As required, the spectrum of the output was identical to the spectrum of the input, with the slightly lower amplitudes being due to a lower wave amplitude (2.5 V c.f. 5 V).
A frequency sweep was then applied to produce a Bode plot. The details of such a plot are beyond the scope of this project, but let us just note that the gain is very consistent across all frequencies we’ll be using (as predicted: the op amp has a stated bandwidth of 80 MHz, much higher than 1 MHz), and while it becomes almost 9° out of phase at very high frequencies, this is not an issue for this project³

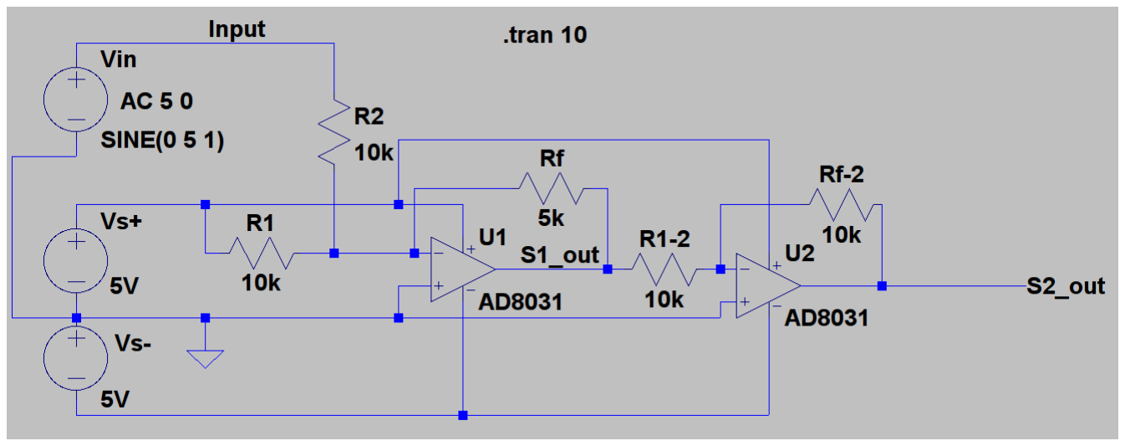
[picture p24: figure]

Figure 2.4: Amplification circuit in LTSpice

3The phase is only important to the oscilloscope when comparing the phase of two signals. To see two signals on screen at the same time base, their frequencies must be close enough together that they’re both out of phase by approximately the same amount. Hence their phase difference is unchanged


Figure 2.5: Waveform produced by amplification circuit at 1Hz (blue = original, red = first stage output, magenta = second stage output)

24


Figure 2.6: FFT of waveform produced by amplification circuit at 1Hz (red = original, blue = first stage output, magenta = second stage output)

25


Figure 2.7: Frequency response of amplification circuit

26


Figure 2.8: Power connections for the MAX114⁶

### 2.1.3 ADCs

As discussed before, these should be able to sample at up to 1 MHz. The only readily available ADCs that can do this in PDIP packaging and have free samples are the 8-bit half-flash⁴ Maxim Integrated MAX114 ADCs.
There are a number of modes the ADCs can be operated in, however the pipelined mode offers a very good compromise between complexity and speed. The full details are in Maxim Integrated (MAX114/MAX118 Datasheet), but as the ADCs are operated from a microcontroller in which there’s a delay of 62.5 ns (assuming a 16 MHz clock) between each instruction, the operating procedure can be simplified to the following:
1. Use A0 and A1 to choose the input signal (00 for input 0, 01 for input 1, the only two inputs used in this project)
2. Pull CS, RD and W R⁵
low
3. Wait approximately 250 ns
4. Pull CS, RD and W R back high
5. Read in a sample from D0 through D7
Taken directly from the datasheet, section 2.1.3 shows the connections that must be made to power the MAX114 and provide it with a reference voltage.
Additionally, PW RDN must be kept high to keep the ADC powered on, and MODE must be kept high to keep the ADC in Read-Write mode (of which pipeline mode is a subset).

### 2.1.4 Microcontroller

Due to this author’s significant previous experience with AVR microcontrollers, one will be used as there are no significant disadvantages over a PIC. The main requirements the microcontroller needs to satisfy are:
- Ability to use a 16 MHz clock
- Inbuilt UART communication (to communicate with the Bluetooth module)
- A significant number (at least 20) input/output pins

4Similar to flash ADCs, but requiring ≈ 2

n
2 as opposed to ≈ 2

n parts
5For simplicity, CS, RD and W R can all be physically tied together and connected to just one microcontroller input


Figure 2.9: Breadboard diagram produced by Arduino (ArduinoToBreadboard) showing the programming and power connections between an Arduino and an ATMega328

- At least 1 kbyte of SRAM (to store the 8192 bits of samples)
- Availability in a PDIP package
The ATMega328 (more commonly known as the chip powering most Arduinos) was chosen because it satisfies all of these requirements and this author had a number of spare chips not being used.

Circuit

For the chip to operate, a 16 MHz crystal oscillator must be connected between XT AL1 and XT AL, with a 22 pF capacitor from each pin to ground. Additionally, the following power connections must be made:
- RESET to 5 V through a 10 kΩ resistor
- Both GNDs to ground
- V CC and AV CC to 5 V
To program the chip, an AVR programmer must be used. These are available very cheaply (such as the USBASP for £5 from eBay), but an Arduino (essentially a microcontroller development board) can also be used, as shown in section 2.1.4. As this author had a spare Arduino, this option was used.

Serial Interface

The following protocol was designed for serial communication between the Android device and the microcontroller. After taking a full 1024 samples, the microcontroller checks the serial buffer for one of the following commands and acts on it, responding via serial if necessary.
Traditionally, serial is a textual interface, however for efficiency’s sake in this case it was used as a binary interface. Each transmitted character is stored as an 8-bit character, so the protocol is based on the integer values of those characters. For example, 65 below corresponds to a capital ‘A’.
0x00 Return all samples for the first analogue channel (1024 bytes, followed by a newline.⁷
)
0x01 Return all samples for the second analogue channel (1024 bytes, followed by a newline)
0x02 Wait for the next transmitted byte, X, and return all values for the Xth digital channel (1024 bits = 128 bytes, followed by a newline)
0x03 Use analogue channel 1 to trigger (returns a newline)
0x04 Use analogue channel 2 to trigger (returns a newline)
0x05 Wait for the next transmitted byte, X, and use the Xth digital channel to trigger (returns a newline)
0x06 Wait for the next two transmitted bytes, X and Y and use XY ⁸ as the number of microseconds to pause in between samples (returns a newline)
0x07 Wait for the next transmitted byte, X, and use X as the analogue trigger threshold (returnsa newline)
0x08 Wait for the next transmitted byte, X, and use the 7 least significant bits of X as the digital pot value in an amplifier (if the most significant bit of X is high, the second amplifier circuit, otherwise the first amplifier circuit) (returns a newline) 0x09 Enable analogue channels 1 and 2 (this means slower sampling) (returns a newline) 0x0A Noop (this is the newline character) (returns a newline)
0x0B Enable analogue channel 1 only (faster sampling) sampling) (returns a newline) So, for example, to receive samples for the second analogue channel the Android device would have to send 0x01, then store the next 1024 received bytes.

ADC Communication

The way in which the microcontroller will communicate with the ADC is described in section 2.1.3.

7The character used to indicate a new line should start in text on a computer. Here, it’s just equivalent to 0x0A
8For example, if X = 0x50 and Y = 0x1A then use 0x501A as the delay

Digital Potentiometer Commmunication

The resistance of the digital potentiometers is set using an SPI interface. While the details can get more complicated, SPI (Serial Peripheral Interface) is essentially a very simple interface, consisting of four pins: SCLK, MOSI, MISO and SS.
There are two devices: a master and a slave. SCLK is simply a clock output from master. On either the rising or falling edge of SCLK, a bit of data is transmitted from master to slave on MOSI and slave to master on MISO. SS is simply an active low slave select (i.e. the slave only communicates when SS is low).
There are four different SPI modes, of which the digital potentiometers support two (CP OL = 0 = CP HA and CP OL = 1 = CP HA). In both modes, data is captured on the rising edge and propogated on the falling edge. The difference is simply the first value of the clock: in the first mode, it’s low, and in the second it’s high.
The maximum clock supported by the digital potentiomers is 10 MHz, which is faster than we can reliably communicate at with a 16 MHz microcontroller anyway.
To send a 16-bit byte to the digital potentiometer the following must be done:
1. Pull SS low
2. Wait one SCLK period
3. Starting from a high (an artbitrary choice), pulse SCLK
4. On each falling edge, send a bit of data until 16 bits have been sent
5. Pull SCLK back high
6. Wait one clock period
7. Pull SS back high
More | on | digital | pot. | communication

Program

To perform all of the above tasks, then, the microcontroller will need to run the following program:
- Loop forever:
– Loop 1024 times:
* Take sample from first analog channel
* Take sample from second analog channel, if enabled
* Take 1-bit sample from each digital channel
– Look at most recent serial command, and perform any actions and send any data it specifies
– Clear most recent serial command
- Interrupt on serial byte received:
– Store as most recent serial command
– Receive up to 2 more bytes depending on the command

### 2.1.5 Bluetooth Transceiver

As discussed in section 1.5, Bluetooth was chosen to communicate with the Android device acting as the user interface. In particular, the JY-MCU HC-06 was chosen.

### 2.1.6 User Interface

A high-quality enough screen that interfaced directly with the microcontroller would be quite expensive, so instead an Android device was chosen as the user interface.
Android was chosen over the alternatives (iOS, etc) primarily because it’s the most popular mobile operating system, allowing the greatest number of people to use the oscilliscope. Additionally, it allows easy and open development, whereas competitors such as iOS require costly developer licenses, proprietary software and specific hardware.

## 2.2 Construction

Initially, a number of the subsystems were built individually on breadboards. This allowed the basic circuit details to be checked without requiring an infeasibly large circuit to be built on a breadboard.

### 2.2.1 PCB Layout

Once this prototype verification step was performed, the PCB was laid out on a breadboard. This process consists of three main steps: inputting the schematic into the computer, laying out the schematic components onto the board and routing traces (the PCB equivalent of wires) between the components.
Initially this was attempted using a piece of software called Eagle. A significant number of electronics projects use Eagle, from small hobbyist projects right up to industrial products. However, as this author started to lay components onto the PCB using Eagle, one encountered an error: the free version of Eagle only allows a maximum PCB size of 100 mmx80 mm. For reasons discussed later, the PCB size needed to be 100 mmx100 mm. The cheapest paid-version of Eagle is $169, meaning it was much too expensive to purchase for the sake of this project. Instead, an alternative was sought.
This author researched and briefly evaluated two alternatives: KiCAD and DipTrace. KiCAD is a piece of open source software, meaning it’s free to use 9
, and DipTrace, a

9There are two disctinct definitions of free that should be considered here: gratis free (without cost to the user, this is somewhat confusingly also called free as in beer) and libre free (without compromise to the user’s liberties, this is also known as free as in speech and essentially means that the user has the right to run the software however they want, as well as the right to modify it, meaning the source code is freely available. Software that’s Free (with a capital F) is also known as open-source software (there are major differences between the two terms, however for the purposes of this explanation the reader can consider them identical) is both free as in gratis and free as in libre, and common examples include LibreOffice (hence the name) and GNU/Linux (the operating system running everything from the majority of super computers to televisions to traffic lights). For more on this subject, see Richard Stallman’s book ‘Free as in Freedom’, which is also Free and hence freely available on the internet.

commercial piece of software with a free version available limited to 2 signal layers¹⁰ and 300 pins¹¹
Both are very capable pieces of software, and KiCAD would certainly be favourable for philosophical reasons. Howerver, the majority of the ICs used in the circuit are relatively uncommon. This means that CAD footprints (files containing the physical dimensions of the chip) are not readily available, so they must be manually created for each IC instead. This is a much quicker process in DipTrace than in KiCAD (and indeed than in Eagle), and for this reason alone DipTrace was chosen.
There were no major issues in creating the circuit schematic in DipTrace, although a number of revisions were required for small improvements. Laying out the PCB and routing the traces was much harder. DipTrace contains tools to automatically place and route, however the electrical engineering community strongly recommends against using auto routers. Placing and routing is a task that’s extremely hard for a computer to find an optimal solution to¹². While software can make use of heuristics¹³, it’s a commonly held belief that even the best autorouting software pales when compared to a human with a small amount of experience (it may help to think of PCB routing as art: while a computer can be programmed to come up with pieces of art, even a small child can create much better ones).
Because of this, your author set about learning how to place and route PCBs. The American electronics retailer Sparkfun provide a number of online tutorials and videos regarding PCB routing which were extremely helpful. Eventually, the PCB was routed, and while an expert would have done much better it sufficed for the purposes of this project (particularly as there were no high voltages or high-speed signals (≥ 50 MHz) involved). To finish the board, mounting holes and silkscreen¹⁴ (the explanatory text and markings on a PCB) were added.
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

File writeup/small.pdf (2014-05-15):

## Electronics A2 Project

# Android-based Bluetooth Oscilloscope

Bioniscope

### Author:

Harry Rickards

## c b a

2014

# Contents

1 Problem Analysis and Solution Design | 3
2 System Development | 20
3 Testing | 56
4 Evaluation | 61
A Fourier Series of a Square Wave | 62
B PIC Code | 64

1

# List of Figures

1.1 Existing oscilloscopes | | 3
1.2 Logic Analyser Example Output | | 4
1.3 Equivalent Time Sampling Diagram | | 6
1.4 CRO Test Setup | | 8

### 1.5 CRO test waveform | 10 1.6 Square Wave Harmonics | 11 1.7 Bluetooth Experiment Setup | 13 2.1 Oscilloscope Subsystems | 21 2.2 Power supply circuit diagram | 23

2.3 1st Amplifier Stage | 25
2.4 2nd Amplifier Stage | 26

2.5 Amplification Circuit Simulation | 27 2.6 Amplification Circuit Waveform | 28 2.7 Amplification Circuit Frequency Spectrum | 29 2.8 Amplification Circuit Bode Plot | 30 2.9 Amplifier circuit diagram | 31 2.10 ADC Circuit Diagram | 32 2.11 ADC Power Connections | 33 2.12 Microcontroller Circuit Diagram | 34 2.13 Analogue waveform shown in Android Bioniscope app | 40 2.14 Digital timing diagram shown in Android Bioniscope app | 41 2.15 Analogue frequency spectrum shown in Android Bioniscope app | 42 2.16 PCB (traces) | 49 2.17 PCB (3D render) | 50 2.18 PCB (Mockup) | 51 2.19 The final enclosure, with the circuit inside | 53 2.20 The final circuit | 54 2.21 The final circuit in action | 55 3.1 Frequency spectrum of square wave, as expected | 57 3.2 The bandwidth-constrained square wave after passing through the ana-
logue circuitry | 59

### 3.3 Circuit diagram for the op amp circuit added to fix the issue with negative

signals | 59

### 3.4 Breadboard photo of the op amp circuit added to fix the issue with negative

signals | 60
A.1 Square wave | 62

2

# Problem Analysis and Solution Design

## 1.1 Problem Definition
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

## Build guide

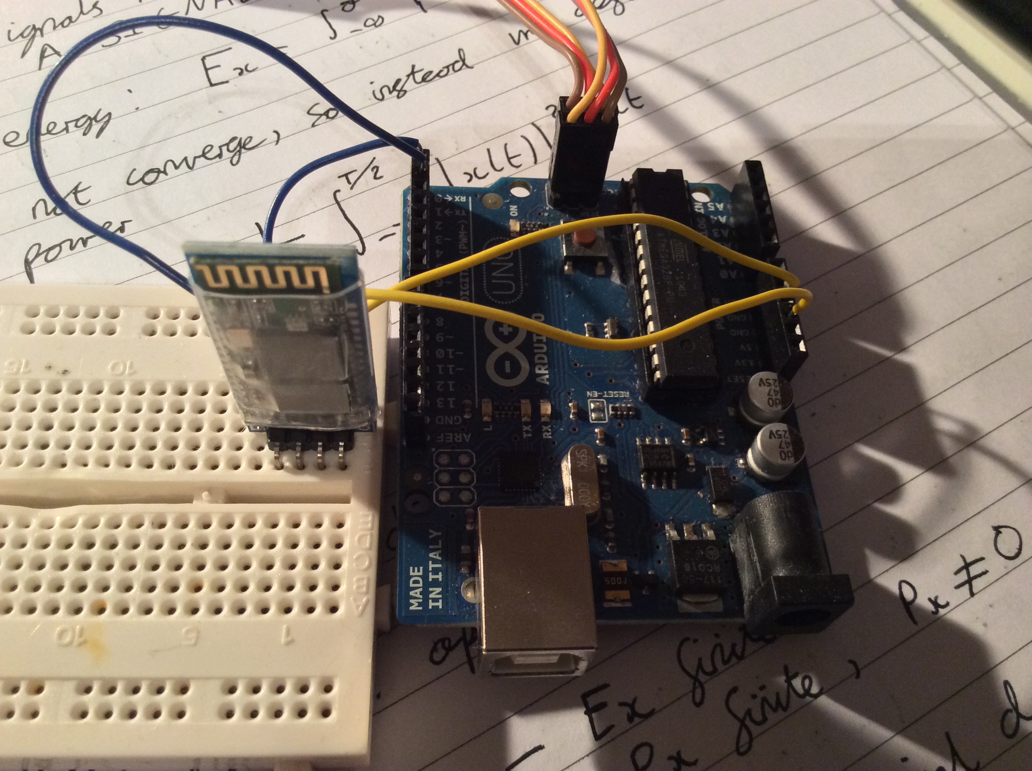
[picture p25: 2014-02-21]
writeup/img/bluetooth/setup.jpg

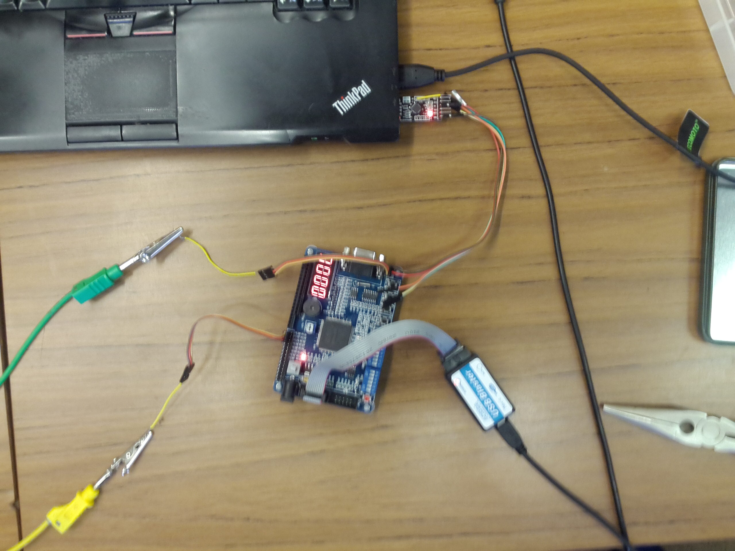
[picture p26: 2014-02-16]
experiments/oscilloscope/setup_10.jpg

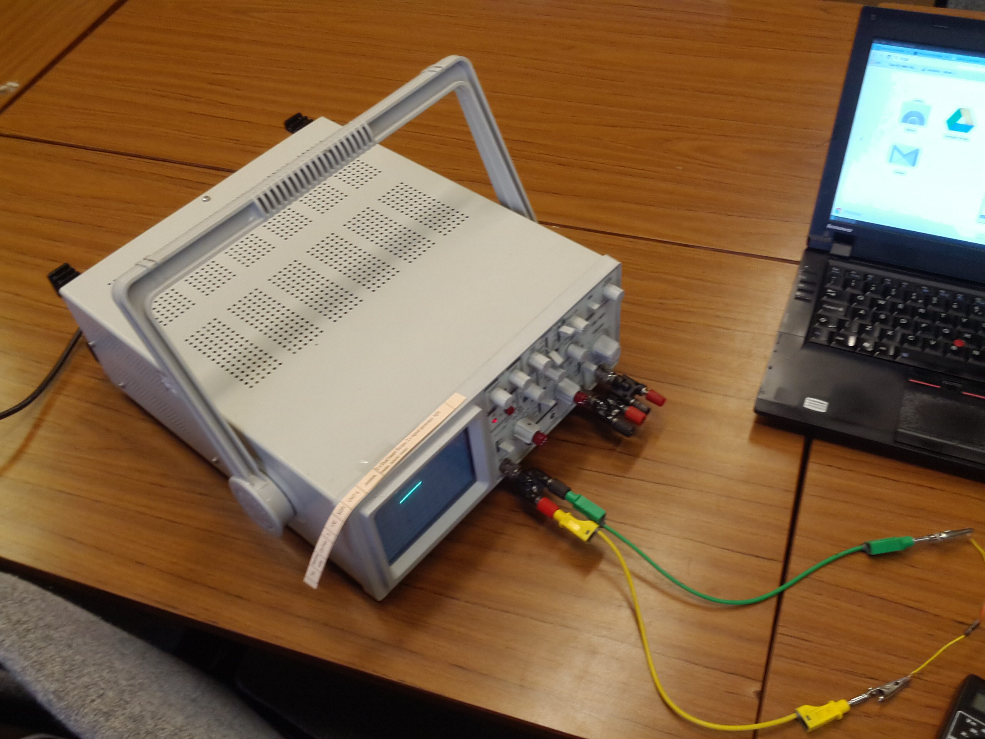
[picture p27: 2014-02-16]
experiments/oscilloscope/setup_04.jpg

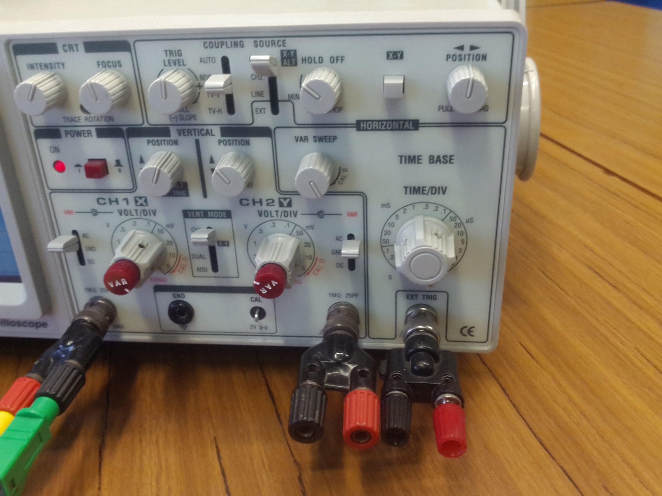
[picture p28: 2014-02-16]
experiments/oscilloscope/setup_01.jpg

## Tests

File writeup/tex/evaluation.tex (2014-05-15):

\chapter{Evaluation}

As detailed in~\cref{sec:initialCriteriaMet}, all initial criteria were met and
system testing verified this.

The aim of this project was to create a Digital Sampling Oscilloscope, and that
aim certainly succeeded. While it may not be the fastest or most accurate DSO
available it's relatively unique in that it communicates with an Android tablet.
The total cost (estimated to be about \pounds 35 if free samples were not
available) also comes to much less than other DSOs, even the cheapest of which
cost hundreds of pounds.

There were two other secondary aims of the project: to generate frequency
spectrums and to have basic logic analyser capability. As seen in the testing
and general screenshots, frequency spectrums are certainly generated. While
their accuracy was not numerically tested as in-depth as the waveforms, the
spectrums are generated from the waveforms using an industry-standard algorithm
so will have the same standard of accuracy.

Basic logic analyser functionality was also implemented. At the moment, only
timing diagrams can be displayed and no triggering functionality exists, which
makes it less useful than a standalone logic analyser but still much better than
a standard CRO. In the future, more advanced triggering could be implemented, as
well as things like packet decoding (so data packets can be decoded and
displayed all inside the logic analyser). This could all be implemented in
software, so the hardware would not need to be modified.

\section{Report Production}

This report was produced in \LaTeX. Whilst offering many advantages over
alternatives that could have been chosen (such as Microsoft Word), \LaTeX offers
superior typesetting, referencing and integration of mathematical equations and
figures.

For more information on \LaTeX, please consult a resource such as
\url{http://www.sharelatex.com}.

As indicated on the front cover, this report is licensed under a Creative
Commons Attribution-ShareAlike 4.0 International License. See
\url{https://creativecommons.org/licenses/by-sa/4.0/} for full details, but
essentially one is allowed to share and adapt this work, even commercially, as
long as attribution is given and the resultant work is distributed under the
same license. The circuit and PCB is also licensed under CC BY-SA 4.0, and the
Android application is licensed under the GNU General Public License 3.0 (the
`traditional' open source license).

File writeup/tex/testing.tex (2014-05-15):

\chapter{Testing}
\section{Test Procedure}
\subsection{Overall System}
\label{sec:overallSystemTesting}

Three different tests will be done to test the overall system. To run these
tests a square wave and a sinusoid wave will be produced using a signal
generator at \SI{100}{\Hz}, \SI{1}{\kHz}, \SI{2}{\kHz}, \SI{5}{\kHz} and
\SI{10}{\kHz}. The signal generator has an accuracy of 2 decimal places, or
between \SI{1}{\Hz} and \SI{100}{\Hz} in this test. While the error is not
explicitly stated, the signal generator is a commercial product so the error
will be less than \SI{1}{\Hz} (the accuracy).

To reduce error, all measurements will be repeated 3 times and an average value
found and recorded. While the oscilloscope has a high enough impedance,
capacitance and inductance that they may have an effect on the test signal, the
signal generator will take this into account when calculating the signal
frequency.

The sinusoid wave will be fed into the oscilloscope at each different frequency,
and the time period and amplitude recorded from the waveform view. These will be
compared to the known values to compute an accuracy value for the oscilloscope.
Data will be recorded in~\cref{tab:analogueWaveData}.

\begin{table}
  \centering
  \begin{tabular}{SSSSSS}
    \toprule
      \multicolumn{3}{c}{Frequency (\si{\kHz})}&\multicolumn{3}{c}{Amplitude (\si{\V})}\\
      \cmidrule(lr){1-3} \cmidrule(lr){4-6}
      {Actual} & {Measured} & {\% error} & {Actual} & {Measured} & {\% error}\\
      \midrule

      0.101 & 0.0963 & 4.65\% & 4.9 & 4.8 & 2.04\% \\
      1.01 & 1.01 & 0.00\% & 4.9 & 4.8 & 2.04\% \\
      1.99 & 2.04 & 2.51\% & 4.9 & 4.7 & 4.08\% \\
      5.01 & 5.11 & 2.00\% & 4.9 & 4.8 & 2.04\% \\
      10.1 & 10.1 & 0.00\% & 4.9 & 4.8 & 2.04\% \\

      \bottomrule
  \end{tabular}
  \caption{Results from analogue wave testing}
  \label{tab:analogueWaveData}
\end{table}

Similarly, the square wave will be fed into the oscilloscope and the time period
recorded from the digital view. This will be compared to the known value to
compute an accuracy value, and data will be recorded
in~\cref{tab:digitalWaveData}.

\begin{table}
  \centering
  \begin{tabular}{SSS}
    \toprule

    \multicolumn{3}{c}{Frequency (\si{\kHz})}\\
    \cmidrule(lr){1-3}
    
    {Actual} & {Measured} & {\% error} \\

    \midrule

    0.100 & 0.110 & 10.0\% \\
    1.06 & 1.00 & 5.66\% \\
    2.00 & 2.02 & 1.00\% \\
    4.99 & 4.43 & 11.2\% \\
    10.0 & 8.40 & 16.0\%\\
    \bottomrule
  \end{tabular}
  \caption{Results from digital wave testing}
  \label{tab:digitalWaveData}
\end{table}

The square wave was also fed into the analogue input and the scope switched to
spectrum mode. As seen
in~\cref{fig:actualSquareSpectrum} the spectrum
looked exactly as one would expect for a square wave signal (based on the
prediction made from~\cref{sec:squareWaveFourierSeries}).

\begin{figure}[h]
  
  \caption{Frequency spectrum of square wave, as expected}
  \label{fig:actualSquareSpectrum}
\end{figure}

\subsubsection{Results}

Looking at the data above, error values are reasonably consistent so there are
no outliers that need to be taken care of.

Taking means, we find the average error to be 8.8\% for the digital wave and 1.8\%
for the analogue wave. While this would probably not be accurate enough for a
commercial product, it is certainly accurate enough for this project. Besides,
while some of the error undoubtedly comes from inaccuracies in the time delay
code (it has to delay to the nearest whole multiple of \SI{62.5}{\ns} as the
microcontroller uses a \SI{16}{\MHz} clock), the error could almost certainly be
significantly reduced by using compnents with stricter tolerance values (some
are 10\% at the moment).

\subsection{Initial Criteria}
\label{sec:initialCriteriaMet}

Next, the system needs to be checked to ensure it meets the numerical parameters
specified in~\cref{sec:numericalParameters}.

\subsubsection*{Frequency}
As seen above in~\cref{sec:overallSystemTesting}, the oscilloscope is accurate
and copes with a \SI{10}{\kHz} wave as required by the system.

\subsubsection*{Bandwidth}
To check the analogue bandwidth of the system, a \SI{1}{\MHz} square wave will be
produced using a signal generator. This will be input into the oscilloscope,
and a traditional CRO used to measure the output from the analogue circuitry.
Using the figures and working detailed in~\cref{sec:oscilloscopeSquare} we can
compare the visual output to calculate the total bandwidth of the system.

The bandwidth of the CRO is already known to be approximately \SI{20}{\MHz}
(from~\cref{sec:overallSystemTesting}) so provided the calculated bandwidth is
less than \SI{20}{\MHz} we know this is the analogue bandwidth of the
oscilloscope. If it's \SI{20}{\MHz} we know the analogue bandwidth is at least
\SI{20}{\MHz} and hence greater than our requirement of \SI{1}{\MHz}
(from~\cref{sec:numericalParameters}).

As we're counting discrete harmonics here, the frequency of the generated signal
simply needs to be at least 50\% accurate to ensure 100\% accuracy for the
number of harmonics. As a commercial signal generator will be used, it will
certainly reach this level of accuracy. The final answer for the bandwidth will
be accurate to within 1 harmonic of the fundamental frequency. While this is a
significant error, there's no way to reduce this error value without using
specialist equipment (i.e., a traditional RF spectrum analyser) or significantly
increasing the complexity of the test. As we only need to verify the bandwidth
is greater than \SI{1}{\MHz}, this is accurate enough for our purposes.

When the experiment was performed, the CRO showed the output seen in
\cref{fig:scopeBandwidthPhoto}. As
can be seen by comparing to~\cref{fig:squareWaveApproximations}, the square wave
is present to significantly more than the eleventh harmonic. So the bandwidth is
greater than \SI{11}{\MHz}, more than meeting the initial numerical parameters
(which specified \SI{1}{\MHz}).

\begin{figure}[h]
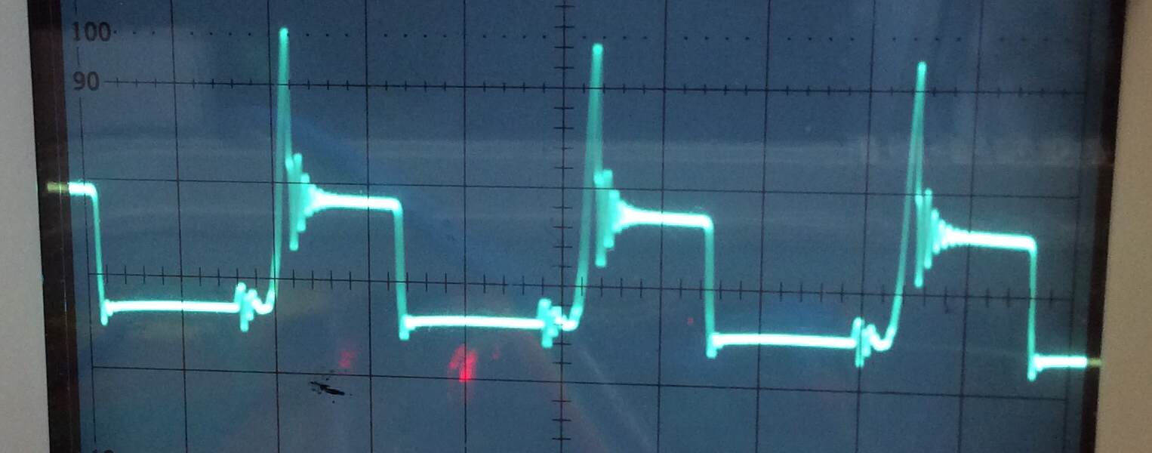
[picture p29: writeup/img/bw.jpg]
  
  \caption{The bandwidth-constrained square wave after passing through the analogue circuitry}
  \label{fig:scopeBandwidthPhoto}
\end{figure}

\section{Initial Assessment of System}

As discussed above, the system met all initial quantitative criteria. However,
while performing the above tests a critical issue was discovered.

Whenever the input signal fell below \SI{0}{\V}, the output from the analogue
circuitry was clipping.  Upon further investigation, it was discovered this was
because the digital potentiometer can only cope with voltages between \SI{0}{\V}
and $V_{SS}$ --- not those below \SI{0}{\V}.

Despite this, the oscilloscope still performed accurately and met the rest of
it's goals. While at this stage it did have limited usefuleness for analogue
signals (as a large number of analogue signals fall below \SI{0}{\V}), this did
not impede the digital performance of the oscilloscope.

To overcome this issue, an op amp circuit was set up to scale a signal by
$\frac{1}{2}$ and add on an offset of \SI{2.5}{\V}. This was implemented using a
standard noninverting summing amplifier, as shown
in~\cref{fig:introCircuitDiagram,fig:introCircuitPhoto}.

\begin{figure}[h]
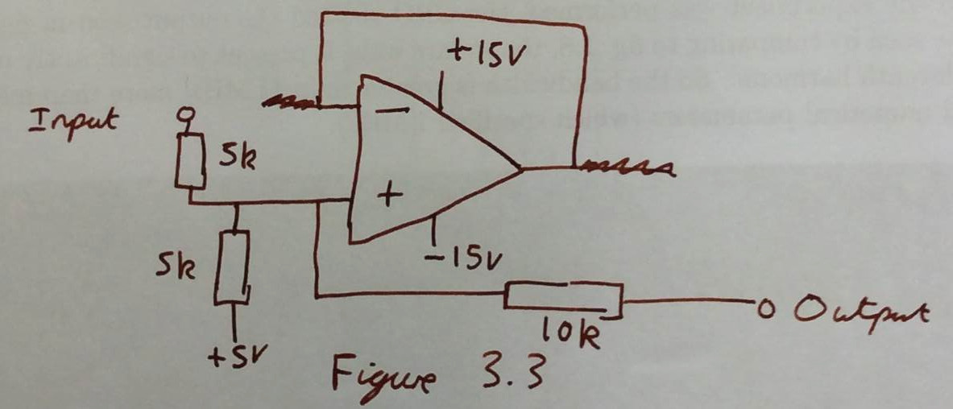
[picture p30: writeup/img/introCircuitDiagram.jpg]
  
  \caption{Circuit diagram for the op amp circuit added to fix the issue with negative signals}
  \label{fig:introCircuitDiagram}
\end{figure}

\begin{figure}[h]
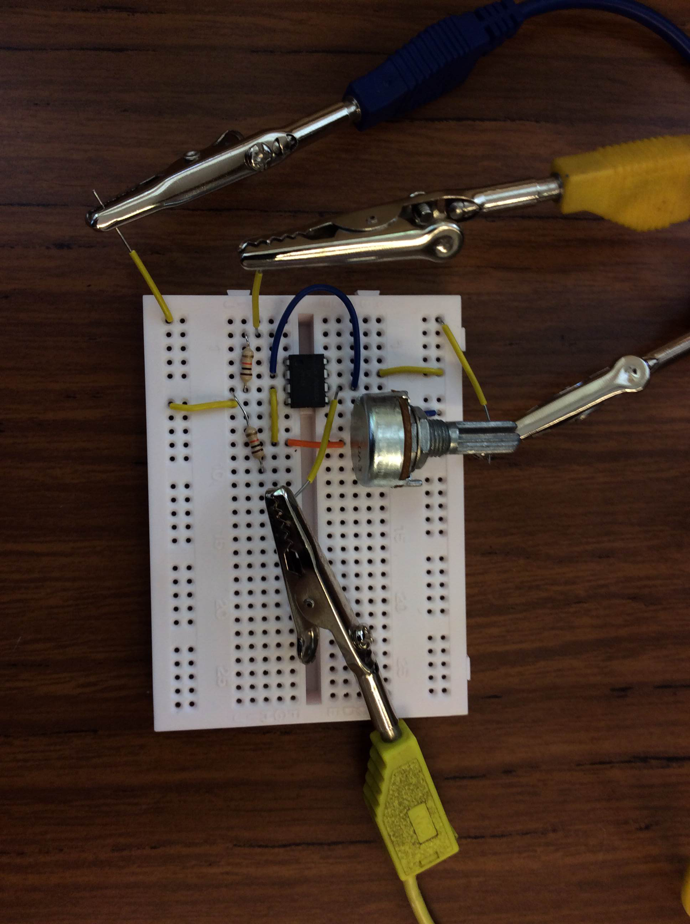
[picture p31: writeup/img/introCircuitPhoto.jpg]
  
  \caption{Breadboard photo of the op amp circuit added to fix the issue with negative signals}
  \label{fig:introCircuitPhoto}
\end{figure}

Now when testing the oscilloscope with signals that fell below \SI{0}{\V} it
worked fine. At this point, the system met all quantitative criteria and also
met the aim of the project: to produce a digital sampling oscilloscope that also
provided basic spectrum analysis and logic analyser functionality.

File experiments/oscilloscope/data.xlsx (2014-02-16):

n | Time/div (us) | Voltage/div (V) | X Divs | Y Divs | Frequency (Hz) | Amplitude (V) | Predicted Frequency (Hz) | Predicted Amplitude (V) | Frequency Error | Amplitude Error
4 | 0.1 | 2 | 3.4 | 2 | 2941176.471 | 2.00 | 3125000 | 1.65 | 5.88% | 21.21%
5 | 0.2 | 2 | 3.1 | 1.8 | 1612903.226 | 1.80 | 1562500 | 1.65 | 3.23% | 9.09%
6 | 0.5 | 2 | 2.5 | 1.8 | 800000 | 1.80 | 781250 | 1.65 | 2.40% | 9.09%
7 | 0.5 | 2 | 5.1 | 1.7 | 392156.8627 | 1.70 | 390625 | 1.65 | 0.39% | 3.03%
8 | 1 | 2 | 5.1 | 1.7 | 196078.4314 | 1.70 | 195312.5 | 1.65 | 0.39% | 3.03%
9 | 2 | 2 | 5.1 | 1.7 | 98039.21569 | 1.70 | 97656.25 | 1.65 | 0.39% | 3.03%
10 | 5 | 2 | 4.1 | 1.7 | 48780.4878 | 1.70 | 48828.125 | 1.65 | 0.10% | 3.03%
12 | 20 | 2 | 4.1 | 1.7 | 12195.12195 | 1.70 | 12207.03125 | 1.65 | 0.10% | 3.03%
14 | 100 | 2 | 3.2 | 1.7 | 3125 | 1.70 | 3051.757812 | 1.65 | 2.40% | 3.03%
16 | 500 | 2 | 2.6 | 1.8 | 769.2307692 | 1.80 | 762.9394531 | 1.65 | 0.82% | 9.09%
19 | 2000 | 2 | 2.7 | 1.7 | 185.1851852 | 1.70 | 95.36743164 | 1.65 | 94.18% | 3.03%

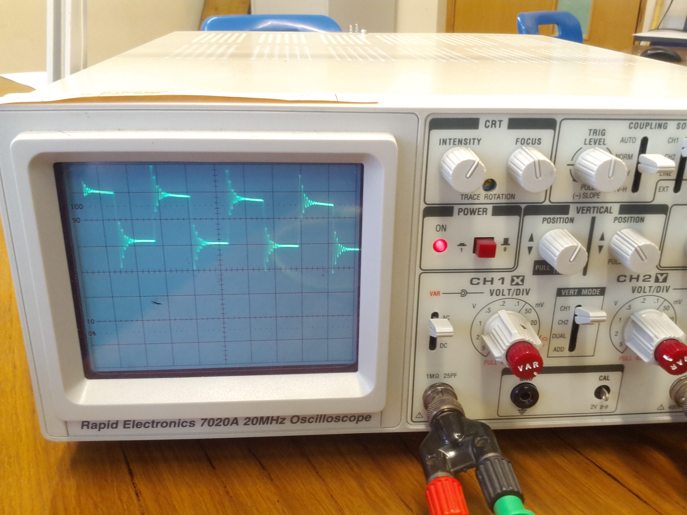
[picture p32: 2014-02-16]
experiments/oscilloscope/measurement_06_02.jpg

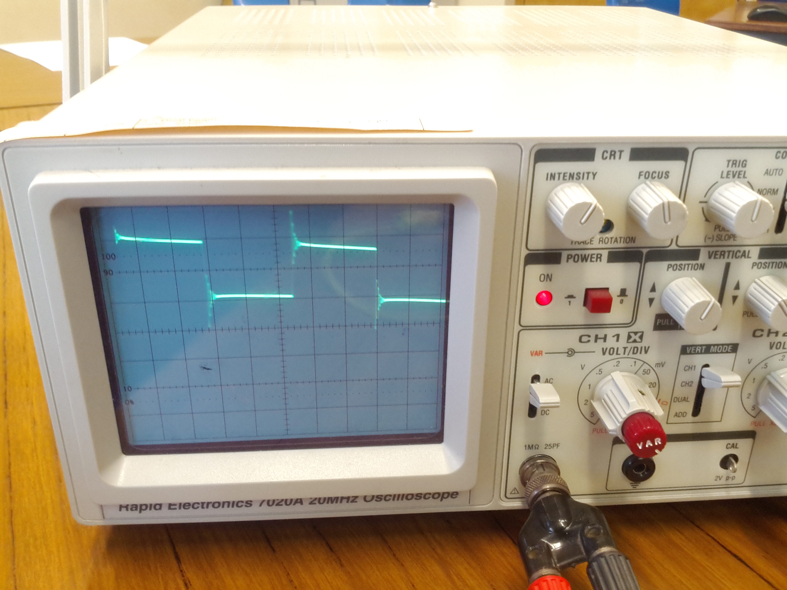
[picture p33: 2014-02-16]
experiments/oscilloscope/measurement_08_01.jpg

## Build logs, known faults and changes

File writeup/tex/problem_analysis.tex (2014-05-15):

\chapter{Problem Analysis and Solution Design}
\section{Problem Definition}
\subsection*{CROs and DSOs}

\begin{figure}[h]
  \centering
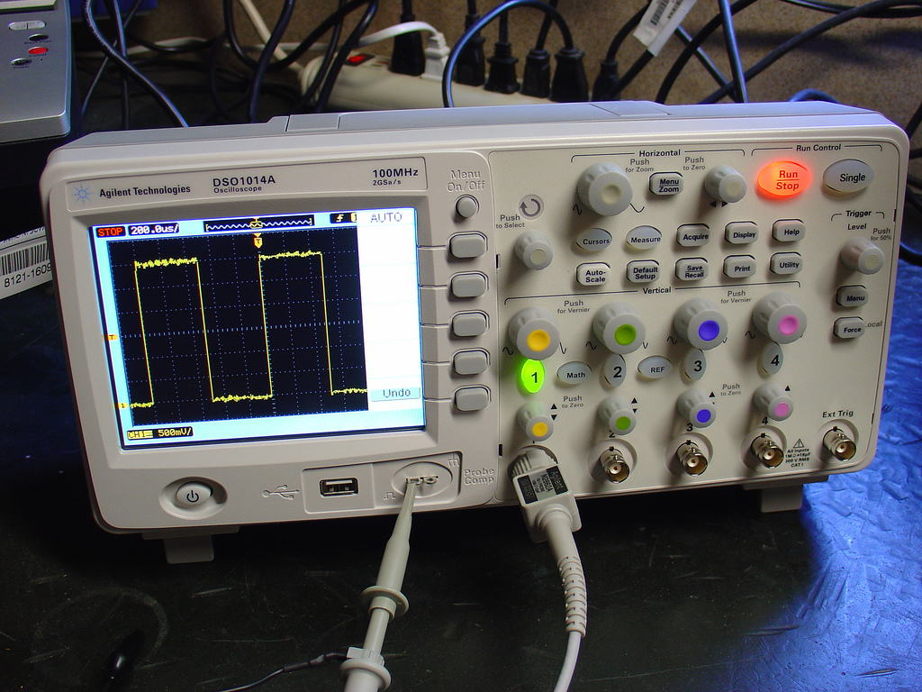
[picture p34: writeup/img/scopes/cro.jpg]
  \subfloat[Cathode Ray Oscilloscope]{}
  \hfill
  \subfloat[Digital Storage Oscilloscope]{}
  \caption[Existing oscilloscopes]{Existing oscilloscopes\autocite{CROPhoto,DSOPhoto}}
\end{figure}

Oscilloscopes available in secondary schools or sixth forms are generally basic
analogue oscilloscopes known as CROs, or Cathode Ray Oscilloscopes (named so
because the display is a Cathode Ray Tube).~\autocite{DoctronicsScopes}

The alternative is a DSO, or Digital Storage Oscilloscope. These work in a very
different way to CROs. Like in a CRO, the input signal is first passed through
some analogue circuitry to amplify it, offset it and so on. However, it's then sampled
into a digital signal using a DAC (Digital to Analogue Converter) and processed
using a microcontroller (perhaps using the help of an FPGA\fdeffpga or a
DSP\fdef{Digital Signal Processor}{a custom microcontroller especially designed
  to perform various \textit{signal processing} functions (e.g., performing a
Discrete Fourier Transform to obtain the frequency spectrum of a signal, or
using Principal Component Analysis to seperate two audio signals)}), before
being output onto some sort of digital screen.~\autocite{TiePieScopes}

\subsection*{Advantages of DSOs}

DSOs offer a number of advantages over CROs. As well as relatively basic
differences such as the traces being much more sharply defined, DSOs allow
digital signal processing to be done on the input signal. This means that, for
example, DFTs (Discrete Fourier Transforms)\footnote{While DFTs are the most
  famous transformations, mainly due to the prevalence of the FFT (Fast Fourier
  Transform) algorithm, in practice DCTs (Discrete Cosine Transforms) are more
  commonly used as they can be calculated more quickly whilst achieving a
similar result} can be run to produce a frequency spectrum of the input signal,
allowing the user to see both time-domain and frequency-domain representations
of the signal.\footnote{This also means that DSOs can be used as basic spectrum
analysers: essentially devices that plot frequency spectrums, these have uses as
far ranging as determining GSM interference when planning mobile phone networks}

Additionally, a DSO can be used to create a basic Logic Analyser. This is
essentially the digital equivalent of an oscilloscope --- a relatively large
number of digital wires and buses are connected to the Logic Analyser and a
timing diagram is output\footnote{In more advanced, standalone Logic Analysers,
more complicated outputs such as decoded Ethernet packets can be
output}.~\autocite{ElectronicDesignMSO}

\begin{figure}
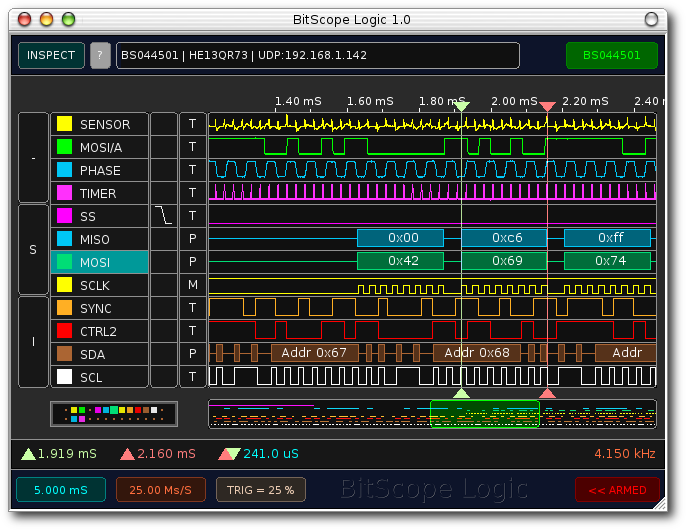
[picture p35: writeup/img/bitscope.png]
  
  \caption[Logic Analyser Example Output]{Example output from a Logic Analyser ~\autocite{Bitscope}}
\end{figure}

\subsection*{Project Definition}

This project\footnote{As seen in various places in this document, the project
  was nicknamed \textit{Bioniscope} --- a portmanteau of bionic (from Android)
and oscilloscope} aims to create a Digital Sampling Oscilloscope, with the following
more advanced features included:

\begin{itemize}
  \item Frequency spectrums of the input signals available
  \item Basic capability as a Logic Analyser
\end{itemize}

From now on, \textit{oscilloscope} will be used to refer to a Digital Sampling
Oscilloscope and CRO will be used to explicitly refer to a Cathode Ray
Oscilloscope.

\section{Research into Existing Oscilloscopes}

Using two articles from \Citeauthor{PicotechScopes}\autocite{PicotechScopes} and
\Citeauthor{GabotronicsScopes}\autocite{GabotronicsScopes}, digital
oscilloscopes can be categorised by the following criteria:

\begin{itemize}

  \item \textbf{Bandwidth} The bandwidth\footnote{Most commonly, bandwidth is
      taken to be the range of fraquencies where the signal has an amplitude
      gain of $\SI{-3}{\dB}\approx 71\%$} in \SI{}{\Hz} of the initial analogue
      stages of the oscilloscope. Common values range from \SI{100}{\kHz} to
      \SI{100}{\MHz}.

  \item \textbf{Type of Sampling} There are two common types of sampling,
    real-time and equivalent-time sampling. With real-time sampling the scope
    samples sequentially over the wave, whereas with equivalent-time sampling
    the scope captures a sample from a different part of the wave every time
    period. This is perhaps illustrated more clearly
    in~\cref{fig:EquivalentTimeSampling}.

  While equivalent-time sampling offers a much faster sampling rate, it is much
  more complicated to implement.

  \item \textbf{Sample Rate} The rate (in \SI{}{\Hz} or the equivalent
  \textit{samples per second}) at which the oscilloscope can take individual
  digital samples from the signal. Common values range from \SI{10}{\kHz} to
  \SI{1}{\GHz}.

  \item \textbf{Resolution} The number of bits each sample has. Common values
  are 8, 12 and 16 bits. This determines the precision of the oscilloscope, and
  hence the minimum noise.

  \item \textbf{Memory Depth} The number of samples the oscilloscope can store
  at one time. Measured in either words, or bits (for example, if the resolution
  is 8 bits then a depth of 128 words is equivalent to 1024 bits). Intuitively,
  this can be thought of as the horizontal resolution. Common values range from
  100 samples to \SI{10}{M} samples.

  \item \textbf{Triggers Available} The different options to trigger the
    oscilloscope to start capturing samples, with the most common one being edge
    triggering \autocite{PicotechTriggers} (when the signal passes a threshold
    on a rising edge\footnote{A falling edge could also be used, but the type of
    edge is part of the trigger specifications and stays constant}). There are
    also more advanced triggers such as pulse width triggering, which triggers
    the scope when a digital pulse of a certain width is detected. Some
    expensive oscilloscopes can provide extremely complicated triggers: e.g.,
    decoding Ethernet, TCP/IP\footnote{The protocol used for internet
    networking} and HTTP\footnote{The protocol used to transfer web pages over
    the internet} packets from a digial input, and eventually triggering the
    analogue channels when a certain webpage is requested.

  \item \textbf{Input range} The minimum and maximum range of input voltages
    that can be detected by the oscilloscope. A typical value would be from
    \SI{\pm 50}{\mV} to \SI{\pm 50}{\V}. In many cases, this will be a
    relatively small range, but an active scope probe (a test probe with an
    amplifier inside it) will be used to broaden this range.

\end{itemize}

\begin{figure}
  \centering
  
  \caption[Equivalent Time Sampling Diagram]{Diagram illustrating equivalent time sampling ~\autocite{EquivalentTimeSampling}}
  \label{fig:EquivalentTimeSampling}
\end{figure}

\section{Practical Investigations}

\subsection{Oscilloscope Reliability Investigation}
\label{sec:oscilloscopeReliabilityInvestigation}

An existing oscilloscope (in this case, a CRO) will be a vital part of testing
the osilloscope, so it would be wise to test it's accuracy first.

An FPGA\fdeffpga was programmed to produce a square wave at a number of
different frequencies, and the wave was looked at on an oscilloscope. Due to
their completely different nature compared to microcontrollers, FPGAs are
usually programmed in a language called Verilog. While the details are beyond
the scope of this project\footnote{\textcite{VerilogTutorial}, found online at
\url{http://www.asic-world.com/verilog/index.html}, is an excellent resource for
learning Verilog}, let us just say that Verilog is a way of describing the
propogation of signals based on dependencies on both time and other
signals\autocite{VerilogWiki}. See~\cref{lst:flipFlop} for a very simple Verilog
example.

\begin{listing}[H]
  \begin{minted}{verilog}
    always @(posedge) clk begin
      q <= d;
    end
  \end{minted}
  \caption{A simple flip-flop implemented in Verilog}
  \label{lst:flipFlop}
\end{listing}

The FPGA was programmed to perform 50\% duty-cycle clock divisions of the
FPGA's internal\footnote{A high-quality crystal oscillator} \SI{50}{\MHz} clock,
meaning the output frequency could be easily calculated using

\begin{equation}
  f = \frac{\SI{50}{\MHz}}{2^n}
  \label{eq:frequencyCalculationEquation}
\end{equation}

where $n$ is the clock divisor. The accuracy of the crystal oscillator is so
high (an average error value would be around
$0.0005\%$~\autocite{CrystalOscillators}) compared to the accuracy of reading
values from a small oscilloscope screen that we can ignore it in this instance.

The Verilog code used can be seen in~\cref{lst:oscilloscopeTest}.

\begin{listing}[H]
  \inputminted{verilog}{code/oscilloscope_test.v}
  \inputminted{verilog}{code/clock_divider.v}
  \caption{Code used to produce the square wave to test the oscilloscope}
  \label{lst:oscilloscopeTest}
\end{listing}

\subsubsection*{Data}

\begin{figure}[h]
  \centering
  
  \caption[CRO Test Setup]{Equipment setup to test the CRO}
  \label{fig:oscilloscopeTestSetup}
\end{figure}

Seen in~\cref{fig:oscilloscopeTestSetup}, the equipment was setup as described above. Frequency readings
were taken over a number of values of $n$ ranging from 4 to 19. For each
reading, the horizontal and vertical division settinsg were recorded, as well as
the number of divisions counted in one period of the wave. From these, the
measured frequency and amplitude were calculated.

These measured values were compared to the actual frequency (as calculated
by~\cref{eq:frequencyCalculationEquation}) and amplitude (the digital output from the FPGA
ranged from \SI{0}{\V} to it's logic-high level of \SI{3.3}{\V}, leading
to an amplitude of \SI{1.65}{\V}) to find error values for the frequency and
amplitude.

The numerical results of the experiment can be seen
in~\cref{tab:oscilloscopeData}.

With $n=19$, the frequency was low enough that it was very difficult to take a
reading of the number of y divisions per period due to the nature of cathode ray
tubes. This can be seen in the results: the frequency error jumps from less than
$1\%$ to over $90\%$. Because of this, $n=19$ will be considered an anomolous
result and disregarded for the rest of this analysis.

Note the high level of accuracy, particularly with regards to frequency. Due to
previous bad experiences with this oscilloscope, your author was rather
surprised at the results.  Furthermore, almost all of the error can actually be
put down to errors in the human measurement process. Take $n=7$ as an example:
the number of X divisions was measured as $5.1$ to 1 decimal place, giving a
percentage error of $0.98\%$. It is purely coincidental then, that the actual
error is less than half that at $0.39\%$!

\begin{landscape}
  \begin{table}
    \centering
    \scalebox{.9}{
      \begin{tabular}{rSSSSSSSSSS}
        \toprule
        &&&\multicolumn{4}{c}{Measured} &\multicolumn{2}{c}{Actual} &\multicolumn{2}{c}{Error (\%)}\\
        \cmidrule(lr){4-7} \cmidrule(lr){8-9} \cmidrule(lr){10-11}
        {$n$} & {Time/div (\si{\micro\second})} & {Voltage/div (\si{\V})} & {X div} & {Y div} & {Frequency (\si{\kHz})} & {Amplitude (\si{\V})} & {Frequency (\si{\kHz})} & {Amplitude (\si{\V})} & {Frequency} & {Amplitude}\\
        \midrule

        4 & 0.1 & 2 & 3.4 & 2.0 & 2940 & 2.0 & 3120 & 1.65 & 5.88 & 21.21\\
        5 & 0.2 & 2 & 3.1 & 1.8 & 1610 & 1.8 & 1560 & 1.65 & 3.23 & 9.09\\
        6 & 0.5 & 2 & 2.5 & 1.8 & 800 & 1.8 & 781 & 1.65 & 2.40 & 9.09\\
        7 & 0.5 & 2 & 5.1 & 1.7 & 392 & 1.7 & 391 & 1.65 & 0.39 & 3.03\\
        8 & 1 & 2 & 5.1 & 1.7 & 196 & 1.7 & 195 & 1.65 & 0.39 & 3.03\\
        9 & 2 & 2 & 5.1 & 1.7 & 98.0 & 1.7 & 97.7 & 1.65 & 0.39 & 3.03\\
        10 & 5 & 2 & 4.1 & 1.7 & 48.8  & 1.7 & 48.8 & 1.65 & 0.10 & 3.03\\
        12 & 20 & 2 & 4.1 & 1.7 & 12.2 & 1.7 & 12.2 & 1.65 & 0.10 & 3.03\\
        14 & 100 & 2 & 3.2 & 1.7 & 3.12 & 1.7 & 3.05 & 1.65 & 2.40 & 3.03\\
        16 & 500 & 2 & 2.6 & 1.8 & 0.769 & 1.8 & 0.763 & 1.65 & 0.82 & 9.09\\
        19 & 2000 & 2 & 2.7 & 1.7 & 0.185 & 1.7 & 0.0954 & 1.65 & 94.18 & 3.03\\

        \bottomrule
      \end{tabular}
    }
    \caption{Results from oscilloscope accuracy experiment}
    \label{tab:oscilloscopeData}
  \end{table}
\end{landscape}

\subsection*{Qualitative Results}
\label{sec:oscilloscopeSquare}

\begin{figure}[h]
  
  \caption[CRO test waveform]{Not-so-square wave shown on the oscilloscope}
  \label{fig:oscilloscopeTestWave}
\end{figure}

In qualitative terms, however, the oscilloscope was not nearly as accurate.
Looking at~\cref{fig:oscilloscopeTestWave}, one can see that at high frequencies the analogue
bandwidth of the oscilloscope comes into play, causing the digital input to look
very much like a summation of sine waves. In fact, this was still visible to a
lesser extent until $n=12$ (corresponding to a frequency of \SI{12.2}{\kHz}).
This means that while the oscilloscope can be used to accurately determine the
frequency of high-frequency signals, it can't be used to determine the shape of
a signal with any accuracy.

Using the maths detailed in~\cref{sec:squareWaveFourierSeries} we can plot
graphs of square wave approximations up to a certain number of harmonics, as
seen in~\cref{fig:squareWaveApproximations}. Comparing these
to~\cref{fig:oscilloscopeTestWave}, we find that the closest match\footnote{The
  match is not exact because harmonics above the seventh harmonic are present,
  they just have a reduced amplitude.  However by looking at the number of peaks
  in one period of a wave we find the seventh harmonic is the highest one with a
  major component present.} is the seventh harmonic graph. This means we can
  approximate the analogue bandwidth of the oscilloscope as 7 times the
  frequency of the signal, or
  $7\times\SI{3.12}{MHz}=\SI{21.8}{MHz}$\footnote{Checking the datasheet of the
  oscilloscope, we find the quoted bandwidth is \SI{20}{MHz} meaning we are
accurate to within a third of a harmonic, as close as we could hope using this
basic method.}.

\begin{figure}[H]
  \centering
  \scalebox{.95}{
    \begin{tabular}{cc}
      \subfloat[First Harmonic]{
        \begin{tikzpicture}
          \begin{axis}[samples=200]
            \addplot gnuplot{sin(x)};
          \end{axis}
        \end{tikzpicture}
      }
      &
      \subfloat[Third Harmonic]{
        \begin{tikzpicture}
          \begin{axis}[samples=200]
            \addplot gnuplot{sin(x)+1.0/3.0*sin(3*x)};
          \end{axis}
        \end{tikzpicture}
      }
      \\[7ex]
      \subfloat[Fifth Harmonic]{
        \begin{tikzpicture}
          \begin{axis}[samples=200]
            \addplot gnuplot{sin(x)+1.0/3.0*sin(3*x)+0.2*sin(5*x)};
          \end{axis}
        \end{tikzpicture}
      }
      &
      \subfloat[Seventh Harmonic]{
        \begin{tikzpicture}
          \begin{axis}[samples=200]
            \addplot gnuplot{sin(x)+1.0/3.0*sin(3*x)+0.2*sin(5*x)+1.0/7.0*sin(7*x)};
          \end{axis}
        \end{tikzpicture}
      }
      \\[7ex]
      \subfloat[Ninth Harmonic]{
        \begin{tikzpicture}
          \begin{axis}[samples=200]
            \addplot gnuplot{sin(x)+1.0/3.0*sin(3*x)+0.2*sin(5*x)+1.0/7.0*sin(7*x)+1.0/9.0*sin(9*x)};
          \end{axis}
        \end{tikzpicture}
      }
      &
      \subfloat[Eleventh Harmonic]{
        \begin{tikzpicture}
          \begin{axis}[samples=200]
            \addplot gnuplot{sin(x)+1.0/3.0*sin(3*x)+0.2*sin(5*x)+1.0/7.0*sin(7*x)+1.0/9.0*sin(9*x)+1.0/11.0*sin(11*x)};
          \end{axis}
        \end{tikzpicture}
      }
      \\
    \end{tabular}
  }
  \caption[Square Wave Harmonics]{Approximations to a square wave up to certain harmonics}
  \label{fig:squareWaveApproximations}
\end{figure}

\subsection{Bluetooth Distance Test}

As discussed later in~\cref{sec:CommOptions}, Bluetooth will be used to
communicate between the microcontroller and Android device. Because of this, a
practical investigation was undertaken to test the reliability of the Bluetooth
link at different distances.

The Bluetooth module to eventually be used in the final product, an HC06, was
connected to an Arduino (an ATMega microcontroller development board allowing
quick prototyping) and programmed to echo any data sent to it (so if the
character \textit{A} was received by the HC06, it would immediately transmit
back the character \textit{A}). This code can be seen
in~\cref{lst:bluetoothDistanceTestArduino}.

A python\footnote{A very high-level computer programming language that's suited
  for tasks such as this, with libraries for things such as serial
communication. For more information see various online resources.} program was
then written on a laptop computer (with an inbuilt Bluetooth module) to
communicate with the HC06. 384\footnote{3 times 128, and a convenient compromise
between speed and accuracy} bytes were sent out, and the received data compared
to the sent data to produce an accuracy figure. This code can be seen
in~\cref{lst:bluetoothDistanceTestPython}\footnote{For details on how the
  Bluetooth receiver in the laptop was setup as a serial device, see the online
page for this project at \url{http://github.com/hrickards/bioniscope}.}.

\begin{listing}
  \inputminted{c}{code/bluetooth.ino}
  \caption[Bluetooth experiment Arduino code]{The Arduino code used to echo back any characters received via
  Bluetooth}
  \label{lst:bluetoothDistanceTestArduino}
\end{listing}

\begin{listing}
  \inputminted{python}{code/bluetooth.py}
  \caption[Bluetooth experiment python code]{The python code used to measure the accuracy of the Bluetooth link at various distances}
  \label{lst:bluetoothDistanceTestPython}
\end{listing}

This program was run at with the laptop a number of different distances from the
HC06. The results are shown in~\cref{tab:bluetoothData}.
See~\cref{fig:bluetoothExperimentSetup} for a photo of the setup.

\begin{figure}[H]
  
  \caption[Bluetooth Experiment Setup]{Photo showing the equipment used (an
    Arduino connected to an HC06 bluetooth module) for the Bluetooth distance
  experiment}
  \label{fig:bluetoothExperimentSetup}
\end{figure}

\begin{table}
  \centering
  \begin{tabular}{SS}
    \toprule
    {Distance (\si{m})} & {Reliability (\%)}\\
    \midrule

    0.0 & 100.00\\
    1.0 & 100.00\\
    2.0 & 100.00\\
    3.0 & 100.00\\
    4.0 & 100.00\\
    5.0 & 100.00\\
    5.5 & 6.51\\
    6.0 & 0.00\\

    \bottomrule
  \end{tabular}
  \caption{Results from bluetooth distance experiment}
  \label{tab:bluetoothData}
\end{table}

At distances up to and including \SI{5}{\m}, the link was $100\%$
reliable. At \SI{5.5}{\m} that figure dropped dramatically (suggesting that the
connection was lost partway through the test), and at further distances the link
dropped out completely. This means that the oscilloscope should be able to be
used at distances of up to \SI{5}{\m} away from the device.

\section{Numerical Parameters}
\label{sec:numericalParameters}

\subsection*{Frequency and Sampling Rate}

The sampling rate should be as high as feasibly possible to allow the
oscilloscope a wide variety of uses. By \textcite{ShanonNyquist}, the maximum
frequency\footnote{Actually, that's the maximum sinusoidal frequency that we can
sample. By Fourier, all other waveforms can be represented as a sum of
sinusoids, and in reality sampling at 25 times the frequency of the waveform
means that we'll be able to get a high enough amount of detail for most
non-sinusoidal waveforms} that we can sample is half the sampling rate. In
reality, because of the basic real-time sampling method being used it must be at
the very least 25 times less than the sampling rate (allowing just over 12
samples for each half-period of the wave).

ADCs in a DIP\footnote{Electronics components come in a variety of different
packages of many different shapes and sizes. Generally, those that fit in a
breadboard are part of the DIP (dual in-line package) family: e.g., CDIP
(Ceramic DIP) and PDIP (Plastic DIP). Other packages, such as TSOP, are usually
much smaller and suitable only for soldering onto PCBs. While a PCB will be used
for the final oscilloscope, soldering surface-mount chips (a generic term for
all packages smaller than DIP, such as TSOP) requires specialist equipment
unavailable to your author.} package (suitable for breadboards) are not readily
available beyond \SI{2}{\MHz}. Furthermore, the only \SI{2}{\MHz} DIP ADC, the
AD7822, is renowned for being particularly difficult to interface with a
microcontroller.  Instead, an ADC with a maximum sampling rate of \SI{1}{\MHz}
will be used (many DIP ICs can provide this sampling rate).

However, at such a high speed getting the full sampling rate out of an ADC is
not usually possible with a microcontroller (because, for example, a control bit
might have to go high then low again for \SI{20}{\ns}, but a microcontroller
with a \SI{16}{\MHz} clock can only do this in an absolute minimum of
\SI{62.5}{\ns}). So the oscilloscope sampling rate will be specified as at least
\SI{250}{\kHz}.

This means the maximum frequency that should be sampled is
$\frac{\SI{250}{\kHz}}{25} = \SI{10}{\kHz}$.

\subsection*{Bandwidth}

The maximum frequency into the analogue amplification stage will be
\SI{10}{\kHz}, but we also need to take into consideration harmonics (remember,
by Fourier any non-sinusoidal signal can be represented as a sum of sinusoidal
signals of increasing frequency). The effect of this can be seen all too clearly
in ~\cref{fig:oscilloscopeTestWave} To be safe, we will specify a minimum
bandwidth of \SI{1}{\MHz}.

\subsection*{Resolution}

Inaccuracies in the oscilloscope output are more likely to be caused by the
analogue circuitry (in particular, the digital potentiometers are only accurate
to 0.25\%) than a low resolution, so an 8 bit resolution will suffice (this
offers an accuracy of $\approx 0.4\%$, comparable to the digital potentiometer
accuracy). This also means ADCs will be more readily available, as 8 bit DIP
ADCs are significantly more common than higher resolution ones.

\subsection*{Memory Depth}

The memory depth needs to be large enough to have a horizontally precise signal,
but small enough that the samples can easily be stored in the microcontroller.
For these reasons, 1024 words (equivalent to 8192 bits or \SI{1}{\kilo\byte}
with an 8 bit resolution) will be chosen. Most microcontrollers have multiple
\SI{}{\kilo\byte} of RAM, so multiple signals can easily be stored in the
RAM.

\subsection*{Input Range}

For the minimum input range, we'll choose the standard \SI{\pm 50}{\mV}, however
high-bandwidth rail-to-rail op amps are only cheaply available up to \SI{\pm
5}{\V} so for the maximum input range we'll choose \SI{\pm 5}{\V}\footnote{While
  the input to the op amp could be a higher voltage than the supply voltage, a
digital potentiometer will be needed to automatically adjust the gain of the op
amp. These only work up to to the supply voltage.}.

\subsection*{Triggers Available}

For the purposes of this project, no triggering will be used. The oscilloscope
will capture enough samples that the intended use case will be capturing one set
of samples and then analysing those results, rather than capturing a small set
of samples and continuously refreshing that set like a traditional CRO. If
needed, triggering could potentially be implemented in software at a later date.

\section{Communication with Android Device}
\label{sec:CommOptions}

As detailed in ~\cref{sec:user_interface}, an Android device will be used as the
frontend to the oscilloscope. This means that the microcontroller must somehow
communicate with the device.

There are 4 feasible ways that this could be achieved: via WiFi, Bluetooth and
USB.

\subsection*{USB}

This would perhaps be the easiest way to implement the communication. Small
discrete devices, such as the CP2102~\autocite{CP2102}, convert between the
relatively complicated USB protocol and the simple UART\footnote{A UART
(Universal Asynchronous Receiver/Transmitter) is actually a piece of hardware
that takes in parallel data (usually a byte made up of 8 bits) and transmits it
serially according to a certain serial protocol, while also receiving data
serially and outputting it in parallel. While pedantically it's not correct,
we'll use \textit{UART protocol} to refer to this protocol as is commonly done.
There is also a device called a USART, or Universal Synchronous/Asynchronous
Receiver/Transmitter. As the name suggests, these support sending data in both a
synchronous and asynchronous manner, and are very common inside
microcontrollers. However, in this document we'll follow the electronics
industry in taking UART and USART to mean the same thing: transmitting data
asynchronously. As there is no synchronous data transmission required in the
oscilloscope, this will not be an issue.} protocol. In fact, nearly all
microcontrollers now come with a built-in USART interface, so the
microcontroller side of things would be literally `plug and
play'\footnote{Various configuration words would have to be moved to registers
to initialise USART communication at the start of the program, but beyond that
there would simply be registers for writing data, reading data and checking if
data is available to be read}.

On the Android side, the microcontroller would appear as a serial communication
device. The `usb-serial-for-android' library~\autocite{AndroidUSBSerial} would
make it trivial to communicate with the microcontroller from an Android
application via a serial port\footnote{Serial ports are a throwback to the times
when computers had physical RS232 serial connections, over which data could be
sent and received using a very simple protocol. Nowadays, serial ports are
virtual ports that send and receive data over much more complicated protocols
such as USB and Bluetooth.}.

Because the connection is wired, there would be minimal interference so the
speed could potentially go as high as the maximum USB 2.0 bit rate\footnote{Baud
rate figures are not officially available, but it's clear from the bit rate that
it would be extremely high} of \SI{480}{\mega\bit\per\second}.

However, there would be a major disadvantage to this approach: that the
oscilloscope would have to be physically connected to the tablet. This means the
tablet would not be able to be freely moved around while using the oscilloscope.
While a traditional oscilloscope operates this way, allowing wireless connection
would make the oscilloscope much more vertasile: for example, the relatively
cheap oscilloscope hardware could be left permanently connected in a
hard-to-access electronics project, and accessed wirelessly when needed through
the Android tablet.

\subsection*{WiFi}

It would be far beyond the scope of this project to communicate just using a
\SI{2.4}{\GHz} antenna, so instead a discrete WiFi module would be needed. These
have traditionally been relatively expensive\footnote{So much so that for a time
in the mid-2000s it become very common for devices such as amateur robots to
communicate with computers over the \SI{2.4}{\GHz} spectrum, but using a
different protocol to WiFi. This author has not been able to find out why such
devices were significantly cheaper than WiFi devices, but one suspects it is due
to both the complexity of the WiFi protocol and licensing costs required to
implement it.}, however Texas Instruments has recently released the CC3000, a
module much cheaper than the competition.~\autocite{CC3000Cheap}

If the initial project was being created on a custom PCB, then the CC3000 could
simply be included as a component on the PCB. However, the initial prototype is being
created on a breadboard, so a breakout board (a board that contains the CC3000
and an antenna and exposes a digital interface to the CC3000 via pins that can
fit in a breadboard) is needed.

The cheapest, most widely available breakout board is Adafruit's `Adafruit
CC3000 WiFi Breakout with Onboard Ceramic Antenna`. Adafruit are a US-based
company, but the board can be easily obtained in the UK via eBay. However, it
costs \pounds 25.

In terms of complexity, using the CC3000 would be more complicated than using
USB, but not insurmountably so. Libraries exist for both AVR and PIC
microcontrollers to interface with the CC3000, and on the Android side it would
simply require interfacing with a TCP socket\footnote{Again, TCP sockets are
significantly outside the scope of this project, but they can essentially be
thought of as virtual counterparts to physical sockets. A wire can be used to
connect physical sockets together to allow communication between them, and a
protocol such as TCP (the base protocol for the internet) does the same thing
for virtual sockets.} (not significantly more complex than communicating via a
USB serial connection).

One advantage WiFi has over USB is that it offers a wireless connection,
negating the main disadvantage of USB. In addition, it would be able to offer
very fast data transfer rates like USB (also like USB, official baud rate
figures are not available, but the latest standard\footnote{802.11n, which is
supported by most wifi devices nowadays} offers a bit rate of up to
\SI{600}{\mega\bit\per\second}).

However, the main disadvantage is the price. Even with the CC3000, the cheapest
available option, at \pounds 25 the WiFi module would make up a considerable
amount of the total cost of the oscilloscope.

\subsection*{Bluetooth}

Like with WiFi, discrete Bluetooth modules are readily available. These operate
in a similar way to the USB CP2102 --- the microcontroller communicates with the
module via USART, and the Android device via a serial port.

One example of such a module would be a JY-MCU HC-06. Via eBay, these are
available relatively cheaply (about \pounds 5).

This means one key advantage of Bluetooth is simplicity. The inbuilt USART
functionality of the microcontroller can be used on the microcontroller side,
and a Bluetooth serial library used on the Android side. The heavy lifting of
the Bluetooth communication is done by the HC-06 and software built into the
Android device.

Bluetooth obviously offers a wirelesss connection, and should work at distances
ofup to about \SI{10}{\m}. The maximum baud rate supported is
\SI{1.3824}{\mega\bit\per\second}, which is slower than both USB and WiFi but
fast enough for our purposes (remember the oscilloscope takes 8-bit samples at
\SI{250}{\kHz} so the sampling rate is only \SI{4}{\mega\bit\per\second}).

\subsection*{Chosen Solution}
The required wired connection between the oscilloscope and Android device ruled
out USB, leaving WiFi and Bluetooth.

Data transfer speeds are not a big issue in this use case, and Bluetooth's
\SI{1.3824}{\mega\bit\per\second} is certainly fast enough. This means the key
differences between Bluetooth and WiFi are complexity and cost. Bluetooth wins
both of these, so Bluetooth was chosen as the communication method between
microcontroller and Android device.

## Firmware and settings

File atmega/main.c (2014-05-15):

/* ****************************************************************************
   main.c
***************************************************************************** */
#include <util/delay.h>
#include <avr/interrupt.h>

#include "USBUSART.h"
#include "Command.h"
#include "Global.h"
#include "Debugger.h"
#include "Pots.h"
#include "Sampler.h"

int main(void) {
  // Setup the command interface (Bluetooth)
  CommandSetup();

  #ifdef _DEBUG_
    // Setup the debugging interface (USB)
    DebuggerSetup();
  #endif

  // Setup potentiometer control interface
  PotsSetup();

  // Setup sampler (analogue and digital
  SamplerSetup();

  // Enable interrupts
  // sei();

  // Loop forever
  while(1) {
    // Take samples
    SamplerSample();

    // Respond to commands
    CommandRun();

    #ifdef _DEBUG_
      // Send any debugging info over USB
      DebuggerRun();
    #endif
  }
}

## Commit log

2014-02-16 First commit
    Adding git so late because I've had previous bad experience with using
    git for hardware projects (big binary files, etc), but here goes...
    [data.xlsx, enclosure.dxf, enclosure.scad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]
2014-02-21 Add image files for V1 circuit schematic
2014-02-21 Modify enclosure to use normal standoffs, not locking key slot ones
    [enclosure.scad]
2014-02-21 Get digital sampling working on Android app (with real device!)
2014-02-24 Time/sample for digital samples
2014-02-24 Sample from both ADC channels
2014-02-25 Disable interrupts as they're not being used
2014-02-25 Fix issue with PotsSet being undefined
    [Pots.c]
2014-02-25 Fix digital potentiometer SPI com issues
    [SPI.c]
2014-02-25 Get ADC working per the datasheet rather than trial and error. See the README about the ATMega fuses: JTAG must be disabled!
    [ADC.c, monitor.py]
2014-02-25 Split out digital traces
2014-02-26 Add FFT units and get both analogue & digital time/sample's approximately working
    At a future stage, will set up calibration via the app for *much* greater accuracy
2014-02-26 Connect volts/div in android app to scope
2014-02-26 When traces are diabled, they should not be shown on the graph rather than just not being updated
2014-02-27 Switch to a more traditional enclosure box (way too much acrylic needed otherwise)
    [enclosure.dxf, enclosure.scad, enclosure.stl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]
2014-02-27 Switch to a minimum android sdk of 11 (3.0)
2014-02-27 Scan for bluetooth devices and use the one with name HC-06
2014-02-27 Add voltage scale to waveform view & a couple of other UI tweaks
2014-02-27 1 and 0 for digital y axis labels
2014-03-02 UI tweaks (buttons & colours). Min API version now 14.
2014-03-02 Allow user to set bluetooth device name to connect to.
2014-03-02 Log errors at verbose level (so they're not compiled into production) and move calibration constants to user settings
2014-03-03 TODOs and bugfixes in AVR code
    [Sampler.c]
2014-03-03 Enable/disable actually sampling the analogue channels in the ADC
2014-03-10 Toggle capturing traces when they're not enabled

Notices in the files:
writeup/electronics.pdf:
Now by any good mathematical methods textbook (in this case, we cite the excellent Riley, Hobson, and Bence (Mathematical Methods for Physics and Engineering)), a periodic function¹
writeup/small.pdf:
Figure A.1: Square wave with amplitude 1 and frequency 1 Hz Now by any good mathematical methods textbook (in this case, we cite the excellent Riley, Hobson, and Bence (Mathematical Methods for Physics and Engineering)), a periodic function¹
